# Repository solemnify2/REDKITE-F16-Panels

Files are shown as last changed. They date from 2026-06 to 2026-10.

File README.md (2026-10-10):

# REDKITE F16 PANELS

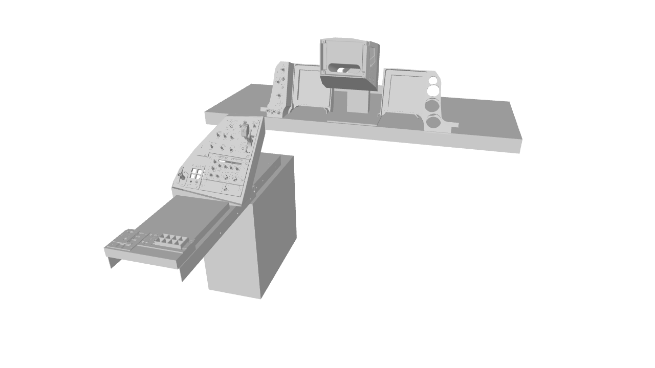
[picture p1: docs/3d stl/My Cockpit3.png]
My Cockpit


VR 전용 F-16 미니멀 데스크핏
**Falcon BMS**(BMS-BIOS)와 **DCS World**(DCS-BIOS) 자동 감지로 패널의 LED 연동

## Design Goals

VR 전용 미니멀 데스크핏을 지향합니다. VR 헤드셋을 쓰고 손을 뻗은 곳에 스위치가 있었으면 하는 생각을 1년 이상 참다가 결국 만들었습니다 ㅠㅠ 실기 1:1 스케일로 제작했습니다. 사용하지 않을 때 쉽게 치울 수 있는 이동식/수납식 구조를 대외적으로 표방(치울지는 모르겠음), 인게임 디스플레이로 충분한 계기류(DED, RWR, 엔진 게이지, HSI 등)는 제작하지 않고 스위치와 LED 위주로 구성했습니다.

## Features

- **Left Aux/MISC Panel 위주로 제작** — 사용 빈도가 높은 Gear, CMDS, TWA, Alt Gear로 구성된 Left Aux Panels과 MISC 패널 위주로 제작
- **이동식/수납식 구조** — Left/Right MFD Enclosure를 독립적으로 미니멀하게 제작하고 ICP 스탠드를 사이에 제작하여 안 쓸 때 MFD 쪽으로 내려 모니터 시야를 확보. 또한, PC 데스크톱 본체 위에 슬라이딩 마운트를 제작하여 Left Aux Console을 거치하고 안 쓸 때 테이블 밑으로 밀어 넣는 구조
- **MCP23017 I2C 확장** — I2C(MCP23017)를 이용하여 새로운 패널을 여러 개 추가 가능. MISC 패널은 MCP23017으로 제작하여 Left Aux Panels의 slave 장치로 동작
- **PWM 백라이트 디밍** — 백라이트가 콕핏 패널의 백미. MOSFET PWM으로 인게임 조명 노브에 연동되는 무단계 밝기 조절. AUX는 USB 3.0 + Step-Up, 콘솔은 별도 12V 어댑터
- **USB Suspend 감지** — PC 절전 시 LED 소등 및 MCU 저전력 모드 진입으로 숙면 지원
- **프로토콜 자동 감지** — BMS-BIOS(바이너리) / DCS-BIOS(바이너리) 자동 판별해서 패널의 LED들을 연동
- **74HC595 시프트 레지스터** — ECM 패널의 S/A/F/T 32개 LED를 3핀으로 구동. 데이지체인이라 칩을 늘려도 핀이 늘지 않음
- **로터리 엔코더** — UHF 백업 무전기의 PRESET 채널과 주파수 5자리를 엔코더 6개로 구현. 1kHz 인터럽트 폴링으로 빠른 회전에도 펄스 유실 없음
- **좌측 콘솔 확장** — 콜드앤다크 스타트에서 쓰는 ECM / ELEC / EPU / AVTR / UHF / ENGINE START / MPO / AUDIO 패널을 두 번째 Teensy로 구성
- **DCS 커버 자동화** — DCS에서 ENG CONT, EPU 스위치 조작 시 커버를 자동으로 열고 닫음 (100ms 선행/후행)

## Devices

독립된 USB 디바이스 2대로 구성됩니다. 각각 별도의 Teensy 4.1과 스케치를 사용하며, Python 브릿지는 VID/PID로 두 대를 동시에 인식해 같은 프레임을 전송합니다.

| 디바이스 | 폴더 | PID | 담당 |
|---|---|---|---|
| **Left Aux + MISC** | `F16_LEFT_AUX_MISC/` | `0x0489` | Gear, CMDS, TWA, Alt Gear, MISC, HMCS, Pedal |
| **Left Console** | `F16_LEFT_CONSOLE/` | `0x048E` | ECM, ELEC, EPU, AVTR, UHF, ENGINE START, MPO, AUDIO 1/2 |

두 스케치 모두 `JOYSTICK_SIZE 64`(Extreme, 128버튼)를 요구하므로 빌드 사이에 `usb_desc.h`를 고칠 필요가 없습니다. PID만 디바이스별로 다르며, 각 스케치가 `#error`로 검증합니다.

## Supported Panels and Input

### Left Aux + MISC (`0x0489`)

| Panel | Type | Description |
|---|---|---|
| Gear | Switch, LED | Landing Gear, Hook, Anti-skid, Landing Light, Gear Warning 등 |
| Alt Gear | Switch | ALT Gear Handle / Reset |
| MISC | Switch, LED (MCP23017) | Master ARM, Laser ARM, RF, Autopilot Pitch/Roll, ECM LED 등 |
| CMDS | Switch, Analog Ladder, LED | RWR, JMR, MWS, JETT, MODE (6-pos), PRGM (5-pos), GO/NO GO/RDY EWS 램프 |
| TWA | Analog Ladder, LED | Threat Warning Aux — Search, Act/Pwr, Low, Power |
| HMCS | Analog | Brightness, Contrast, Symbology 포텐셔미터 3개 |
| Pedal | Analog | Rudder + Left/Right Brake (auto calibration) |

### Left Console (`0x048E`)

| Panel | Type | Description |
|---|---|---|
| ECM | Switch (MCP23017), Analog Ladder, LED (74HC595) | OPR/STBY, XMIT, BIT, RESET + 8버튼 래더 + S/A/F/T 32 LED |
| ELEC | Switch, LED (MCP23017) | MAIN PWR, CAUTION RST + 경고등 8개 |
| EPU | Switch (MCP23017) | OFF / NORM / ON |
| AVTR | Switch (MCP23017) | OFF / AUTO / ON |
| UHF | Switch, **Rotary Encoder ×6**, Analog | FUNCTION(4), MODE(3), SQUELCH, T-TONE, STATUS + PRESET·주파수 5자리 엔코더 + VOL |
| ENGINE START | Switch | JFS (OFF/START1/START2), ENG CONT (PRI/SEC), MAX PWR / NORM / AB RESET, ENG DATA |
| MPO | Switch | Manual Pitch Override |
| AUDIO 1/2 | Analog, Switch (MCP23017) | 볼륨 6개 (COMM CH1/CH2, MSL, THREAT, INTERCOM, ILS) + COMM 1/2 모드 3단 로터리 2개 |

**DX 버튼 61개 / 조이스틱 축 10개**를 사용합니다. DCS에서는 ENG CONT, EPU 커버 자동화용 DX 3개(59~61)가 추가됩니다. 상세 배치는 [docs/PIN_ASSIGNMENT.md](docs/PIN_ASSIGNMENT.md) 참조.

## Hardware

### Panels

패널은 아래 콕핏 빌더 전문 업체에서 구매할 수 있습니다.

- [PC Flights](https://pcflights.com/flight-simulator-cockpit-panels/f-16c-viper-home-cockpit-panels/) — F-16C 패널 전문, 미국/해외 배송 **(본 프로젝트에서 사용한 패널)**

| MISC | Gear | CMDS |
|:----:|:----:|:----:|
| MISC (https://pcflights.com/f-16c-viper-miscellaneous-misc-panel-flight-sim-part/) | Gear (https://pcflights.com/f-16c-viper-landing-gear-panel-flight-simulator-module/) | CMDS (https://pcflights.com/f-16c-viper-cmds-control-panel-module/) |

- [HispaPanel](https://hispapanels.com/tienda/en/20-f-16-fighting-falcon) — 레이저 커팅/각인 패널 키트, 커스텀 제작 가능
- [TEK Creations](https://tekcreations.space/shop/) — LED 백라이트 패널, DCS-BIOS 레디, [Etsy](https://www.etsy.com/shop/TekCreations)에서도 구매 가능

패널은 완제품을 구매하는 대신 3D 프린터로 직접 출력할 수 있습니다. 패널뿐 아니라 구조물(HUD frame 등)도 구할 수 있습니다. 저는 [Cults3D](https://cults3d.com)에서 구했습니다. 아래 참고하세요.

- [Greenisland](https://cults3d.com/en/users/Greenisland/3d-models) — F-16 콕핏 거의 전체 파트 판매
- [Legarsdusofa](https://cults3d.com/en/design-collections/Legarsdusofa/f-16-cockpit-simulator) — F-16 콕핏 거의 전체 파트 판매
- [The_Viper_Project](https://cults3d.com/en/users/The_Viper_Project/3d-models) — 버튼 노브, 스위치 캡, Dsub 캡 등 무료 제공

### Enclosures

`docs/3d stl/` 폴더에 콕핏 패널 인클로저 및 스탠드의 3D 프린트용 STL 파일이 있습니다.
Enclosure는 강도와 가성비를 고려하여 PETG로 제작하였으며, JLC3DP에서는 PETG를 지원하지 않아 PCBWay에서 별도 주문하였습니다.
Stand는 각각 Left/Right Enclosure 뒷면에 부착하는 지지대입니다. 에폭시 접착제로 접합을 권장합니다.
Stand는 두 버전이 있으며, new 버전 사용을 권장합니다.

| Left Stand | Left Stand (new) | Right Stand | Right Stand (new) |
|:----:|:----:|:----:|:----:|
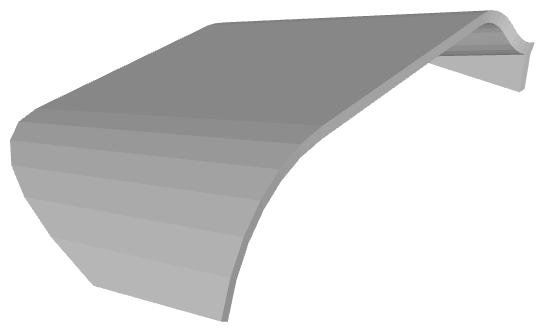
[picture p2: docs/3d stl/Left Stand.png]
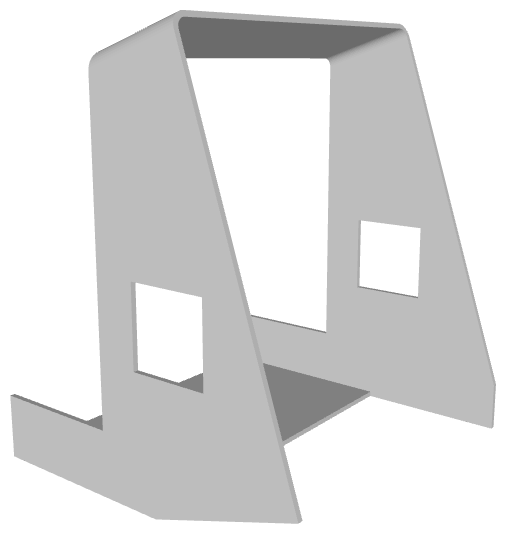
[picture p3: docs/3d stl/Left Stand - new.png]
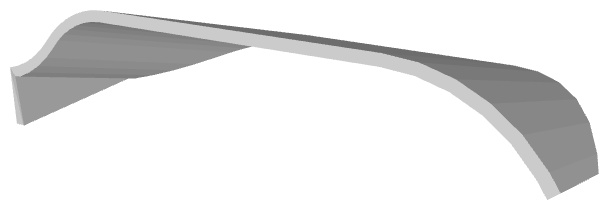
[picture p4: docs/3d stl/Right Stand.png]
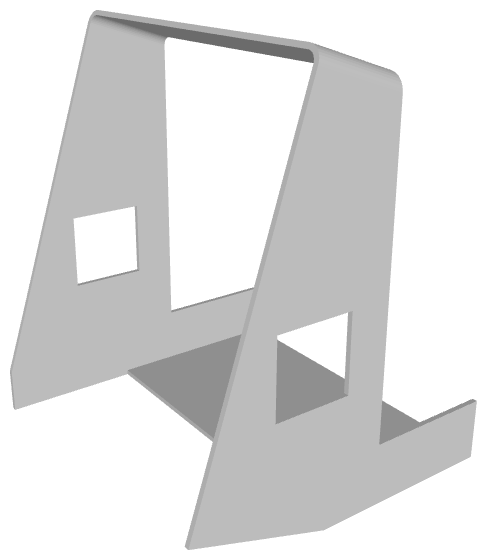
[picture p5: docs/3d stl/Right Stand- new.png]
|  |  |  |  |

| Left Enclosure | Right Enclosure (new) | Enclosure OnePiece |
|:----:|:----:|:----:|
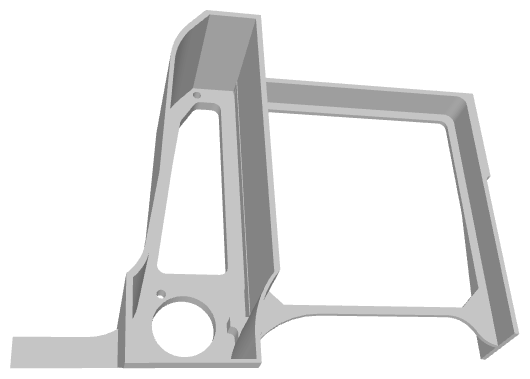
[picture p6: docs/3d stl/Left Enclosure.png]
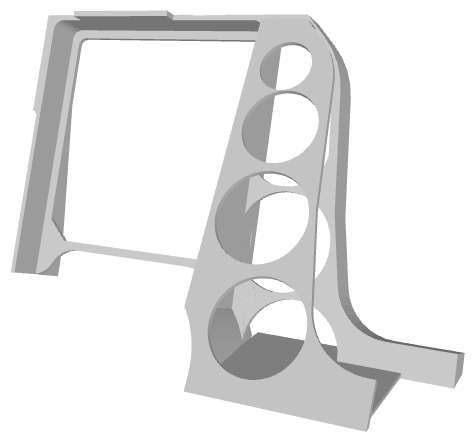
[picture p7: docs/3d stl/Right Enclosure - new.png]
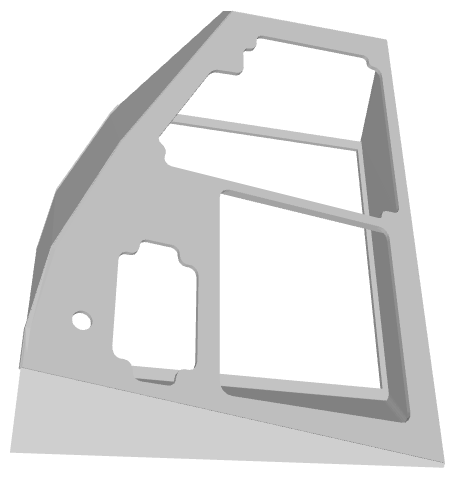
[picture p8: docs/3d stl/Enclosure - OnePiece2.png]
|  |  |  |

> **Note:** Left Enclosure, Right Enclosure의 STL 파일은 Cults3D에서 구매한 모델을 수정하여 제작한 것이므로 저작권 보호를 위해 재배포하지 않습니다. 미리보기 이미지만 참고용으로 포함되어 있습니다.

### MCU

본 프로젝트는 [Teensy 4.1](https://www.pjrc.com/store/teensy41.html)을 사용합니다. 선택 이유:

- **이미 보유하고 있었음** — 가장 큰 이유
- **USB 조이스틱 128버튼 네이티브 지원** — Arduino Mega 등은 USB HID를 지원하지 않아 시리얼 통신 방식으로 제한됨
- **600MHz ARM Cortex-M7** — DCS-BIOS 프로토콜 파싱, LED 제어 등 다중 작업에 충분한 성능
- **VIN 핀을 통한 USB 5V 직접 출력** — 백라이트용 Step-Up 컨버터 전원 공급에 활용

### Components

주요 부품 (AliExpress 주문 기준, 전체 71건):

**스위치류**

| 부품 | 수량 | 비고 |
|---|---|---|
| 토글 스위치 On-Off-On (12mm, 3P) | 20 | |
| 토글 스위치 On-On (12mm, 3P) | 20 | |
| 푸시 스위치 7mm (PBS-110) | 12 | |
| 모멘터리 푸시 스위치 6mm (3핀) | 5 | |
| 택타일 스위치 SMD (6x6x4.3mm) | 20 | |
| 리밋 스위치 (12x6mm) | 10 | |
| 로터리 스위치 SR26 1P12T | 4 | |
| 로터리 스위치 RS16 1P6T / 1P5T | 2 / 2 | |
| 포텐셔미터 10kΩ | 10 | |
| 코리 스위치 | 1 | [HispaPanel](https://hispapanels.com/tienda/en/buttons-encoders/71-korry-type-tactile-switch-momentary.html) |
| 키보드 스위치 (Brown) | 2 | |

**IC / 반도체**

| 부품 | 수량 | 비고 |
|---|---|---|
| MCP23017 I2C I/O Expander | 4 | MISC(AUX) / UHF+AUDIO1 COMM(`0x20`), ELEC+EPU(`0x21`), ECM+AVTR(`0x22`) (콘솔) |
| 74HC595 시프트 레지스터 | 4 | ECM 패널 32 LED 구동 (데이지체인) |
| IRLML6244 N-ch MOSFET | 50 | Step-Up EN 핀 / 백라이트 스위칭 |
| 로터리 엔코더 EC11 (디텐트) | 6 | UHF — PRESET은 20디텐트 권장 |

**LED**

| 부품 | 수량 | 비고 |
|---|---|---|
| 3mm LED Green (백라이트용) | 100 | 고휘도 |
| LED 키트 3mm/5mm Mixed | 300 | Red, Green, Yellow 등 |

**수동 소자**

| 부품 | 수량 | 비고 |
|---|---|---|
| 1/4W 저항 (1K, 4.7K, 10K, 100Ω, 150Ω, 220Ω) | 각 100 | 래더, 풀다운, 풀업 |
| SMD 1206 저항 (220Ω, 2.2K, 10K) | 각 100 | |
| 전해 커패시터 25V (10µF / 100µF) | 각 40 | 바이패스 |
| 세라믹 커패시터 (100nF / 1nF) | 각 100 | 바이패스 |

**커넥터 / 배선**

| 부품 | 수량 | 비고 |
|---|---|---|
| 실리콘 와이어 22AWG 5색 | 50m | |
| Dupont 커넥터 & 점퍼선 | 다수 | 쉘, 핀, F-F 점퍼 |
| Spade 압착 터미널 2.8mm | 200쌍 | 토글 스위치 연결 |
| Pin Header 1x30P | 10 | |
| 수축 튜브 | 750 | |

**모듈 / 기타**

| 부품 | 수량 | 비고 |
|---|---|---|
| Step-Up 컨버터 5V→12V (EN 핀 포함) | 2 | AUX 보드 백라이트 전원 |
| 12V DC 어댑터 (1A) | 1 | **콘솔 보드 백라이트 전용** — LED 40개 때문에 USB 예산 부족 |
| USB 2.0 패널 마운트 커넥터 | 1 | |
| RJ45 패널 마운트 커넥터 / 키스톤 잭 | 7 | 콘솔 보드 케이블 I1, C2, C3, I2, C6, 5 + AUX + MISC |
| Cat5e LAN 케이블 | 7가닥 | **콘솔 보드 신호 배선 전량** — 1, I1/C2/C3, C4/C5, I2/C6, 5 |
| [GX076-30MB](https://www.alibaba.com/product-detail/7-6-Inch-Square-LCD-Display_1601257654342.html) 7.6" Square LCD | 2 | MFD용, Alibaba |
| 자석 15x3mm | 6 | |

상세 주문 내역은 [docs/AliExpress_Orders.xlsx](docs/AliExpress_Orders.xlsx) 참조.

### 소요 비용

| 유형 | 업체 | 내용 | 제품 (USD) | 배송 (USD) |
|---|---|---|----:|----:|
| 패널 | [PC Flights](https://pcflights.com) | MISC / Gear / CMDS 패널 3종 | $133.00 | $30.50 |
| 3D 프린트 (SLA/MJF) | [JLC3DP](https://jlc3dp.com) | 스위치 캡, 노브, LED 레이어, Alt Gear 등 소형 부품 | $63.63 | $20.00 |
| 3D 프린트 (PETG) | [PCBWay](https://www.pcbway.com) | Enclosure, Stand 등 대형 구조물 | $118.75 | ~$50 |
| MCU | [PJRC](https://www.pjrc.com) | Teensy 4.1 | ~$35 | - |
| 전자부품/배선재 | [AliExpress](https://www.aliexpress.com) | MCP23017, 스위치, LED, 저항, 커넥터, 배선재 등 | ~$200 | - |
| 노동력 | - | 약 1달간의 설계, 조립, 프로그래밍 | priceless | - |
| | | **합계** | **~$550** | **~$101** |

**있으면 좋은 것:**

| 유형 | 업체 | 내용 | 제품 | 배송 |
|---|---|---|----:|----:|
| MFD 패널 | [Thrustmaster](https://www.thrustmaster.com/products/mfd-cougar-pack/) | MFD Cougar Pack (2개) | ~$98 | - |
| ICP | [Simgears](https://www.simgears.com/products/f16-icp-se-usb-controller-standalone/) | F16 ICP SE USB Controller | €259 | 별도 |
| MISC 패널 | [TEK Creations](https://www.etsy.com/listing/1829038275/) | F16 MISC Panel Gen3 (백라이트, DCS-BIOS) | A$375 | - |
| Gear 패널 | [TEK Creations](https://tekcreations.space/product/f16-falcon-landing-controller/) | F16 Landing Gear Controller | A$375 | 별도 |
| LCD | [Alibaba](https://www.alibaba.com) | GX076-30MB 7.6" Square LCD (MFD용) x2 | $116 | - |

> 결론: 시간과 노동력을 고려하면 TEK Creations 등 완제품을 사는 게 현명합니다. 직접 만드는 건 취미입니다.

상세 주문 내역: [PCFlights_Orders.xlsx](docs/PCFlights_Orders.xlsx) / [JLC3DP_Orders.xlsx](docs/JLC3DP_Orders.xlsx) / [PCBWay_Orders.xlsx](docs/PCBWay_Orders.xlsx) / [AliExpress_Orders.xlsx](docs/AliExpress_Orders.xlsx)

## Build

### Arduino IDE Setup

1. [Teensyduino](https://www.pjrc.com/teensy/td_download.html) 설치
2. Arduino IDE에서:
   - **Board**: Teensy 4.1
   - **USB Type**: Serial + Keyboard + Mouse + Joystick (복합 디바이스, Windows 자동 인식)
3. 필요 라이브러리:
   - `Wire` (built-in)
   - `Keyboard` (built-in)

### 스위치류와 Teensy 핀 연결

| 보드 | 핀 배치 문서 |
|---|---|
| Left Aux + MISC | [docs/teensy_direct_pins.txt](docs/teensy_direct_pins.txt) |
| Left Console | [docs/PIN_ASSIGNMENT.md](docs/PIN_ASSIGNMENT.md) — 핀표, MCP GPIO 맵, 엔코더, DX 버튼 맵, 패널별 배선, 전원 계통 |

### 저항 래더 (Resistor Ladder)

로터리 스위치(CMDS MODE 6-pos, CMDS PRGM 5-pos)와 TWA 패널 버튼(4개)은 각각 Teensy 아날로그 핀 1개에 저항 래더로 연결합니다. 핀 1개로 여러 버튼을 처리할 수 있어 핀 절약에 효과적입니다.

- 각 포지션마다 **1kΩ 직렬 저항**을 추가하여 고유한 ADC 값을 생성
- **4.7kΩ 풀다운 저항**으로 GND 기준 전압 분배
- ADC 값 = `1023 × 4700 / (k × 1000 + 4700)` (k = 선택된 포지션)
- 소프트웨어에서 tolerance(±25~30) 범위 내 매칭으로 인식
- 사용 핀: A10 (TWA 4버튼), A11 (CMDS MODE 6포지션), A12 (CMDS PRGM 5포지션)

Resistor Ladder 회로도

> `ALLOW_DEBUG = true`로 시리얼 모니터에서 실제 analogRead 값을 확인하고 values[] 배열을 캘리브레이션하세요.

**콘솔 보드의 ECM 래더는 방식이 다릅니다.** PCB가 이미 제작되어 저항값이 고정(10kΩ 체인 + 20kΩ 풀다운)인데, 8단이라 상위 값들의 간격이 좁습니다(FRM 253 / SPL 225 = 28카운트). tolerance 창으로 판별하면 창이 겹쳐 오인식이 나므로 **가장 가까운 값을 고르는 방식(nearest-value)** 에 8회 오버샘플링을 적용했습니다. 창이 겹칠 수 없는 구조라 동시 매칭이 원천적으로 발생하지 않고, 판정 경계(239) 기준 ±14카운트 여유에 노이즈는 ±2 수준입니다.

### MCP23017 패널 추가

Teensy의 다이렉트 핀은 모두 사용 중이므로, 추가 스위치/LED는 MCP23017 I2C 확장으로만 추가할 수 있습니다. MCP23017 하나당 16핀(GPA0–7, GPB0–7)을 제공하며, I2C 주소를 달리하여 최대 8개(0x20–0x27)까지 데이지체인 연결이 가능합니다. 랜선 8중 4핀으로 연결 가능. 기존 쉬프트레지스터 방식은 칩 별로 In/Out이 정해져 있지만 I2C는 칩의 모든 핀을 In/Out으로 설정 가능한 장점이 있음. 또한, 데이지체인 형태로 계속 slave 장치를 추가 가능하므로 teensy에 추가로 핀을 연결할 필요 없음. 향후 콜드앤다크스타트에서 사용하는 손맛을 위한 패널들 (예: ECM, Elec, Snsr, HUD 등) 대응도 마음만 먹으면 가능

```cpp
// MCP23017 패널 스위치 추가 예시 (mcpIdx: MCP 디바이스 번호, pin1: MCP 핀 번호)
{"New Switch",  PNL_MISC,  SW_ON_OFF,  0,  5,  0,  NULL},
//                                      ^   ^
//                               mcpIdx=0  GPA5
```

새 MCP 디바이스를 추가하려면 `mcpDevices[]` 배열에 I2C 주소를 등록하면 됩니다.

### I2C Star 토폴로지 & 핫플러그 보호

MCP23017 패널은 Teensy와 LAN(Cat5e RJ45) 케이블로 연결합니다. 각 패널은 독립 LAN 케이블로 Teensy에 직접 연결하는 **Star 토폴로지**를 사용합니다.

- **Star 연결**: 각 패널이 독립 케이블로 연결되므로, 한 패널의 분리/장애가 다른 패널에 영향을 주지 않음
- **핫플러그 보호**: LAN 커넥터 착탈 시 핀 접촉 순서가 불규칙하므로 보호 회로 필요
  - SDA/SCL 각 100Ω 직렬 저항 (MCP 입력단) — 돌입전류 제한
  - 4.7kΩ × 2 I2C 풀업 저항 — Teensy와 분기점 사이에 배치
  - 10µF + 100nF 바이패스 캡 — MCP23017 VDD 전압 스파이크 흡수
  - RESET 핀 → VDD(3.3V) 직결 — 플로팅 방지
- **I2C 주소**: A0~A2 핀으로 설정, 최대 8개 (0x20~0x27) ([주소 설정표](docs/mcp23017_address.md))
- **상세 사양**: [핫플러그 사양](docs/hotplug_spec.md) / [MISC 패널 사양](docs/misc_panel_spec.md)

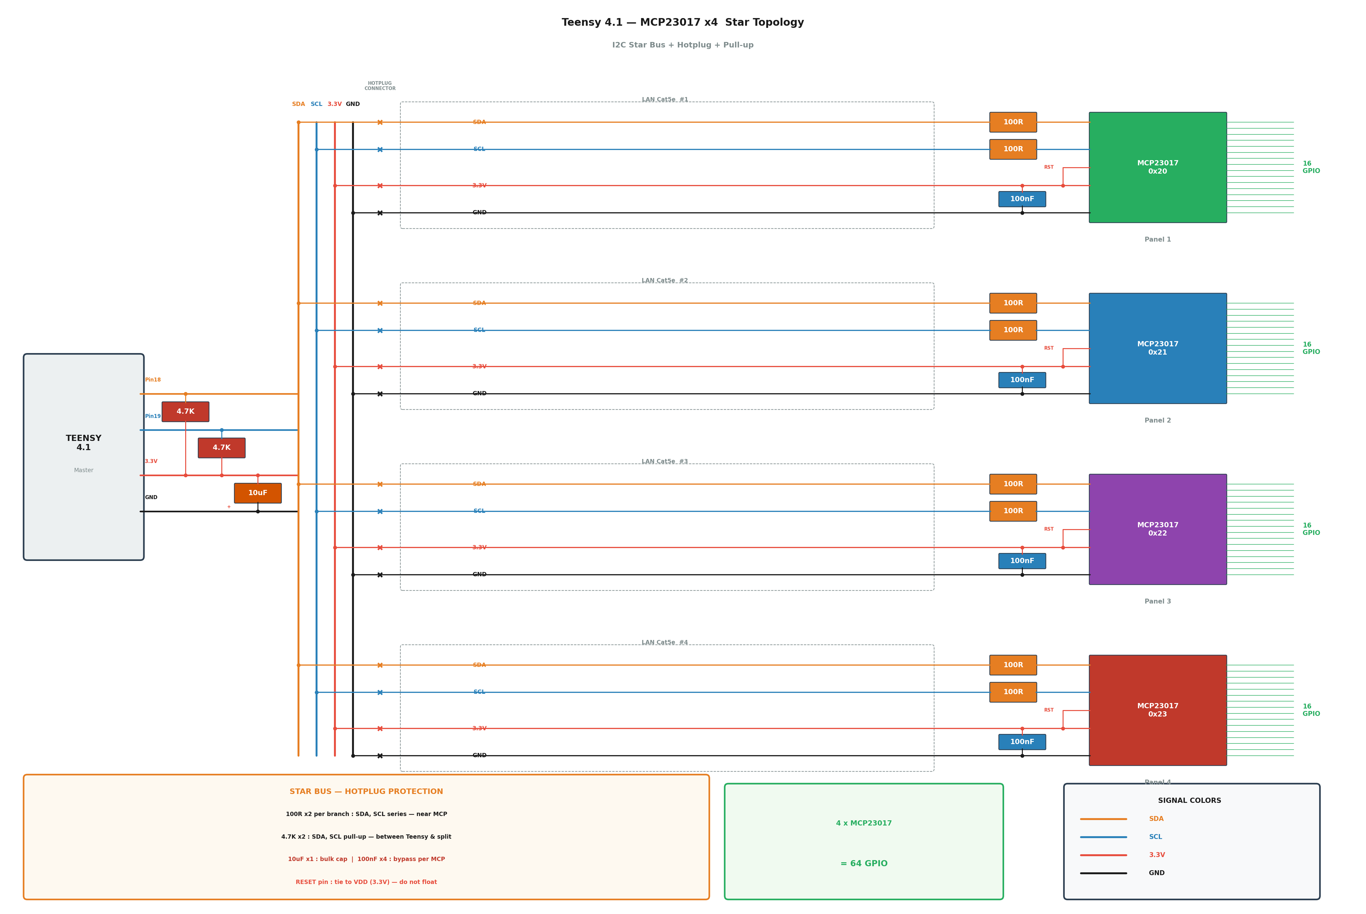
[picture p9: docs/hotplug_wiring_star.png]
I2C Star Topology


### 백라이트

백라이트는 콕핏 패널의 백미이므로 생략할 수 없습니다. **양쪽 보드 모두 MOSFET PWM 디밍**을 지원하며, 인게임 조명 노브에 연동됩니다.

- **전원**:
  - **AUX 보드**: Teensy Vin → Step-Up 컨버터 5V→12V. USB 3.0 전력 예산(900mA) 내 운용
  - **콘솔 보드**: 별도 12V DC 어댑터 (LED 40개로 USB 예산 초과). 어댑터 GND와 Teensy GND를 반드시 연결
- **PWM 디밍**: Teensy pin 13 → 1kΩ → MOSFET Gate, 10kΩ 풀다운. MOSFET Drain←LED-RTN, Source→GND. `analogWrite` 1kHz PWM으로 0~255 무단계 밝기 조절
- **인게임 연동**:
  - BMS: `instrLight` → 브릿지가 `ledBits` byte 2(bits 16~23)로 brightness 0~255 전송
  - DCS: Teensy가 직접 처리. `LIGHT_INST_PNL`(0x4484) 0~65535 → >>8 → PWM 0~255
- **오프라인 수동 제어**:
  - **AUX 보드**: DN LOCK REL을 누른 채 HMCS Symbology 포텐셔미터(A15)로 밝기 조절 (방향 반전)
  - **콘솔 보드**: UHF STATUS를 누른 채 UHF VOL 포텐셔미터(A9)로 밝기 조절
- **LED**: 3V / 20mA 녹색 고휘도 3mm LED
- **회로 구성**: LED 3개 + 220Ω 저항 1개로 구성된 직렬 스트링을 최대 15개까지 병렬로 분산 배치 (20mA × 15 = 300mA @ 12V)
- **패널 구조**: PC Flights 패널은 2중 구조. 전면은 흰색 판넬에 검정 도색 + 글자 흰색 각인, 후면은 투명 패널
- **배치 방법**: 후면 투명 패널 뒤쪽에서 LED를 쏴주면 전면 각인 글자가 빛남. 전력 제한으로 LED 45개 이내로 사용해야 하므로, 후면 패널에 밀착시키지 않고 1~2cm 간격을 두어 빛이 넓게 퍼지도록 배치
- **패널별 배치**: MISC 15개(5스트립) / Gear 18개(6스트립) / CMDS 12개(4스트립), 총 45개(15스트립)

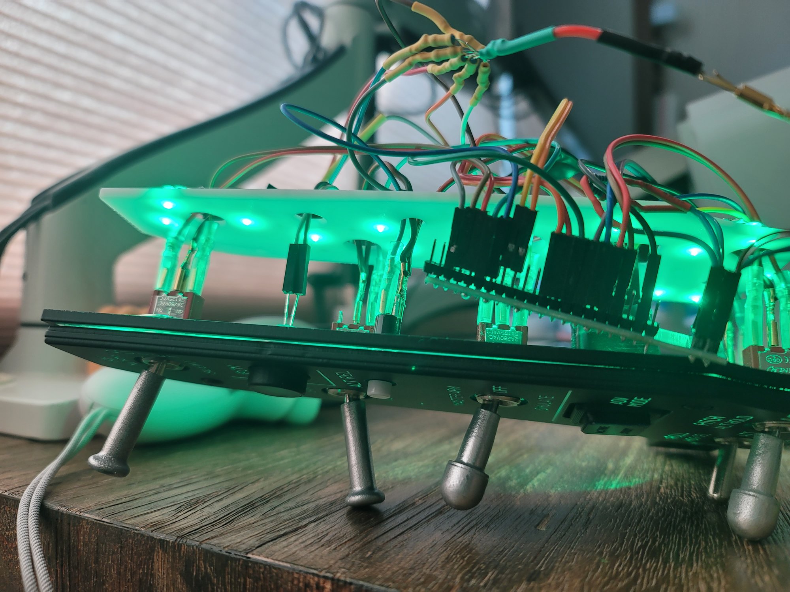
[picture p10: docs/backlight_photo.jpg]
Backlight LED 배치 — 후면 투명 패널에서 1~2cm 간격

- **전력 계산**: Teensy 4.1(~100mA) + MCP23017(~1mA) + 백라이트(300mA @ 12V) 감안하여 USB 3.0 전력 예산(900mA @ 5V) 내에서 운용

> **왜 MOSFET이 필요한가?** AUX 보드: Step-Up EN 핀은 5V 도메인이라 3.3V Teensy GPIO로 직접 제어가 안 됨. 콘솔 보드: 12V 어댑터를 직접 제어할 수단이 필요. 양쪽 모두 N-ch MOSFET(IRLML6244)을 low-side switching으로 사용하며, PWM으로 LED 밝기를 무단계 조절합니다.

> **Note:** EN 핀 특성(GND=ON, Float=OFF)은 Aliexpress에서 구매한 Step-Up 모듈 기준이며, 다른 제조사/모듈은 EN 핀 동작이 다를 수 있습니다. 사용 전 데이터시트를 반드시 확인하세요.

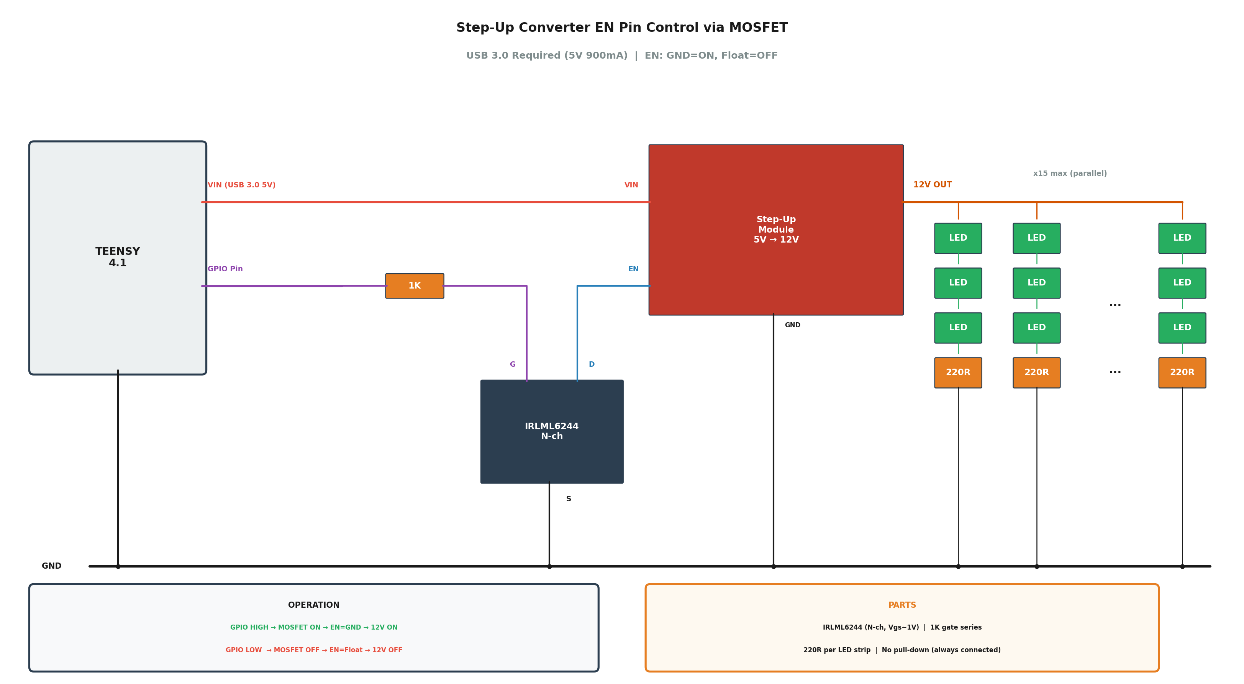
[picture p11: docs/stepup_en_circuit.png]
Step-Up EN Circuit


> COB LED 스트링도 검토했으나, 모든 패널에 두르려면 소모 전력이 높아 별도 전원 공급 없이는 운용이 어려워 포기했습니다.

## 스위치 Customization

스위치/LED 등 하드웨어 변경 시 각 `.ino`의 **HARDWARE CONFIGURATION** 섹션의 config 배열만 수정하면 됩니다. 패널을 비활성화하려면 해당 항목을 주석 처리하면 됩니다. 조이스틱 버튼 번호는 런타임에 자동 재할당됩니다.

| 배열 | 용도 | 보드 |
|---|---|---|
| `switches[]` | 디지털 스위치 (직결 / MCP) | 공통 |
| `analogBtnArrays[]` | 저항 래더 그룹 | 공통 |
| `mcpDevices[]` | MCP23017 I2C 주소 | 공통 |
| `leds[]` | LED (직결 / MCP) | 공통 |
| `pots[]` | 포텐셔미터 → 조이스틱 축 | 공통 |
| `encoders[]` | 로터리 엔코더 | 콘솔 |
| `srMap[]` | 74HC595 논리→물리 출력 리맵 | 콘솔 |

```cpp
// 스위치 추가 예시
const SwitchDef switches[] = {
  // name         panel        type         mcpIdx  pin1  pin2  stateRef
  {"My Switch",   PNL_GEAR,    SW_ON_OFF,      -1,    5,    0,  NULL},
};

// 아날로그 버튼 배열 추가 예시
const AnalogBtnArrayDef analogBtnArrays[] = {
  // groupName    panel      pin  numBtn  btnNames       values         tolerance
  {"My Buttons",  PNL_CMDS,  A11, 4,      myBtnNames,    myBtnValues,   20},
};
```

### Extreme 조이스틱 설정

Windows의 기본 Joystick은 32버튼까지만 지원하지만, Teensyduino의 Extreme Joystick 모드는 128버튼을 지원합니다. AUX 보드가 49버튼, 콘솔 보드가 56버튼을 쓰므로 **두 스케치 모두** 이 모드가 필요합니다. Teensy 빌드 전 `%LOCALAPPDATA%\Arduino15\packages\teensy\hardware\avr\<version>\cores\teensy4\usb_desc.h`에서 `JOYSTICK_SIZE`를 `64`로 변경:

```c
#define JOYSTICK_SIZE         64    //  12 = normal, 64 = extreme joystick
#define PRODUCT_ID            0x0489  // AUX 보드 / 콘솔 보드는 0x048E
```

두 보드가 `JOYSTICK_SIZE`를 공유하므로 빌드 사이에 이 값을 고칠 필요는 없고, **`PRODUCT_ID`만 디바이스에 맞게 바꿔** 빌드합니다. 값이 틀리면 각 스케치의 `#error`가 빌드를 막아줍니다.

> **축은 6개가 아니라 23개입니다.** Extreme 모드는 명명 축 6개(X / Y / Z / Xrotate / Yrotate / Zrotate)에 더해 `Joystick.slider(1..17)`을 제공합니다(`usb_joystick.h`의 `analog16(6..22)`). 콘솔 보드의 볼륨 포트 7개는 명명 축 6개 + `slider(1)`에 배정했으며, 16채널이 남아 있습니다.

조이스틱 버튼은 런타임에 순차 번호가 자동 부여되지만, 인게임 내의 키 매핑은 직접 해주셔야 합니다. 페달은 러더 + 독립 브레이크를 합성하며 자동 캘리브레이션을 지원합니다. 현재 배치는 [docs/joystick.txt](docs/joystick.txt) 참조.

### Left Console 보드 고유 사항

콘솔 보드(`F16_LEFT_CONSOLE/`)는 AUX 보드와 몇 가지가 다릅니다.

**로터리 엔코더 (UHF 6개)**
1kHz `IntervalTimer` ISR에서 쿼드러처를 디코딩하고, 메인 루프가 디텐트를 그대로 CW/CCW DX 버튼 펄스 큐로 배출합니다. 자리 순환·경계 처리(예: 100MHz 자리는 2~3뿐)는 BMS 가 자체적으로 하므로 스케치는 값을 추적하지 않습니다. 엔코더는 **MCP23017에 올릴 수 없습니다** — I2C 폴링 주기로는 펄스를 놓칩니다. 이 때문에 메인 루프도 50ms → **10ms(100Hz)** 로 올렸습니다.

**저항 래더 — 최근접값 판별**
ECM 8버튼 래더는 PCB가 이미 제작되어 값이 고정(10kΩ 체인 + 20kΩ 풀다운)인데, 상위 두 값(FRM 253 / SPL 225)의 간격이 28카운트뿐입니다. tolerance 창 방식으로는 겹쳐서 오인식이 나므로 **가장 가까운 값을 고르는 방식**으로 판별하고 8회 오버샘플링을 적용했습니다. 판정 경계가 239라 ±14카운트 여유가 확보되고, 노이즈는 ±2 수준입니다.

**74HC595 32/32 소진**
칩을 추가하면 BMS-BIOS 프레임의 `srData` 32비트를 넘으므로 `BB_FRAME_PAYLOAD`, 양쪽 `BmsBiosParser.h`, `bmsbios_bridge.py`를 모두 수정해야 합니다.

**백라이트는 별도 12V 어댑터 + PWM 디밍**
콘솔 보드는 인디케이터 LED만 40개(ECM 32 + ELEC 8)라 USB 900mA로는 백라이트까지 감당이 안 됩니다. 12V 어댑터를 따로 쓰고 Step-Up 컨버터는 생략합니다. **어댑터 GND와 Teensy GND를 단일점으로 반드시 연결**해야 MOSFET 게이트 기준이 성립합니다. 오프라인 수동 밝기 조절은 UHF STATUS + UHF VOL 포텐셔미터로 가능합니다.

배선·핀 배치 상세는 [docs/PIN_ASSIGNMENT.md](docs/PIN_ASSIGNMENT.md) 참조.

### Upload

Arduino IDE에서 해당 `.ino`를 열고 Upload합니다. `usb_desc.h`의 `PRODUCT_ID`가 보드와 일치하는지 먼저 확인하세요.

| 보드 | 파일 | PRODUCT_ID |
|---|---|---|
| Left Aux + MISC | `F16_LEFT_AUX_MISC.ino` | `0x0489` |
| Left Console | `F16_LEFT_CONSOLE.ino` | `0x048E` |

## DCS-BIOS / BMS-BIOS Protocol Support

스위치/버튼 입력은 USB Joystick으로 직접 전달되지만, LED 상태는 시뮬레이터에서 받아와야 합니다. Python 브릿지가 시뮬레이터의 내부 데이터를 읽어 시리얼로 Teensy에 전송하고, Teensy는 수신된 프로토콜(BMS-BIOS / DCS-BIOS)을 자동 감지하여 LED를 제어합니다. 시뮬레이터 전환 시 타임아웃(AUX 6초 / 콘솔 3초) 후 자동 재감지. 오프라인(시뮬레이터 미연결) 시 AUX 보드는 Landing Gear 스위치 상태에 따라 Gear LED 3개를 시뮬레이션하고(2초 딜레이), 기어 상태 변경 시 Gear Warn LED를 5초간 점등합니다. 콘솔 보드는 오프라인에서 모든 LED를 소등합니다.

### Falcon BMS (BMS-BIOS)

- 바이너리 프로토콜, `0xAA 0xBB` sync 2바이트로 자동 감지
- Python 브릿지(`tools/bmsbios_bridge.py`)가 BMS 공유 메모리에서 LED 상태를 읽어 Teensy로 전송
- BMS 실행 전에 bridge를 먼저 실행해도 안전 (공유 메모리 생성하지 않음)
- 브릿지는 VID/PID로 **두 디바이스를 동시에 인식**해 각각에 맞는 프레임을 보냅니다
- 프레임: `sync(2) + ledBits(4) + srData(4) + uhfFreq(4) + uhfPreset(1) + XOR(1)` = 16바이트. AUX는 `ledBits`만, 콘솔은 `ledBits` + `srData`(ECM 32 LED) + `uhfFreq`/`uhfPreset`(UHF 7-seg)를 사용하며, **ledBits byte 2(bits 16~23)가 백라이트 brightness**로 양쪽 공통입니다
- 사용법:
  ```
  pip install pyserial
  python tools/bmsbios_bridge.py                          # 두 디바이스 자동 감지
  python tools/bmsbios_bridge.py COM4:AUX COM5:CONSOLE    # 수동 지정
  python tools/bmsbios_bridge.py --debug                  # LightBits 실시간 출력
  ```

> **참고 — Why not F4ToSerial?** 이전 버전에서는 [F4ToSerial](https://github.com/Music-Junky/F4ToSerial)을 사용했으나, F4TS는 Teensy의 다이렉트 핀만 지정 가능하고 MCP23017 등 I2C 확장 핀을 지원하지 않는 문제가 있어 BMS-BIOS로 대체했습니다. 부수적으로 JSON 파싱 오버헤드 제거, ArduinoJson 의존성 제거 등 소소한 이점도 기대할 수 있습니다 (체감 차이는 미지수). DCS-BIOS/BMS-BIOS 프로토콜을 직접 구현했으므로 향후 DCS나 BMS 업데이트로 주소/오프셋이 변경되면 직접 수정이 필요하지만, 소스가 명확하고(`docs/protocol_reference.txt` 참조) 수정 범위도 작아 큰 부담은 아닙니다. 게다가 [Claude Code](https://claude.com/claude-code)도 있으니 든든합니다.

### DCS World (DCS-BIOS)

- 바이너리 프로토콜, `0x55` sync 4바이트로 자동 감지
- DCS-BIOS 설치 및 UDP 브릿지(`tools/dcsbios_bridge.py`) 필요
- 사용법:
  ```
  pip install pyserial
  python ../tools/dcsbios_bridge.py             # COM port auto-detect
  ```

## Project Structure

```
REDKITE-F16-Panels/
├── F16_LEFT_AUX_MISC/             # Teensy 4.1 (PID 0x0489)
│   │                              #   Gear, CMDS, TWA, Alt Gear, MISC, HMCS, Pedal
│   ├── F16_LEFT_AUX_MISC.ino
│   ├── BiosHandler/               # DcsBiosParser.h / BmsBiosParser.h
│   ├── CLAUDE.md
│   └── name.c
├── F16_LEFT_CONSOLE/              # Teensy 4.1 (PID 0x048E)
│   │                              #   ECM, ELEC, EPU, AVTR, UHF,
│   │                              #   ENGINE START, MPO, AUDIO 1/2
│   ├── F16_LEFT_CONSOLE.ino
│   ├── BiosHandler/
│   ├── Display/                   # Max7219Display.h (UHF 7-seg)
│   ├── CLAUDE.md
│   └── name.c
├── tools/                         # Python 브릿지 (BMS/DCS → Teensy)
│   ├── bmsbios_bridge.py          #   VID/PID로 두 디바이스 동시 인식
│   ├── dcsbios_bridge.py
│   ├── reset_joystick_name.bat
│   └── backup_to_synology.ps1
├── docs/                          # 배선도, 사양서, 프로토콜 참조
│   ├── PIN_ASSIGNMENT.md          #   콘솔 보드 핀·배선 상세 (표)
│   ├── LEFT_CONSOLE_PIN_TREE2.md  #   콘솔 보드 연결 트리 (케이블·패널 단위)
│   ├── LEFT_AUX_MISC_LAN_WIRING.md #  AUX↔MISC LAN 배선도
│   ├── backlight_spec.md / hotplug_spec.md / stepup_en_control.md
│   └── 3d stl/                    #   3D 프린트용 STL 파일
├── CLAUDE.md                      # Claude Code 가이드
└── README.md
```

## License

This project is licensed under the [MIT License](LICENSE).

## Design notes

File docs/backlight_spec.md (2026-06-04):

# Backlight System Specification

## Power Budget
- USB 3.0: 900mA @ 5V
- Teensy 4.1 consumption: ~100mA @ 5V
- MCP23017: ~1mA (negligible)
- LED backlight budget: ~800mA @ 5V
- MT3608 step-up: 5V → 12V (85% efficiency)
- Max 12V output: 283mA → **18 strips (54 LEDs) safe limit**

## LED Strip
- Green 3V 20mA high-brightness LED
- 3-series per strip + 220Ω resistor
- Strip current: (12V - 9V) / 220Ω = **13.6mA** (68% of 20mA rating)
- Strip count is freely adjustable (parallel connection, no circuit change needed)

| Resistor | Current | Brightness |
|---|---|---|
| 150Ω | 20.0mA | 100% (max, shorter life) |
| **220Ω** | **13.6mA** | **68% (recommended)** |
| 330Ω | 9.1mA | 45% |
| 470Ω | 6.4mA | 32% |
| 1kΩ | 3.0mA | 15% |

## Current Configuration
- Main panel: 10 strips (30 LEDs) = 136mA @12V
- MISC panel: 3 strips (9 LEDs) = 41mA @12V
- Total: 13 strips, 39 LEDs, 177mA @12V, ~538mA @5V

## MT3608 Step-Up Converter
- Input: 5V (Teensy VIN)
- Output: 12V
- Switching frequency: 1.2MHz
- Place 2~3cm away from Teensy MCU and I2C lines (EMI)
- Do not route I2C lines parallel to/over inductor
- Input/output caps included on module

---

## Circuit Options (4 variants)

### Option A: PWM Dimming (MOSFET ×2)
**File:** `backlight_circuit.png` / `draw_circuit.py`

- MOSFET: IRLML6344 (SOT-23, N-ch, Vgs(th) ~1V) × 2
- 1 per panel, low-side switching
- Gate: 1kΩ series resistor
- Pull-down: 10kΩ Gate→GND (hotplug protection)
- PWM dimming: Teensy Pin 0 → `analogWrite(0, 0~255)`
- MISC panel 3.3V: AMS1117-3.3 (12V → 3.3V) + 10µF × 2

| Pin | Signal | Pair |
|-----|---|---|
| 1 | SDA | Pair 1 (Orange) |
| 2 | GND | Pair 1 |
| 3 | SCL | Pair 2 (Green) |
| 6 | GND | Pair 2 |
| 4 | 12V | Pair 3 (Blue) |
| 5 | 12V | Pair 3 |
| 7 | PWM | Pair 4 (Brown) |
| 8 | GND | Pair 4 |

**Pros:** 0~100% 무단계 디밍, PWM+GND 꼬임쌍으로 간섭 없음
**Cons:** 부품 가장 많음 (AMS1117 + caps + MOSFET ×2 + 저항 ×4)

### Option B: Always ON (No MOSFET)
**File:** `backlight_circuit_no_pwm.png` / `draw_circuit_no_pwm.py`

- MOSFET 없음, LED cathode → GND 직결
- 밝기는 저항값으로만 결정 (고정)
- MISC panel 3.3V: AMS1117-3.3 (12V → 3.3V) + 10µF × 2

| Pin | Signal | Pair |
|-----|---|---|
| 1 | SDA | Pair 1 (Orange) |
| 2 | GND | Pair 1 |
| 3 | SCL | Pair 2 (Green) |
| 6 | GND | Pair 2 |
| 4 | 12V | Pair 3 (Blue) |
| 5 | 12V | Pair 3 |
| 7 | GND | Pair 4 (Brown) |
| 8 | GND | Pair 4 |

**Pros:** 단순, MOSFET/게이트 저항 6개 절감
**Cons:** 디밍 불가

### Option C: MCP23017 Only (No Backlight)
**File:** `backlight_circuit_mcp_only.png` / `draw_circuit_mcp_only.py`

- 백라이트 없음, MT3608 불필요, AMS1117 불필요
- Teensy 3.3V (250mA max) → LAN → MCP23017 직접 구동
- 100nF 바이패스 캡만 필요

| Pin | Signal | Pair |
|-----|---|---|
| 1 | SDA | Pair 1 (Orange) |
| 2 | GND | Pair 1 |
| 3 | SCL | Pair 2 (Green) |
| 6 | GND | Pair 2 |
| 4 | 3.3V | Pair 3 (Blue) |
| 5 | 3.3V | Pair 3 |
| 7 | GND | Pair 4 (Brown) |
| 8 | GND | Pair 4 |

**Pros:** 최소 부품, 최소 전력
**Cons:** 백라이트 없음

### Option D: 12V Backlight + 3.3V Direct (No AMS1117)
**File:** `backlight_circuit_12v_3v3.png` / `draw_circuit_12v_3v3.py`

- MT3608 12V → 양쪽 패널 백라이트 (always on)
- Teensy 3.3V → LAN → MCP23017 직접 구동 (AMS1117 불필요)
- MOSFET 없음 (PWM 신호선 자리에 3.3V 배정)

| Pin | Signal | Pair |
|-----|---|---|
| 1 | SDA | Pair 1 (Orange) |
| 2 | GND | Pair 1 |
| 3 | SCL | Pair 2 (Green) |
| 6 | GND | Pair 2 |
| 4 | 12V | Pair 3 (Blue) |
| 5 | 12V | Pair 3 |
| 7 | 3.3V | Pair 4 (Brown) |
| 8 | GND | Pair 4 |

**Pros:** AMS1117 + 전해캡 2개 절감, 백라이트 있음
**Cons:** PWM 디밍 불가 (LAN 핀 부족), 3.3V+GND 꼬임쌍 (전용 GND 있음)

---

## Option Comparison

| | A: PWM | B: Always ON | C: MCP Only | D: 12V+3.3V |
|---|---|---|---|---|
| Backlight | O (dimmable) | O (fixed) | X | O (fixed) |
| MT3608 | O | O | X | O |
| AMS1117 | O | O | X | **X** |
| MOSFET | 2 | 0 | 0 | 0 |
| PWM dimming | O | X | - | X |
| Parts count | Most | Medium | Least | Medium-Low |
| 5V draw | ~538mA | ~538mA | ~100mA | ~538mA |

## MISC Panel Components by Option

### Option A (PWM)
| Part | Value | Purpose |
|---|---|---|
| MCP23017 | 0x20 | I2C GPIO expander |
| AMS1117-3.3 | SOT-223 | 12V → 3.3V LDO |
| Electrolytic cap | 10µF ×2 (25V) | AMS1117 in/out |
| Resistor | 100Ω ×2 | I2C hotplug protection |
| Resistor | 220Ω ×3 | LED current limiting |
| MOSFET | IRLML6344 | Backlight switching |
| Resistor | 1kΩ | MOSFET gate series |
| Resistor | 10kΩ | MOSFET gate pull-down |

### Option D (12V+3.3V, recommended)
| Part | Value | Purpose |
|---|---|---|
| MCP23017 | 0x20 | I2C GPIO expander |
| Ceramic cap | 100nF | MCP23017 bypass |
| Resistor | 100Ω ×2 | I2C hotplug protection |
| Resistor | 220Ω ×3 | LED current limiting |

## Main Panel Components (backlight options)
| Part | Value | Purpose |
|---|---|---|
| MT3608 module | 5V→12V | Step-up converter |
| Resistor | 220Ω ×10 | LED current limiting |
| MOSFET (Option A only) | IRLML6344 | PWM switching |
| Resistor (Option A only) | 1kΩ | Gate series |
| Resistor (Option A only) | 10kΩ | Gate pull-down |

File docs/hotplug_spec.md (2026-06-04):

# LAN Hotplug & PWM Specification

## Overview
Teensy 4.1 ↔ MISC Panel (MCP23017) 간 LAN (Cat5e RJ45) 연결 시 핫플러그 보호 및 PWM 디밍 설계.
3.3V와 12V는 완전 분리 (3.3V = MCP 전용, 12V = 백라이트 전용).

## Hardware

### I2C Protection
| Part | Value | Location | Purpose |
|---|---|---|---|
| Resistor | 100Ω | SDA 직렬 (MISC 입력단) | 돌입전류 제한, 래치업 방지 |
| Resistor | 100Ω | SCL 직렬 (MISC 입력단) | 돌입전류 제한, 래치업 방지 |

- LAN 연결 시 핀 접촉 순서가 불규칙 → 100Ω이 과도 전류 제한
- I2C 100~400kHz 통신에 영향 거의 없음

### Power Protection (MCP23017 VDD)
| Part | Value | Location | Purpose |
|---|---|---|---|
| Electrolytic cap | 10µF (10V+) | MCP23017 VDD-GND | 핫플러그 전압 스파이크 흡수 |
| Ceramic cap | 100nF | MCP23017 VDD-GND (핀 근접) | 고주파 노이즈 필터 |

#### Connection
```
3.3V ──┬──┬── MCP23017 VDD
       │  │
     10µF 100nF
       │  │
GND  ──┴──┴── MCP23017 GND
```
- 두 캡 모두 3.3V-GND 사이 병렬
- 100nF을 MCP23017 핀에 더 가까이 배치
- 10µF 전해캡은 극성 주의 (+를 3.3V 쪽)

### Capacitor Sizing
| 용량 | 판단 |
|---|---|
| 10µF | 충분 (MCP23017 ~1mA) |
| 47µF | AMS1117 사용 시 12V PWM 리플 흡수용 (현재 불필요) |
| 100µF | 과잉 — 충전 돌입전류 증가, 이점 없음 |

현재 3.3V/12V 완전 분리 → 12V PWM 리플이 MCP에 영향 없음 → **10µF이면 충분**

## Software

### MCP23017 재초기화
```cpp
// 주기적으로 MCP23017 연결 확인 (예: 500ms 간격)
Wire.beginTransmission(0x20);
if (Wire.endTransmission() == 0) {
    // MCP23017 detected → reinitialize
    mcp.begin();
}
```
- LAN 분리 후 재연결 시 MCP23017 레지스터가 리셋됨
- I2C 응답 확인 후 재초기화 필요

## Not Required
| Part | Reason |
|---|---|
| TVS diode (P6KE15A) | 3.3V/12V USB 전원 수준, 과전압 파괴 위험 없음 |
| Ferrite bead | 저전류(~1mA), 노이즈 문제 없음 |
| 100µF+ 대용량 캡 | 과잉, 돌입전류만 증가 |
| Gate pull-down 10kΩ | MOSFET 없는 경우 불필요 (Option D) |

---

## PWM Dimming

### Overview
- Teensy Pin 0 → `analogWrite(0, 0~255)` → MOSFET Gate → LED 밝기 조절
- MOSFET: IRLML6344 (SOT-23, N-ch, Vgs(th) ~1V, logic-level)
- Low-side switching: LED cathode(−) → MOSFET Drain, MOSFET Source → GND

### Teensy 4.1 PWM
- Pin 0: PWM 출력 가능 (FlexPWM)
- 기본 주파수: ~4.482kHz
- 해상도: 8-bit (0~255)
- `analogWrite(0, 0)` = OFF, `analogWrite(0, 255)` = 최대 밝기

### MOSFET Circuit (per panel)
```
Teensy Pin0 ──→ 1kΩ ──→ Gate (G)
                         │
                        10kΩ (pull-down)
                         │
                        GND

12V → 220Ω → LED×3 → Drain (D)
                      Source (S) → GND
```

| Part | Value | Purpose |
|---|---|---|
| MOSFET | IRLML6344 (SOT-23) | N-ch logic-level, Vgs(th) ~1V |
| Resistor | 1kΩ | Gate 직렬 — 스위칭 링잉 방지 |
| Resistor | 10kΩ | Gate pull-down — 핫플러그 시 LED 오동작 방지 |

### Gate Pull-down 10kΩ 역할
- LAN 미연결 또는 핫플러그 순간 Gate가 플로팅 → MOSFET 의도치 않게 ON
- 10kΩ이 Gate를 GND로 끌어내려 OFF 상태 유지
- **핫플러그 보호의 일부** — PWM 사용 시 필수

### PWM via LAN Cable
- PWM 신호를 LAN Pair 4 (Brown)로 MISC 패널에 전송 가능
- PWM+GND 꼬임쌍 → I2C/12V와 간섭 없음 (Cat5e 크로스토크 억제)
- PWM ~4.5kHz, I2C 100~400kHz — 주파수 대역 다름, 간섭 미미
- MOSFET 게이트 구동 전류 거의 0 → 방사 노이즈 최소

### PWM 사용 시 LAN Pin Assignment
| Pin | Signal | Pair | Note |
|-----|---|---|---|
| 1 | SDA | Pair 1 (Orange) | 100Ω 직렬 보호 |
| 2 | GND | Pair 1 | SDA 리턴 |
| 3 | SCL | Pair 2 (Green) | 100Ω 직렬 보호 |
| 6 | GND | Pair 2 | SCL 리턴 |
| 4 | 12V | Pair 3 (Blue) | 백라이트 전용 |
| 5 | 12V | Pair 3 | 백라이트 전용 |
| 7 | PWM | Pair 4 (Brown) | MOSFET Gate 구동 |
| 8 | GND | Pair 4 | PWM 리턴 |

- PWM 사용 시 3.3V를 LAN으로 보낼 수 없음 (핀 부족)
- → MISC 3.3V는 AMS1117 (12V→3.3V)로 생성 필요

### PWM 미사용 시 LAN Pin Assignment
| Pin | Signal | Pair | Note |
|-----|---|---|---|
| 1 | SDA | Pair 1 (Orange) | 100Ω 직렬 보호 |
| 2 | GND | Pair 1 | SDA 리턴 |
| 3 | SCL | Pair 2 (Green) | 100Ω 직렬 보호 |
| 6 | GND | Pair 2 | SCL 리턴 |
| 4 | 12V | Pair 3 (Blue) | 백라이트 전용 |
| 5 | 12V | Pair 3 | 백라이트 전용 |
| 7 | 3.3V | Pair 4 (Brown) | MCP23017 전용 |
| 8 | GND | Pair 4 | 3.3V 리턴 |

- AMS1117 불필요 — Teensy 3.3V 직접 전송
- MOSFET / 1kΩ / 10kΩ 불필요

### MCP23017은 PWM 불가
- MCP23017 GPIO는 디지털 ON/OFF만 가능
- I2C 통신 속도 한계로 소프트웨어 PWM도 불가 (~1kHz 미만)
- PWM 디밍은 반드시 Teensy 하드웨어 PWM 핀 사용

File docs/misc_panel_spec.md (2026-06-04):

# MISC Panel Specification (F-16C Block 50)

## Overview
우측 콘솔 3개 패널 (HUD Remote, SNSR PWR, LIGHTING)을 Teensy 4.0 Slave로 구동.
메인 패널 Teensy 4.1 (Master)과 LAN (Cat5e) I2C로 연결.

## Panel Summary

| Panel | Switches | Digital Pins | Analog Pins |
|---|---|---|---|
| HUD Remote | 8 × 3-pos toggle | 16 | 0 |
| SNSR PWR | 4 toggle | 4 | 0 |
| LIGHTING | 5 knobs (pot) | 0 | 5 |
| **Total** | | **20** | **5** |

## HUD Remote Control Panel
8 × 3-position toggle switches (각 2핀, 총 16 디지털 입력)

| # | Switch | Positions |
|---|---|---|
| 1 | SCALES | VV/VAH / VAH / OFF |
| 2 | FP MARKER | ATT/FPM / FPM / OFF |
| 3 | DED DATA | DED / PFLD / OFF |
| 4 | DEPRESS RET | STBY / PRI / OFF |
| 5 | SPEED | CAS / TAS / GND SPD |
| 6 | ALT | RADAR / BARO / AUTO |
| 7 | BRT | DAY / AUTO BRT / NIGHT |
| 8 | TEST | STEP / ON / OFF |

## SNSR PWR Panel
4 toggle switches (4 디지털 입력)

## LIGHTING Panel
5 potentiometers (5 아날로그 입력)

## Controller: Teensy 4.0

| Resource | Available | Used | Remaining |
|---|---|---|---|
| Digital GPIO | 24+ | 20 | 4+ |
| Analog (ADC) | 14 | 5 | 9 |

- I2C Slave (address TBD, e.g. 0x10)
- Teensy 4.1 (Master)과 LAN Cat5e로 연결
- 3.3V 전원: Teensy 4.1에서 LAN Pair 4로 직접 공급

## LAN Connection (from Main Panel)

| Pin | Signal | Pair |
|-----|---|---|
| 1 | SDA | Pair 1 (Orange) |
| 2 | GND | Pair 1 |
| 3 | SCL | Pair 2 (Green) |
| 6 | GND | Pair 2 |
| 4 | 12V | Pair 3 (Blue) |
| 5 | 12V | Pair 3 |
| 7 | 3.3V | Pair 4 (Brown) |
| 8 | GND | Pair 4 |

- 12V: 백라이트 LED 전용
- 3.3V: Teensy 4.0 전원 (Teensy 4.1에서 직접 공급, AMS1117 불필요)
- I2C: 100Ω × 2 직렬 보호 (hotplug)

## Hotplug Protection
- 100Ω × 2 (SDA, SCL 직렬)
- 10µF + 100nF (3.3V VDD bypass, 병렬)
- See `hotplug_spec.md` for details

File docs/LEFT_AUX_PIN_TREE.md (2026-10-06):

# F16 LEFT AUX + MISC — 핀 연결 트리

`F16_LEFT_AUX_MISC/` 스케치의 물리 배선도입니다.
핀 번호·버튼 번호는 `.ino`의 config 배열에서 그대로 가져온 값입니다.

- **Board**: Teensy 4.1 (헤더 핀 0–41)
- **USB**: PID `0x0487`, `JOYSTICK_SIZE 64` (128버튼) — 콘솔 장치(`0x048E`)와 헤더 공유
- **I2C**: `Wire` — SDA = pin 18, SCL = pin 19 @ 100kHz, MCP23017 1장 (`0x20`, MISC 패널)
- **DX 버튼 49, 축 6**, 메인 루프 20Hz

케이블 이름(C1~C6, M1, I1)은 이 문서에서 부여한 명명입니다.
관련 문서: [misc_panel_spec.md](misc_panel_spec.md) · [backlight_spec.md](backlight_spec.md) ·
[hotplug_spec.md](hotplug_spec.md) · [stepup_en_control.md](stepup_en_control.md)

---

## 케이블 구성

```
  F-16 LEFT AUX + MISC — cable tree     solid box = Teensy/panel,  dashed box = MCP module
  (블록 배치는 연결 관계 기준입니다 — 실제 콘솔 패널 배치가 아닙니다)

        ┌───────────────────────────────────────────────────────────────┐
        │ Teensy 4.1    LEFT AUX + MISC    PID 0x0487                   │
        └───┬─────────────────────────────────────────────────────────┬─┘
            │ I1 (I2C, LAN)                                           │ C1~C7
        ┌╌╌╌┬╌╌╌╌╌╌╌╌╌╌╌┐           ┌───────────────────────┐         │
        ┆ MCP#0  0x20   ├─ M1(x14) ─┤ MISC                  │         │
        └╌╌╌╌╌╌╌╌╌╌╌╌╌╌╌┘           │ SW x11  LED x3        │         │
                                    └───────────────────────┘         │
                                    ┌───────────────────────┐         │
                                    │ GEAR                  ├─C1(x17)─┤
                                    │ SW x13  LED x4        │         │
                                    └───────────────────────┘         │
                                    ┌───────────────────────┐         │
                                    │ CMDS                  ├─C2(x10)─┤
                                    │ SW x8  LADDER x2      │         │
                                    │ LED x6 (GO/NOGO/RDY)  ├─C7(x6)──┤
                                    └───────────────────────┘         │
                                    ┌───────────────────────┐         │
                                    │ TWA                   ├─C3(x5)──┤
                                    │ LADDER x1  LED x4     │         │
                                    └───────────────────────┘         │
                                    ┌───────────────────────┐         │
                                    │ ALT GEAR   SW x2      ├─C4(x2)──┤
                                    └───────────────────────┘         │
                                    ┌───────────────────────┐         │
                                    │ HMCS       POT x3     ├─C5(x3)──┤
                                    └───────────────────────┘         │
                                    ┌───────────────────────┐         │
                                    │ PEDALS     POT x2     ├─C6(x2)──┘
                                    └───────────────────────┘

  I2C             I1 Teensy(18/19) > 0x20 — 스타 토폴로지, LAN (hotplug_spec.md 준용)
  Teensy direct   C1 GEAR   C2 CMDS   C3 TWA   C4 ALT GEAR   C5 HMCS   C6 PEDALS
                  C7 CMDS 램프 — 헤더가 아니라 하단 SD 패드(42~47)에서 SD 확장 케이블로 인출
  MCP > panel     M1 0x20 > MISC (모듈-패널 하니스)
  12V             backlight: pin 0 PWM > MOSFET > 스텝업 5V→12V (backlight_spec.md, not drawn)

  xN = 신호선 수 (3.3V/GND 제외)   SW = switch GPIO 수   LADDER = resistor ladder   POT = potentiometer
```

| 케이블 | 구간 | 내용 | 신호 수 |
|---|---|---|---|
| **I1** | Teensy → MCP `0x20` | I2C (SDA 18, SCL 19) | 2 (LAN, +3.3V/GND) |
| **M1** | MCP `0x20` → MISC 패널 | 스위치 GPIO 11 + LED 3 | 14 |
| **C1** | Teensy → GEAR 패널 | 스위치 GPIO 13 + LED 4 (Nose/Left/Right/Warn) | 17 |
| **C2** | Teensy → CMDS 패널 | 스위치 8 + 래더 2 (MODE, PRGM) | 10 |
| **C3** | Teensy → TWA 패널 | 래더 1 + LED 4 | 5 |
| **C4** | Teensy → ALT GEAR | Handle, Reset | 2 |
| **C5** | Teensy → HMCS | 포트 3 (Brightness / Contrast / Symbology) | 3 |
| **C6** | Teensy → 페달 | 포트 2 (Left / Right) | 2 |
| **C7** | Teensy 하단 SD 패드 → CMDS 램프 | LED 6 (GO 1 / NO GO 2 / RDY 3) | 6 (+GND, LAN 7심) |
| 12V | 스텝업 → 백라이트 | 게이트는 핀 0 PWM | 2 |

콘솔 장치와 달리 MCP가 1장뿐이라 **I2C는 체인이 아닌 스타(단일 링크)**입니다.
MCP 단선 시 **GEAR WARN LED가 점등**되어 패널에서 바로 알 수 있고 (콘솔에는 없는 표시등),
500ms 간격으로 재접속을 시도합니다.

---

## Teensy 4.1 물리 핀 배열

핀 순서는 PJRC 핀아웃 카드([`teensy/card11a_rev4_web.pdf`](teensy/card11a_rev4_web.pdf)) 기준.
**양쪽 열 모두 24포지션**, 오른쪽 열의 핀 13과 41 사이에 GND가 하나 들어갑니다.

```
  CABLE   SIGNAL                PIN      PIN   SIGNAL                CABLE
                                  ┌──── USB ────┐
  ---   GND                  ─────┤ ○         ○ ├─────  Vin                  ---
  C4    ALTGEAR RST           0 ──┤ ○         ○ ├──     GND                  ---
  C1    DN LOCK REL           1 ──┤ ○         ○ ├──     3V3                  ---
  C1    HORN SILENCER         2 ──┤ ○         ○ ├── 23  CMDS FL       (A9)  C2
  C1    LANDING LIGHT 1       3 ──┤ ○         ○ ├── 22  CMDS CH       (A8)  C2
  C1    LANDING LIGHT 2       4 ──┤ ○         ○ ├── 21  CMDS O2       (A7)  C2
  C1    STORE CAT             5 ──┤ ○         ○ ├── 20  CMDS O1       (A6)  C2
  C1    ANTI SKID 1           6 ──┤ ○         ○ ├── 19  I2C SCL       (A5)  I1
  C1    ANTI SKID 2           7 ──┤ ○         ○ ├── 18  I2C SDA       (A4)  I1
  C1    BRAKES CHANNEL        8 ──┤ ○         ○ ├── 17  CMDS RWR      (A3)  C2
  C1    GND JETT ENABLE       9 ──┤ ○         ○ ├── 16  CMDS JMR      (A2)  C2
  C1    EMER JETTISON        10 ──┤ ○         ○ ├── 15  CMDS MWS      (A1)  C2
  C1    HOOK                 11 ──┤ ○         ○ ├── 14  CMDS JETT     (A0)  C2
  C1    GEAR WARN LED        12 ──┤ ○         ○ ├── 13  BACKLIGHT [!]LED    12V
  ---   3.3V                 ─────┤ ○         ○ ├─────  GND                  ---
  C3    TWA LADDER    (A10)  24 ──┤ ○         ○ ├── 41  PEDAL RIGHT  (A17)  C6
  C2    CMDS MODE LDR (A11)  25 ──┤ ○         ○ ├── 40  PEDAL LEFT   (A16)  C6
  C2    CMDS PRGM LDR (A12)  26 ──┤ ○         ○ ├── 39  HMCS SYMBOL  (A15)  C5
  C5    HMCS BRIGHT   (A13)  27 ──┤ ○         ○ ├── 38  HMCS CONTRAST(A14)  C5
  C1    LANDING GEAR UP      28 ──┤ ○         ○ ├── 37  TWA ACT LED         C3
  C1    LANDING GEAR DN      29 ──┤ ○         ○ ├── 36  TWA SEARCH LED      C3
  C1    NOSE GEAR LED        30 ──┤ ○         ○ ├── 35  TWA LOW LED         C3
  C1    LEFT GEAR LED        31 ──┤ ○         ○ ├── 34  TWA POWER LED       C3
  C1    RIGHT GEAR LED       32 ──┤ ○         ○ ├── 33  ALTGEAR HANDLE      C4
                                  └─────────────┘

  [!] pin 13 is shared with the Teensy on-board LED. Used as an OUTPUT here,
      so the on-board LED simply mirrors the backlight state (same as LEFT_CONSOLE).

  pin 27 conflict resolved: Gear Warn LED moved to pin 12.
      pin 27 (A13) is now HMCS Brightness only.
```

### 하단 SD 패드 — CMDS 램프 (C7)

헤더 42핀이 모두 차 있어 **CMDS 램프 6개는 하단 microSD 패드에서 뽑습니다.**
SD 확장 케이블을 끼우면 납땜 없이 6신호 + 3.3V + GND 가 한 번에 나옵니다
(LEFT_CONSOLE 의 UHF 디스플레이와 같은 방식). SD 카드는 쓰지 않으므로 충돌이 없습니다.

| microSD 핀 | 신호 | Teensy 핀 | 용도 |
|---|---|---|---|
| 1 | DAT2 | **47** | CMDS RDY 3 |
| 2 | CD/DAT3 (CS2) | **44** | CMDS NO GO 2 |
| 3 | CMD (MOSI2) | **43** | CMDS NO GO 1 |
| 4 | VDD | 3.3V | (미사용 — LED 는 핀에서 직접 구동) |
| 5 | CLK (SCK2) | **45** | CMDS RDY 1 |
| 6 | VSS | GND | LED 공통 캐소드 |
| 7 | DAT0 (MISO2) | **42** | CMDS GO |
| 8 | DAT1 | **46** | CMDS RDY 2 |

> 확장 케이블 제품마다 패드 번호 표기가 다를 수 있으니, 연결 후 `ALLOW_DEBUG`
> 또는 LED 를 하나씩 켜 보며 매핑을 확인하세요. 순서가 다르면 `leds[]` 의 핀 번호만 바꾸면 됩니다.

---

## MCP23017 모듈 물리 핀 배열

### MCP #0  `0x20` — MISC 패널 실장

```
   LONG EDGE HEADER : single row, 20 pins
   -----------------------------------------
    1  PA7  ECM LED
    2  PA6  -- spare --
    3  PA5  RF pos2
    4  PA4  RF pos1
    5  PA3  LASER ARM
    6  PA2  ALT REL
    7  PA1  MASTER ARM pos2
    8  PA0  MASTER ARM pos1
    9  GND  GND
   10  VCC  3.3V
   11  PB0  ADV STANDBY LED
   12  PB1  ADV ACTIVE LED
   13  PB2  ADV MODE
   14  PB3  ROLL AP pos1
   15  PB4  ROLL AP pos2
   16  PB5  PITCH AP pos1
   17  PB6  PITCH AP pos2
   18  PB7  -- spare --
   19  GND  GND
   20  VCC  3.3V

   ADDRESS JUMPER (3 rows x 2 cols)      [ VCC | GND ]
        A0  ------------------------> GND
        A1  ------------------------> GND
        A2  ------------------------> GND
```

> **주소 점퍼 = 공장 출하 그대로** (A0/A1/A2 전부 GND) → `0x20`.
> 여유 GPIO 는 **PA6, PB7** 두 개입니다.
> 스위치는 전부 입력(내부 풀업), LED 3개(PA7, PB0, PB1)는 출력입니다.

---

## CMDS 램프 (GO / NO GO / RDY)

LED **6개를 Teensy 핀에 1:1 직결**합니다. 드라이버 IC 가 없습니다.
BMS 신호는 3개뿐이라, 브릿지가 NO GO 비트를 LED 2개에, RDY 비트를 LED 3개에 **같은 값으로** 내려보냅니다.
그래서 그룹은 항상 함께 켜지면서도, 펌웨어 쪽에서는 LED 하나하나가 독립 제어 가능한 상태로 남습니다.

| 램프 | LED | Teensy 핀 | `leds[]` 인덱스 | BMS `lightBits2` (offset 124) |
|---|---|---|---|---|
| GO | 1 | 42 | 11 | `Go` `0x40` |
| NO GO | 2 | 43, 44 | 12, 13 | `NoGo` `0x80` |
| RDY | 3 | 45, 46, 47 | 14, 15, 16 | `Rdy` `0x200` |

### 결선

```
   Teensy 42 ──[ R ]──►├── GO
   Teensy 43 ──[ R ]──►├── NO GO 1
   Teensy 44 ──[ R ]──►├── NO GO 2        LED 는 핀이 소스(HIGH = 점등),
   Teensy 45 ──[ R ]──►├── RDY 1          캐소드는 전부 GND 공통
   Teensy 46 ──[ R ]──►├── RDY 2
   Teensy 47 ──[ R ]──►├── RDY 3
                        │
   SD GND ──────────────┴───────── GND
```

LED 마다 **개별 직렬저항**을 답니다. 3.3V 구동이므로

  R = (3.3V − Vf) / I ≈ (3.3 − 2.0) / 8mA ≈ 160Ω → **180Ω** (적색 기준)

밝으면 330~470Ω 으로 올리면 됩니다. 핀당 8mA, 6개 합쳐 약 48mA 로
Teensy 4.1 GPIO 한계(핀당 연속 10mA 권장) 안에 들어옵니다.

> **LED 색 주의** — Vf 가 3.0V 를 넘는 고휘도 녹색·청색은 3.3V 로 제대로 켜지지 않습니다.
> 기존 GEAR·TWA LED 와 같은 종류(3.3V 직결로 동작하는 것)를 쓰세요.
> 굳이 고Vf LED 를 써야 하면 5V + ULN2003A 싱크 드라이버 경로가 필요합니다.

### 케이블

신호 6 + GND = **7심**이라 LAN 케이블 한 가닥에 들어갑니다.

> DCS-BIOS 는 아직 이 램프를 구동하지 않습니다 (BMS 전용). DCS 주소 맵을 확인한 뒤 `DcsBiosParser.h` 에 추가하면 됩니다.

---

## DX 버튼 맵 (49 / 128)

버튼 번호는 `switches[]` → `analogBtnArrays[]` 순서로 런타임에 자동 배정됩니다.

| 버튼 | 패널 | 신호 |
|---|---|---|
| 1–2 | MISC | RF |
| 3 | MISC | Laser ARM |
| 4 | MISC | ALT REL |
| 5–6 | MISC | Master ARM |
| 7 | MISC | ADV MODE |
| 8–9 | MISC | Roll AP |
| 10–11 | MISC | Pitch AP |
| 12 | GEAR | EMER Jettison |
| 13 | GEAR | Store CAT |
| 14 | GEAR | Horn Silencer |
| 15–16 | GEAR | Landing Light |
| 17 | GEAR | Hook |
| 18–19 | GEAR | Landing Gear UP / DN |
| 20 | GEAR | DN LOCK REL (콤보 모디파이어 겸용) |
| 21 | GEAR | GND JETT ENABLE |
| 22–23 | GEAR | ANTI SKID |
| 24 | GEAR | BRAKES Channel |
| 25–31 | CMDS | RWR, JMR, MWS, O1, O2, CH, FL |
| 32 | CMDS | JETT |
| 33 | ALT GEAR | Handle |
| 34 | ALT GEAR | Reset |
| 35–38 | TWA | 래더 — ACT/PWR, SEARCH, ALT, SYS PWR |
| 39–44 | CMDS | MODE 래더 — 1~6 |
| 45–49 | CMDS | PRGM 래더 — BIT, 1~4 |

---

## 조이스틱 축 (6 / 23)

| 축 | 신호 | 핀 |
|---|---|---|
| X | HMCS Brightness | 27 (A13) |
| Y | HMCS Contrast | 38 (A14) |
| Z | HMCS Symbology | 39 (A15) |
| Xrotate | Left Brake | 40 (A16) |
| Yrotate | Right Brake | 41 (A17) |
| Zrotate | Rudder | 좌우 페달 조합으로 계산 |

페달은 브레이크/러더 겸용 — Landing Light UP 또는 양 페달 동시 압력으로 브레이크 모드 전환.
캘리브레이션 리셋: 양 페달 최대 + EMER Jettison 2초.

---

## 리소스 사용

| 항목 | 값 |
|---|---|
| **Teensy 헤더 핀** | **42 / 42** (여유 없음) |
| **하단 SD 패드** | **6 / 6** (42~47 = CMDS 램프) |
| ├ 아날로그 입력 | 8 / 18 (래더 3 + HMCS 3 + 페달 2) — A0~A9 는 CMDS 스위치·I2C 가 디지털로 점유 |
| └ 여유 핀 | 없음 |
| **MCP23017 GPIO** | 14 / 16 (여유 PA6, PB7) |
| LED | 17 (GEAR 4 + TWA 4 + MISC 3 + CMDS 6) |
| **DX 버튼** | **49 / 128** |
| 조이스틱 축 | 6 / 23 |
| I2C | `Wire`(18/19) 100kHz, `0x20` 1장 |
| 메인 루프 | 20Hz (50ms) |

---

## 시공 체크리스트

| # | 항목 |
|---|---|
| 1 | ~~핀 27 충돌~~ **해결됨** — Gear Warn LED 를 핀 12 로 이설. 핀 27(A13)은 HMCS Brightness 전용 |
| 2 | ~~핀 13 확인~~ **해결됨** — 백라이트 출력으로 변경. 온보드 LED가 백라이트 상태를 표시 (LEFT_CONSOLE과 동일). ALT GEAR Reset은 핀 0으로 이설 |
| 3 | **래더 캘리브레이션** — TWA·CMDS MODE·PRGM 은 백라이트 ON/OFF 두 세트(`values[]` / `valuesBlOn[]`)를 각각 보정. `ALLOW_DEBUG = true` 로 실측 |
| 4 | **I2C 핫플러그 보호** — SDA/SCL 직렬 100Ω, 보드 3.3V에 10µF + 100nF ([hotplug_spec.md](hotplug_spec.md)). 단선 시 GEAR WARN 점등, 500ms 재접속 |
| 5 | **MCP 주소 점퍼** — 출하 상태 그대로 (`0x20`) |
| 6 | **백라이트** — 핀 0 PWM → MOSFET → 5V→12V 스텝업 ([backlight_spec.md](backlight_spec.md), [stepup_en_control.md](stepup_en_control.md)). 오프라인 수동 제어: DN LOCK REL 누른 채 Landing Light 조작 |
| 7 | **스위치 배선** — 전부 액티브 로우 + 내부 풀업 (공통 단자 GND) |
| 8 | **CMDS 램프** — 하단 SD 확장 케이블 → LED 6개 직결(각 180Ω, 캐소드 GND 공통). 확장 케이블 핀 매핑을 실측 확인하고, Vf 3.0V 이상 LED 는 쓰지 말 것 |

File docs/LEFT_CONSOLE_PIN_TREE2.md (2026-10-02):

# F16 LEFT CONSOLE — 핀 연결 트리

`F16_LEFT_CONSOLE/` 스케치의 물리 배선도입니다.
핀 번호·버튼 번호는 `.ino`의 config 배열에서 그대로 가져온 값입니다.

USB: PID `0x048E`, `JOYSTICK_SIZE 64`.

| 보드 | 구성 | 핀 | DX 버튼 | 축 |
|---|---|---|---|---|
| Teensy 4.1 | 전 패널 + UHF 엔코더 6 + POT 10 + SW 6 | 40 / 42 | 58 | 10 |

표 형식 상세 배치는 [PIN_ASSIGNMENT.md](PIN_ASSIGNMENT.md) 참조.

---

## 케이블 구성

```
  F-16 LEFT CONSOLE — cable tree     solid box = Teensy/panel,  dashed box = MCP module
  (블록 배치는 연결 관계 기준입니다 — 실제 콘솔 패널 배치가 아닙니다)

        ┌───────────────────────────────────────────────────────────────┐
        │ Teensy    STAGE_T40: 4.0  /  STAGE_T41: 4.1                   │
        └───┬─────────────────────────────────────────────────────────┬─┘
            │ I1 (I2C x8)                                             │ C1~C6
            │                       ┌───────────────────────┐         │
            │                       │ ENGINE START + MPO    ├─C1(x9)──┤
            │                       │ JFS x2  ENG CONT  MPO │         │
            │                       │ AB RST ENGDATA MAXPWR │         │
            │                       │ RUN LED               │         │
            │                       └───────────────────────┘         │
            │                                                         │
        ┌╌╌╌┬╌╌╌╌╌╌╌╌╌╌╌┐           ┌───────────────────────┐         │
        ┆ MCP#0  0x20   ├─ C7(x8) ──┤ UHF                   ├─C13(x3)─┤
        ┆               ├─────┐     │ POT x1 (VOL)  ENC x6  ├─C2(x8)──┤
        └╌╌╌┬╌╌╌╌╌╌╌╌╌╌╌┘     │ C8  │ SW x10                ├─C3(x8)──┤
            │ I2(x8)          │(x9) │ 7SEG x8 (MAX7219)     ├─C14(x5)─┤
            │                 │     └───────────────────────┘         │
            │                 │     ┌───────────────────────┐         │
            │                 ├─────┤ AUDIO 1       POT x6  ├─C4(x8)──┤
            │                 │     │ COMM MODE rotary x2   │         │
            │                 │     └───────────────────────┘         │
            │                 │     ┌───────────────────────┐         │
            │                 └─────┤ AUDIO 2  POT x3 SW x2 ├─C5(x5)──┤
            │                       └───────────────────────┘         │
        ┌╌╌╌┬╌╌╌╌╌╌╌╌╌╌╌┐           ┌───────────────────────┐         │
        ┆ MCP#1  0x21   ├─ C9(x13) ─┤ ELEC   SW x3  LED x8  │         │
        ┆               ├─C10(x7)┐  └───────────────────────┘         │
        └╌╌╌┬╌╌╌╌╌╌╌╌╌╌╌┘        │  ┌───────────────────────┐         │
            │ I3(x8)             └──┤ EPU    SW x2  LED x3  │         │
            │                       └───────────────────────┘         │
        ┌╌╌╌┬╌╌╌╌╌╌╌╌╌╌╌┐           ┌───────────────────────┐         │
        ┆ MCP#2  0x22   ├─ C11(x7) ─┤ ECM   SW x6  LED x32  ├─C6(x8)──┘
        ┆               ├─C12(x3)┐  │ LADDER x8             │
        └╌╌╌╌╌╌╌╌╌╌╌╌╌╌╌┘        │  └───────────────────────┘
                                 │  ┌───────────────────────┐
                                 └──┤ AVTR   SW x2          │
                                    └───────────────────────┘

  I2C chain       I1 Teensy>0x20   I2 0x20>0x21   I3 0x21>0x22   (single bus, daisy-chain)

  Teensy direct   C1 ENGINE+MPO    C2 UHF VOL + ENC x3    C3 UHF ENC x3 (T41 only)
                  C4 AUDIO 1 (x6)  C5 AUDIO 2 (x3)        C6 74HC595 3wire + ECM ladder
                  C13 UHF T-TONE + SQUELCH + STATUS
  MCP > panel     C7 0x20>UHF      C8 AUDIO1·2>0x20  C9 0x21>ELEC  C10 0x21>EPU
                  C11 0x22>ECM     C12 0x22>AVTR
  12V             backlight harness, daisy-chained across all panels (not drawn)

  SW=switch  ENC=rotary encoder  POT=potentiometer  LADDER=resistor ladder
```

| 케이블 | 구간 | 내용 | 선 수 |
|---|---|---|---|
| **I1** | Teensy → MCP `0x20` | I2C 체인 시작 | 8선 (LAN) |
| **I2** | MCP `0x20` → MCP `0x21` | I2C 체인 | 8선 (LAN) |
| **I3** | MCP `0x21` → MCP `0x22` | I2C 체인 | 8선 (LAN) |
| **C1** | Teensy → ENGINE START | JFS ×2, ENG CONT, MPO, RUN LED, AB RST, ENG DATA, MAX PWR | 9선 |
| **C2** | Teensy → UHF 패널 | **POT 1개** (VOL) + 엔코더 3 (10MHz, 1MHz, 0.1MHz) | 8선 (LAN) |
| **C3** | Teensy → UHF 패널 | 엔코더 3 (PRESET, 100MHz, 0.025MHz) | 8선 (LAN) |
| **C4** | Teensy → AUDIO 1 | **POT 6개** (COMM CH1, COMM CH2, SECURE, MSL, TF, THREAT) | 8선 (LAN) |
| **C5** | Teensy → AUDIO 2 | **POT 3개** (INTERCOM, TACAN, ILS) | 5선 |
| **C6** | Teensy → ECM 패널 | 74HC595 3선 + ECM 저항 래더 1선 (핀 35~38) | 8선 (LAN) |
| **C7** | MCP `0x20` → UHF 패널 | FUNCTION 4, MODE 3 (=7, PB1~7) + GND | 8선 | 없음 |
| **C8** | AUDIO 1·2 → MCP `0x20` | COMM 1/2 모드 로터리 (PA2~7) + HOT MIC·CIPHER (PA0/PA1) | 9선 | 없음 |
| **C14** | Teensy(SD/SPI2) → UHF 디스플레이 | MAX7219 보드 J1 — +5V, GND, DIN(43), CLK(45), CS(44) | 5선 |
| **C13** | Teensy → UHF 패널 | **UHF T-TONE, SQUELCH, STATUS** (핀 34/33/41) ⚠ 신설 | 4선 |
| **C9** | MCP `0x21` → ELEC 패널 | 스위치 3 (PB0~2) + LED 8 (PA0~7) | 13선 | 없음 |
| **C10** | MCP `0x21` → EPU 패널 | 스위치 2 (PB6~7) + LED 3 (PB3~5) | 7선 | 없음 |
| **C11** | MCP `0x22` → ECM 패널 | ECM 스위치 6 → PB2~PB7 | 7선 | 없음 |
| **C12** | MCP `0x22` → AVTR 패널 | AVTR 스위치 2 → PA6/PA7 | 3선 | 없음 |
| 12V | 어댑터 → 백라이트 | 전 패널 데이지체인 | 2선 | 없음 |

선 수에는 3.3V / GND 가 포함되어 있습니다.

### 토폴로지

| 구분 | 케이블 | 성격 |
|---|---|---|
| Teensy 직결 | `C1`~`C6` | MCP 를 거칠 수 없는 신호 (맨 아래 **「MCP 를 거칠 수 없는 신호」** 참조). 패널마다 독립 배선 |
| I2C 체인 | `I1`→`I2`→`I3` | MCP 3장을 한 줄로 연결 |
| MCP ↔ 패널 | `C7`~`C12` | MCP 모듈에서 바로 옆 패널로 가는 짧은 하니스 (저속 신호뿐이라 리본·낱선 무방) |

LAN 이 필요한 것은 I2C(`I1`~`I3`)와 아날로그·고속선(`C2` `C3` `C6`)뿐입니다.

> **MCP 를 한 기판(확장보드)에 모으지 않습니다.** 실제 콘솔 배치상 `0x22`(ECM·AVTR)과
> `0x21`(ELEC·EPU)이 콘솔의 반대편 끝에 있어, 한 기판에 모으면 어느 한쪽
> 팬아웃이 길어집니다. 그래서 담당 패널 옆에 각각 두고 I2C 로 체인합니다.
> 덕분에 **`C6` 가 통과 배선이 아니라 ECM 직결**이 됩니다 (배선 요령은 **「케이블 C6」** 절).

---

### I2C 체인

Teensy 의 SDA·SCL 한 쌍에서 출발해 MCP 3장을 **한 줄로 꿰는 단일 버스**입니다.
브레이크아웃 모듈의 **2열 7핀 헤더**(한 열로 받고 다른 열로 넘김)가 이 용도입니다.

```
  Teensy ──I1---> MCP#0 0x20 ──I2---> MCP#1 0x21 ──I3---> MCP#2 0x22
  SDA/SCL        next to UHF       next to ELEC       next to ECM
                 C7 > UHF          C9  > ELEC        C11 > ECM
                 C8 < AUDIO 1      C10 > EPU         C12 > AVTR
```

> **버스는 하나입니다.** 풀업도 버스 전체에 대해 한 번만 계산합니다
> (모듈 온보드 4.7kΩ ×3 병렬 ≈ **1.57kΩ**).

> **체인의 대가** — 한 링크가 끊기면 그 **하류 전체**가 버스에서 사라집니다.
> `I1` 이 빠지면 MCP 3장 모두, `I2` 가 빠지면 `0x21`·`0x22` 두 장이 죽습니다.
> 스케치는 **매 루프 I2C 응답을 검사**해(`mcpReadPorts()`) 실패한 칩을 분리 처리하고
> 500ms 마다 재접속을 시도합니다. 이때 그 칩의 스위치는 **전부 릴리즈 상태**로 읽히고
> (`mcpPortCache = 0xFFFF`), `0x21` 의 LED 11개는 꺼진 채 남습니다.
>
> ⚠ **패널에 보이는 경고는 없습니다.** LEFT_AUX 와 달리 콘솔에는 단선 표시등이 없어
> 시리얼 로그(`[MCP@0x2X] ... NOT DETECTED`)로만 알 수 있습니다. 재접속 시 `OLAT` 이
> 0으로 초기화되므로 다음 BMS 프레임(하트비트 약 1초)까지 LED 가 꺼져 있습니다.
> 커넥터 체결을 시공 시 확인하십시오.

> **얻는 것** — 분기 스터브가 없어 반사가 사라지고 총 배선 길이도 짧아집니다.
> Star 구성(3m ×2 = 6m) → 체인(2m + 2m + 0.3m ≈ 4.3m) 으로 줄어
> 버스 용량 약 350pF → **약 265pF**, 라이즈타임 465ns → **약 352ns**.
> 그래도 400kHz 규격(300ns)은 못 맞추므로 `MCP_I2C_CLOCK` 은 **100kHz 유지**입니다.

신호별 Teensy 핀 번호는 아래 **물리 핀 배열**,
MCP 쪽 배치는 그 다음 **MCP23017 모듈 물리 핀 배열**,
DX 버튼 번호는 [PIN_ASSIGNMENT.md](PIN_ASSIGNMENT.md) 를 보십시오.

---

## Teensy 4.1 — 물리 핀 배열

핀 순서는 PJRC 핀아웃 카드([`teensy/card11a_rev4_web.pdf`](teensy/card11a_rev4_web.pdf))
에서 좌표를 추출해 검증했습니다. **양쪽 열 모두 24포지션**이며,
왼쪽 열의 **핀 13과 41 사이에 GND가 하나** 들어갑니다.

> ⚠ **이 그림은 바닥면(납땜면)에서 본 배치입니다** — 기판을 뒤집어 놓고 배선할 때
> 보이는 그대로라 좌우가 PJRC 핀아웃 카드(부품면 기준)와 **반대**입니다.
> 부품면에서 확인할 때는 좌우를 뒤집어 읽으십시오.

```
  ▼ BOTTOM VIEW (기판을 뒤집어 본 모습)

  CABLE   SIGNAL                PIN      PIN   SIGNAL                CABLE
                                  ┌──── USB ────┐
  ---   Vin                  ─────┤ ○         ○ ├─────  GND                  ---
  ---   GND                     ──┤ ○         ○ ├──  0  ENC PRESET  A      C3
  ---   3V3                     ──┤ ○         ○ ├──  1  ENC PRESET  B      C3
  C2    UHF VOL       (A9)   23 ──┤ ○         ○ ├──  2  ENC 100M    A      C3
  C4    AUDIO1 COMM1  (A8)   22 ──┤ ○         ○ ├──  3  ENC 100M    B      C3
  C4    AUDIO1 COMM2  (A7)   21 ──┤ ○         ○ ├──  4  ENC 10M     A      C2
  C4    AUDIO1 SECURE (A6)   20 ──┤ ○         ○ ├──  5  ENC 10M     B      C2
  C4    AUDIO1 MSL    (A5)   19 ──┤ ○         ○ ├──  6  ENC 1M      A      C2
  C4    AUDIO1 TF     (A4)   18 ──┤ ○         ○ ├──  7  ENC 1M      B      C2
  C4    AUDIO1 THREAT (A3)   17 ──┤ ○         ○ ├──  8  ENC 0.1M    A      C2
  C5    AUDIO2 INTCOM (A2)   16 ──┤ ○         ○ ├──  9  ENC 0.1M    B      C2
  C5    AUDIO2 TACAN  (A1)   15 ──┤ ○         ○ ├── 10  ENC 0.025M  A      C3
  C5    AUDIO2 ILS    (A0)   14 ──┤ ○         ○ ├── 11  ENC 0.025M  B      C3
  12V   BACKLIGHT [!]LED     13 ──┤ ○         ○ ├── 12  -- spare --        ---
  ---   GND                  ─────┤ ○         ○ ├─────  3.3V                 ---
  C13   UHF STATUS   (A17)  41 ──┤ ○         ○ ├── 24  I2C SCL2    (A10)  I1
  C1    MPO           (A16)  40 ──┤ ○         ○ ├── 25  I2C SDA2    (A11)  I1
  ---   -- spare --  (A15)  39 ──┤ ○         ○ ├── 26  JFS RUN LED (A12)  C1
  C6    ECM LADDER    (A14)  38 ──┤ ○         ○ ├── 27  JFS pin1    (A13)  C1
  C6    74HC595 ST_CP        37 ──┤ ○         ○ ├── 28  JFS pin2           C1
  C6    74HC595 SH_CP        36 ──┤ ○         ○ ├── 29  ENG CONT           C1
  C6    74HC595 DS           35 ──┤ ○         ○ ├── 30  AB RESET           C1
  C13   UHF T-TONE           34 ──┤ ○         ○ ├── 31  ENG DATA           C1
  C13   UHF SQUELCH          33 ──┤ ○         ○ ├── 32  MAX POWER          C1
                                  └─────────────┘

  [!] pin 13 is shared with the Teensy on-board LED. Used as an OUTPUT here,
      so the on-board LED simply mirrors the backlight state (same as T40).
```

**엔코더 쌍은 모두 같은 엣지에 있습니다.** Teensy 4.1 의 두 엣지는 `0–12`+`24–32` 와
`13–23`+`33–41` 입니다 (위 바닥면 그림에서는 각각 **오른쪽 열**, **왼쪽 열**).
엔코더 6개가 `0–11` 을 **패널 손잡이 순서**(PRESET → 100M → 10M → 1M → 0.1M → 0.025M)
대로 채웁니다. 케이블 기준으로는 **C2 가 `4–9` 연속**, **C3 는 `0–3` + `10–11`** 로 나뉩니다.
엔코더 케이블에서 반대 엣지로 넘어가는 것은 **VOL(`23`) 한 선뿐**입니다.

**`C1` 만 두 엣지로 나뉩니다.** ENGINE 스위치 7개는 `26–32`, **MPO 만 `40`** 입니다.
`24/25` 가 I2C 라 `26–32` 7핀이 그 엣지 하단 블록의 전부여서 8번째 신호를 넣을 자리가
없기 때문입니다. 한 엣지로 몰고 싶으면 MPO 를 여유 핀 `12` 로 옮기면 됩니다
(엔코더 블록 옆이라 `26–32` 와는 떨어집니다).

**여유 핀** — 12, 39(A15) = 2개.

### 하단 SD 카드 인터페이스 — UHF 디스플레이 (C14)

UHF 7세그 디스플레이(MAX7219)는 **엣지 핀을 쓰지 않습니다.** Teensy 4.1 뒷면
SD 카드 소켓의 **SPI2** 를 **SD 확장 케이블**로 빼내 연결하므로 위 배치는 그대로입니다.

| Teensy | SPI2 | 디스플레이 J1 |
|---|---|---|
| 43 | MOSI2 | J1.3 DIN |
| 45 | SCK2 | J1.4 CLK |
| 44 | CS2 | J1.5 CS (소프트웨어 토글) |
| VIN | – | J1.1 +5V |
| GND | – | J1.2 GND |

MISO2(42)는 MAX7219 가 단방향이라 쓰지 않습니다. 8MHz 하드웨어 SPI 로 구동하며,
스케치에서 `HAS_UHF_DISPLAY` 로 켜고 끕니다.

> ⚠ **SD 카드와 공존 불가** — 같은 핀을 공유하므로 이 보드에서는 microSD 를 쓸 수 없습니다.
> ⚠ **밝기** — `DISP_DEFAULT_INTENSITY = 0x08`. MAX7219 는 VIN(5V)에서 급전되어
> 3.3V 레귤레이터와는 무관하지만, 0x0F 로 올리면 USB 예산에 최대 약 208mA 가 더해집니다.

---

## 공통 — MCP23017 모듈 물리 핀 배열

### MCP #0  `0x20` — UHF + AUDIO 1 COMM  (UHF 패널 실장)

```
   LONG EDGE HEADER : single row, 20 pins    CABLE
   -----------------------------------------------
    1  VCC  3.3V                 ---
    2  GND  GND                  C7 C8
    3  PB0  -- spare --           ---
    4  PB1  UHF MODE MNL         C7
    5  PB2  UHF MODE PRESET      C7
    6  PB3  UHF MODE GRD         C7
    7  PB4  UHF FUNCTION OFF     C7
    8  PB5  UHF FUNCTION MAIN    C7
    9  PB6  UHF FUNCTION BOTH    C7
   10  PB7  UHF FUNCTION ADF     C7
   11  VCC  3.3V                 ---
   12  GND  GND                  C7 C8
   13  PA0  AUDIO2 HOT MIC       C8
   14  PA1  AUDIO2 CIPHER        C8
   15  PA2  AUDIO1 COMM1 GD XMT  C8
   16  PA3  AUDIO1 COMM1 SQL     C8
   17  PA4  AUDIO1 COMM1 OFF     C8
   18  PA5  AUDIO1 COMM2 GD XMT  C8
   19  PA6  AUDIO1 COMM2 SQL     C8
   20  PA7  AUDIO1 COMM2 OFF     C8

   ADDRESS JUMPER (3 rows x 2 cols)      [ VCC | GND ]
        A0  ------------------------> GND
        A1  ------------------------> GND
        A2  ------------------------> GND
```

> **주소 점퍼 = 공장 출하 그대로** (A0/A1/A2 전부 GND) → `0x20`.
> **19/20 사용 — PB0 여유 1핀.** STATUS 가 Teensy pin 41 직결(`C13`)로 이설되어 PB0 이 빈 상태입니다.
> `PA0`~`PA7` 은 **AUDIO 패널** 신호입니다 — `PA0/PA1` 은 AUDIO 2 의 HOT MIC·CIPHER,
> `PA2`~`PA7` 은 AUDIO 1 의 COMM 1/2 모드 로터리. 모두 **케이블 C8**(패널 간 점퍼)로 들어옵니다.
> UHF(C7)가 헤더 앞쪽 `PB` 블록에 모여 있어, 모듈이 실장된 UHF 패널 쪽 배선이 짧습니다.
> **T-TONE·SQUELCH·STATUS 는 Teensy 직결**(`C13`)이라 이 모듈을 거치지 않습니다.
> GND 는 두 핀 다 같은 네트이므로, **C7 은 PB 블록 위쪽의 2번**, **C8 은 12번**에
> 물리면 배선이 가장 짧습니다.
> ⚠ **로터리 배선 순서 절대 준수** — FUNCTION `PB4→5→6→7`(OFF→MAIN→BOTH→ADF),
> MODE `PB1→2→3`(MNL→PRESET→GRD).
> COMM1 `PA4→3→2`(OFF→SQL→GD), COMM2 `PA7→6→5`(OFF→SQL→GD) — 개별 `SW_ON_OFF` 로 DX 역순 처리.

### MCP #1  `0x21` — ELEC + EPU  (ELEC 패널 실장)

```
   LONG EDGE HEADER : single row, 20 pins    CABLE
   -----------------------------------------------
    1  VCC  3.3V                 ---
    2  GND  GND                  C9 C10
    3  PB0  ELEC MAIN            C9
    4  PB1  ELEC BATT            C9
    5  PB2  ELEC CAUTION RST     C9
    6  PB3  LED EPU HYDRAZN      C10
    7  PB4  LED EPU AIR          C10
    8  PB5  LED EPU RUN          C10
    9  PB6  EPU OFF              C10
   10  PB7  EPU ON               C10
   11  VCC  3.3V                 ---
   12  GND  GND                  C9 C10
   13  PA0  LED FLCS PMG         C9
   14  PA1  LED MAIN GEN         C9
   15  PA2  LED STBY GEN         C9
   16  PA3  LED EPU GEN          C9
   17  PA4  LED EPU PMG          C9
   18  PA5  LED BATT TO FLCS     C9
   19  PA6  LED FLCS RLY         C9
   20  PA7  LED BATT FAIL        C9

   ADDRESS JUMPER (3 rows x 2 cols)      [ VCC | GND ]
        A0  ------------------------> VCC  <<< MOVE HERE
        A1  ------------------------> GND
        A2  ------------------------> GND
```

> **주소 점퍼: A0 만 VCC 쪽으로 옮기십시오** (A1/A2 는 GND 유지) → `0x21`.
> **20/20 전부 사용 — 여유 없음.** LED 11개가 붙는 칩이라 전류가 가장 큽니다.
> PA0~PA7 ELEC LED 8개가 한 포트에 모여 있어 `OLATA` **1회 쓰기로 8개 동시 갱신**됩니다
> (PB3~PB5 EPU LED 3개 때문에 `OLATB` 가 한 번 더 — 칩당 최대 2회).
> ⚠ **LED 개당 10mA 이하로 잡으십시오.** LED 캐소드 공통을 GND 로 두는 **소싱** 구성이라
> 한계는 `VSS` 150mA 가 아니라 **`VDD` 유입 125mA**(절대최대)입니다. 11 × 12mA = 132mA 는
> 이미 초과이고, 11 × 10 = 110mA 라야 여유가 생깁니다. 더 밝게 쓰려면 애노드를 3.3V 로
> 올려 **싱킹**(`VSS` 150mA 기준)으로 바꾸고 `writeElecLed()` 극성을 반전해야 합니다.
> LED 캐소드 공통은 **19번 핀 GND**(PB7 바로 옆)를 쓰면 배선이 짧습니다.

### MCP #2  `0x22` — ECM + AVTR  (ECM 패널 실장)

```
   LONG EDGE HEADER : single row, 20 pins    CABLE
   -----------------------------------------------
    1  PA7  AVTR ON              C12
    2  PA6  AVTR AUTO            C12
    3  PA5  -- spare --          ---
    4  PA4  -- spare --          ---
    5  PA3  -- spare --          ---
    6  PA2  -- spare --          ---
    7  PA1  -- spare --          ---
    8  PA0  -- spare --          ---
    9  GND  GND                  C12
   10  VCC  3.3V                 ---
   11  PB0  -- spare --          ---
   12  PB1  -- spare --          ---
   13  PB2  ECM OFF              C11
   14  PB3  ECM OPR              C11
   15  PB4  ECM XMIT 3           C11
   16  PB5  ECM XMIT 1           C11
   17  PB6  ECM BIT              C11
   18  PB7  ECM RESET            C11
   19  GND  GND                  C11
   20  VCC  3.3V                 ---

   ADDRESS JUMPER (3 rows x 2 cols)      [ VCC | GND ]
        A0  ------------------------> GND
        A1  ------------------------> VCC  <<< MOVE HERE
        A2  ------------------------> GND
```

> **주소 점퍼: A1 만 VCC 쪽으로 옮기십시오** (A0/A2 는 GND 유지) → `0x22`.
> **PA0~PA5 6핀 + PB0~PB1 2핀 여유** — 프로젝트 전체에서 남은 MCP 확장 여지입니다.
> ECM 스위치는 **PB2~PB7**(19번 핀 GND 바로 옆), AVTR 는 **PA6~PA7**(9번 핀 GND 바로 옆)에
> 배치되어 각각 가까운 GND 핀을 공통 연결하면 됩니다.

### 주소 점퍼 설정

3행 × 2열 솔더 점퍼입니다. 각 행(`A0` `A1` `A2`)을 `VCC` 열 또는 `GND` 열에 연결합니다.
**공장 출하 상태는 3행 모두 `GND` = `0x20`** 입니다.

| 칩 | 주소 | A2 | A1 | A0 | 출하 상태에서 할 일 |
|---|---|---|---|---|---|
| #0 | `0x20` | GND | GND | GND | **그대로 사용** |
| #1 | `0x21` | GND | GND | **VCC** | `A0` 만 VCC 쪽으로 이설 |
| #2 | `0x22` | GND | **VCC** | GND | `A1` 만 VCC 쪽으로 이설 |

> 0Ω 저항을 떼서 옮기거나, 떼어낸 뒤 **납으로 브리지**해도 됩니다.
> **양쪽 동시 연결은 절대 금지** — VCC와 GND가 단락됩니다.
> 이설 후 `i2cdetect` 상당 스캔(스케치 시리얼 로그)으로 `0x20 0x21 0x22` 세 개가
> 모두 보이는지 확인하십시오.

---

## 12V 백라이트 하니스 (별도 어댑터)

신호 케이블과 **물리적으로 분리**해서 포설합니다.

```
  12V ADAPTER (1A)
      │
      ├─ 12V+ ──┬─ ECM ─ ELEC ─ EPU ─ AVTR ─ UHF ─ AUDIO ─ ENGINE ──┐
      │         │       (each strip: LED x3 series + 220Ω = 13.6mA)  │
      │         │                                                      │
      │         │   LED-RTN (cathode common) <─────────────────────────┘
      │         │       │
      │         │     Drain
      │         │       │
      │         │    MOSFET (IRLML6344, N-ch)
      │         │       │
      │         │    Source
      │         │       │
      │         │      GND ─── 12V adapter GND
      │         │
      │         │              Gate
      │         │               ├────┤1kΩ├──── Teensy pin 13
      │         │               │
      │         │              10kΩ
      │         │               │
      │         │              GND
      │
      └─ GND ═══ ! single-point (star) tie to Teensy GND — REQUIRED
```

**어댑터 GND와 Teensy GND를 연결하지 않으면 MOSFET 게이트 기준이 없어 백라이트 제어가
아예 동작하지 않습니다.** 그라운드 루프를 피하려면 한 지점에서만 접속합니다.

### 밝기 제어

| 상태 | 제어 방식 |
|---|---|
| **BMS online** | bridge가 `instrLight` → PWM 변환 (adaptive: BRT 미수신 시 DIM=255, 수신 후 DIM=50/BRT=255) |
| **DCS online** | Teensy가 `LIGHT_INST_PNL` (0~65535) → PWM 0~255 직접 변환 |
| **Offline 수동** | UHF STATUS 버튼을 누른 채 AUDIO1 TF pot → PWM 0~255 |
| **Idle 30분** | 자동 꺼짐. 입력 시 복귀 |

---

## 케이블 배선 상세

### 케이블 I1 · I2 · I3 — I2C 체인 (RJ45 T568B)

세 링크 모두 배선이 동일합니다.

| 핀 | 신호 | 페어 | 색상 |
|---|---|---|---|
| 1 | SDA | P2 | 흰/주황 |
| 2 | GND | P2 | 주황 |
| 3 | SCL | P3 | 흰/녹색 |
| 6 | GND | P3 | 녹색 |
| 4 | 3.3V | P1 | 파랑 |
| 5 | GND | P1 | 흰/파랑 |
| 7 | 3.3V (병렬) | P4 | 흰/갈색 |
| 8 | GND | P4 | 갈색 |

신호가 SDA·SCL 2개뿐이라 페어가 둘 남습니다. 남는 2페어를 **전원 병렬**에 써서
급전 임피던스를 낮췄습니다.

> ⚠ **체인이라 전원도 직렬로 흐릅니다.** MCP `0x21` 의 LED 11개(ELEC 8 + EPU 3)
> 전류가 `I1` → `I2` 를 통과합니다 (`I3` 는 `0x22` 의 수 mA 뿐). 개당 12mA 기준 약 132mA 이고,
> Cat5e 24AWG 2가닥 병렬(약 0.042Ω/m)로 4m 이면 강하가 **약 25mV** 라 문제없습니다.
> 다만 LED 전류를 올리거나 체인을 늘리면 이 값이 함께 커집니다.

### 케이블 C2 / C3 — UHF VOL + 엔코더 (RJ45 T568B)

**케이블 C2 — VOL + 엔코더 10M·1M·0.1M**

| 핀 | 신호 | Teensy 핀 | 페어 | 색상 |
|---|---|---|---|---|
| 1 | ENC 10MHz **A** | 4 | P2 | 흰/주황 |
| 2 | ENC 10MHz **B** | 5 | P2 | 주황 |
| 3 | ENC 1MHz **A** | 6 | P3 | 흰/녹색 |
| 6 | ENC 1MHz **B** | 7 | P3 | 녹색 |
| 4 | ENC 0.1MHz **A** | 8 | P1 | 파랑 |
| 5 | ENC 0.1MHz **B** | 9 | P1 | 흰/파랑 |
| 7 | **UHF VOL** | **23 (A9)** | P4 | 흰/갈색 |
| 8 | **GND** | — | P4 | 갈색 |

**케이블 C3 — 엔코더 PRESET·100M·0.025M**

| 핀 | 신호 | Teensy 핀 | 페어 | 색상 |
|---|---|---|---|---|
| 1 | ENC PRESET **A** | 0 | P2 | 흰/주황 |
| 2 | ENC PRESET **B** | 1 | P2 | 주황 |
| 3 | ENC 100MHz **A** | 2 | P3 | 흰/녹색 |
| 6 | ENC 100MHz **B** | 3 | P3 | 녹색 |
| 4 | ENC 0.025MHz **A** | 10 | P1 | 파랑 |
| 5 | ENC 0.025MHz **B** | 11 | P1 | 흰/파랑 |
| 7 | GND | — | P4 | 흰/갈색 |
| 8 | GND | — | P4 | 갈색 |

**UHF 로만 Teensy 케이블이 세 가닥(`I1` `C2` `C3`) 가는 이유** — 100kHz I2C 를 나머지와
격리하기 위해서입니다. 스위치 10개는 패널 옆 MCP `0x20` 가 받으므로 `I1` 은 SDA/SCL
2선으로 끝나고, 아날로그인 VOL 만 `C2` 로 빼냅니다.

**VOL 을 I2C 케이블에서 뺀 이유** — VOL 은 아날로그인데 `I1` 의 SDA/SCL 은 100kHz 로
스위칭합니다. 같은 케이블에 두면 인접 페어 크로스토크를 그대로 받습니다.
반면 엔코더는 **사람이 손으로 돌리는 기계식 접점**이라 빠른 엣지가 없어, VOL 과 한
케이블에 있어도 서로 간섭하지 않습니다. `C2` 의 P4 에서 **VOL/GND 트위스트 페어**를
이루므로 아날로그 리턴 경로도 전용으로 확보됩니다.

**엔코더는 A/B 를 같은 페어에 묶습니다.** 신호마다 전용 GND 리턴을 주려면 페어가 8개
필요해 LAN 3가닥이 되는데, 위와 같은 이유로 그럴 필요가 없습니다.
엔코더 공통 단자는 GND 로, **전원은 필요 없습니다** (내부 풀업 `INPUT_PULLUP` 사용).

---

### 케이블 C6 — ECM 직결 (RJ45 T568B)

| 핀 | 신호 | 페어 | 색상 |
|---|---|---|---|
| 1 | DS | P2 | 흰/주황 |
| 2 | GND | P2 | 주황 |
| 3 | **ECM 래더** | P3 | 흰/녹색 |
| 6 | GND | P3 | 녹색 |
| 4 | **SH_CP** | P1 | 파랑 |
| 5 | GND | P1 | 흰/파랑 |
| 7 | ST_CP | P4 | 흰/갈색 |
| 8 | **3.3V** | P4 | 갈색 |

**래더(P3)와 SH_CP(P1)를 서로 다른 페어에 배치**하는 것이 핵심입니다. 각자 전용 GND
리턴을 가지므로 고주파 리턴 전류가 상대 페어의 접지 기준을 통과하지 않습니다.

> RJ45 핀 3과 6은 같은 페어(녹색)입니다. 번호 순서대로 묶으면 트위스트 페어가 깨집니다.

---

## 리소스 사용

| 항목 | 값 |
|---|---|
| **Teensy 헤더 핀** | **40 / 42** (여유 2) |
| ├ 아날로그 입력 | 11 / 18 (여유 ADC: A15 = 1개) |
| └ 여유 핀 | 12, 39 |
| **MCP23017 GPIO** | 39 / 48 |
| 74HC595 출력 | 32 / 32 ⚠ |
| **DX 버튼** | **58 / 128** |
| 조이스틱 축 | 10 / 23 |
| I2C 주소 | `0x20` `0x21` `0x22` |

---

## 시공 체크리스트

| # | 항목 |
|---|---|
| 1 | **UHF 로터리 연속 배선** — MCP#0 에서 FUNCTION = PB4→5→6→7 (OFF→ADF), MODE = PB1→2→3 (MNL→GRD). STATUS 는 Teensy pin 41 직결 |
| 2 | **AUDIO COMM 로터리 배선** — MCP#0 에서 COMM1 = PA4→3→2 (OFF→SQL→GD), COMM2 = PA7→6→5 (OFF→SQL→GD) (케이블 C8) |
| 3 | **C6 페어 배치** — LAN 에서 **래더/GND 와 SH_CP/GND 를 서로 다른 페어**에 (→ 「케이블 C6」 절) |
| 4 | **래더 필터 캡** — 1~10nF 세라믹을 Teensy A14(핀 38) 바로 옆에 |
| 5 | **아날로그선 트위스트** — ECM 래더, UHF VOL, AUDIO 와이퍼 6개를 각각 GND와 페어링 |
| 6 | **12V 어댑터 공통 GND** — Teensy GND와 단일점 연결 (누락 시 백라이트 제어 불가) |
| 7 | **I2C 풀업 추가 금지** — 모듈 온보드 **4.7kΩ ×3 병렬 ≈ 1.57kΩ**. 체인 전체가 한 버스라 풀업은 한 번만 셉니다. 전원 off 상태에서 `SDA↔VCC` 저항을 재서 확인 |
| 8 | **MCP `RST` 핀** — 이 모듈은 온보드 풀업이 있어 **미결선 가능**. 실측(`RST↔VCC` ≈ 4.7kΩ)으로 확인하고, 없으면 VCC 직결 |
| 9 | **MCP 모듈 위치** — `0x20` UHF 패널 옆 · `0x21` ELEC 패널 옆 · `0x22` ECM 패널 옆 |
| 10 | **MCP 주소 점퍼** — 출하 상태(전부 GND) = `0x20`. `0x21` 은 **A0만**, `0x22` 는 **A1만** VCC 쪽으로 이설. 양쪽 동시 연결 금지 |
| 11 | **I2C 핫플러그 보호** — SDA/SCL 직렬 100Ω, 각 보드 3.3V에 10µF + 100nF. 체인 **총 길이 5m 이내**(`I1`+`I2`+`I3` 합산이 라이즈타임을 결정) |
| 12 | **MCP#1 LED 전류** — LED **11개**(PA0~7 8개 + PB3~5 3개). 소싱 구성이라 `VDD` 유입 **125mA** 가 한계 → **개당 10mA 이하** (11 × 10 = 110mA) |
| 13 | **핀 13** — 백라이트 **출력**. 온보드 LED 공유는 출력이라 무해하고 LED가 상태 표시등이 됨. **입력으로는 쓰지 말 것** (LED 경로 때문에 상시 눌림 위험) |
| 14 | **엔코더 방향** — CW/CCW가 반대면 `encoders[]` 의 `pinA`/`pinB` 교체 |
| 15 | **⚠ Teensy 3.3V 레일** — ECM 32 LED(74HC595)와 MCP LED 11개가 **전부 Teensy 3.3V 레귤레이터**에서 나옵니다. 전점등 시 약 430mA 로 PJRC 권장 **250mA** 를 넘습니다. 세리머니 순차 점등은 필수이고, 상시 여유가 필요하면 **74HCT595 를 5V(Vin) 급전**으로 바꾸십시오 (HCT 는 VIH 2.0V 라 3.3V 로직으로 구동 가능, 직렬저항 재계산 필요) |
| 16 | **74HC595 패키지 전류** — VCC/GND 절대최대 약 **70mA/칩**. 정상 운용은 칩당 2점등(약 20mA)이라 무관하지만 **세리머니·`ALL_LIT` 상태에서 8점등**이면 초과합니다 |
| 17 | **USB 포트** — `welcomeCeremony()` 피크가 약 548mA. USB 2.0(500mA)에서는 순차 점등으로 변경 |

---

## MCP 를 거칠 수 없는 신호

| 신호 | 이유 |
|---|---|
| 74HC595 제어 3선 | 32비트 시프트 = MCP 경유 시 약 38ms (루프 예산 초과) |
| ECM 저항 래더 | MCP23017에 ADC 없음 |
| 로터리 엔코더 12선 | 인터럽트 필요 — I2C 폴링으로 펄스 유실 |
| POT 10개 | MCP23017에 ADC 없음 |

이 신호들만 Teensy 직결입니다. 나머지 **스위치 28 GPIO 와 LED 11개는 전부 I2C 2선**에
실립니다 (`0x20` 15 + `0x21` 16 + `0x22` 8 = 39 GPIO).

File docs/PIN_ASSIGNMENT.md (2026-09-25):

# REDKITE F16 LEFT CONSOLE — Teensy 4.1 Pin Assignment

패널: ECM / ELEC / EPU / AVTR / UHF / ENGINE START / MPO / AUDIO 1-2

- **Board**: Teensy 4.1 (헤더 핀 0–41, 아날로그 A0–A17)
- **USB**: PID `0x048E`, `JOYSTICK_SIZE 64` (128버튼)
- **I2C**: `Wire2` — SCL2 = pin 24, SDA2 = pin 25 @ 100kHz
- **사용 34 / 42핀, 여유 8핀** (12, 31–37)

> **이 문서는 STAGE_T41(Teensy 4.1 전체 구성) 기준입니다.**
> Teensy 4.0 임시 구성(엔코더를 제외한 전 패널, 22핀, DX 44, 축 7)은
> [LEFT_CONSOLE_PIN_TREE2.md](LEFT_CONSOLE_PIN_TREE2.md#stage_t40--teensy-40) 참조.
> 두 단계에서 **버튼 번호와 축 7개가 완전히 동일**합니다 — T40 도 엔코더 자리(42~53)를
> 비워 두고 예약하므로 확장 시 엔코더 외에는 재바인딩이 필요 없습니다.

> UHF 스위치 10개와 AUDIO 1 COMM 1/2 모드 로터리 2개는 패널 위 **MCP23017 `0x20`** 가 받습니다.
> 덕분에 Teensy 직결 핀 16개가 절약되고, UHF 케이블도 17선으로 줄어듭니다.

> 배선 트리(케이블·패널 단위 연결도)는 [LEFT_CONSOLE_PIN_TREE.md](LEFT_CONSOLE_PIN_TREE.md) 참조.

> 이전 Teensy 4.0 배치는 `F16_LEFT_CONSOLE/backup/` 참조.

---

## Teensy 4.1 핀 전체

| 핀 | ADC | 패널 | 신호 |
|-----|-----|---|---|
| 0 / 1 | | UHF | 엔코더 10MHz (A / B) |
| 2 / 3 | | UHF | 엔코더 1MHz (A / B) |
| 4 / 5 | | UHF | 엔코더 0.1MHz (A / B) |
| 6 / 7 | | UHF | 엔코더 PRESET (A / B) |
| 8 / 9 | | UHF | 엔코더 100MHz (A / B) |
| 10 / 11 | | UHF | 엔코더 0.025MHz (A / B) |
| 12 | | – | **여유** |
| 13 | | – | 백라이트 MOSFET 게이트 (ON/OFF, 디밍 없음) — 온보드 LED 공유, 출력이라 무해 |
| 14 | A0 | ECM | 74HC595 ST_CP (LATCH) |
| 15 | A1 | ECM | 74HC595 SH_CP (CLOCK) |
| 16 | A2 | ECM | 74HC595 DS (DATA) |
| 17 | A3 | ECM | 8버튼 저항 래더 |
| 18 | A4 | ENGINE | ENG CONT (PRI / SEC) |
| 19 | A5 | ENGINE | **JFS RUN LED** (출력) |
| 20 | A6 | ENGINE | JFS pin2 (START 2) |
| 21 | A7 | ENGINE | JFS pin1 (START 1) |
| 22 | A8 | MPO | MANUAL PITCH OVERRIDE |
| 23 | A9 | UHF | VOL 포트 |
| 24 | A10 | – | I2C SCL2 |
| 25 | A11 | – | I2C SDA2 |
| 26 | A12 | AUDIO 2 | ILS VOL |
| 27 | A13 | AUDIO 2 | INTERCOM |
| 28 | | ENGINE | MAX POWER |
| 29 | | ENGINE | AB RESET |
| 30 | | ENGINE | ENG DATA |
| **31–37** | | – | **여유 7** (비ADC) |
| 38 | A14 | AUDIO 1 | THREAT VOL |
| 39 | A15 | AUDIO 1 | MSL VOL |
| 40 | A16 | AUDIO 1 | COMM CH2 |
| 41 | A17 | AUDIO 1 | COMM CH1 |

### 확장기를 통과할 수 없는 신호

| 신호 | 이유 |
|---|---|
| 74HC595 3선 (14, 15, 16) | 32비트 시프트 = MCP 경유 시 약 38ms 소요 (루프 예산 초과) |
| ECM 저항 래더 (17) | MCP23017에 ADC 없음 |
| 엔코더 12선 | 인터럽트 필요 — I2C 폴링으로 펄스 유실 |
| 포트 7개 | MCP23017에 ADC 없음 |

---

## MCP23017 — 3칩, 40 / 48 GPIO

MCP 핀 번호: **GPA0–7 = 0–7, GPB0–7 = 8–15**

### `0x20` — UHF + AUDIO 1 COMM (UHF 패널 실장)

| GPIO | 신호 | 타입 |
|---|---|---|
| GPA0–GPA3 | UHF FUNCTION (OFF / MAIN / BOTH / ADF) | 4단 로터리 |
| GPA4–GPA6 | UHF MODE (MNL / PRESET / GRD) | 3단 로터리 |
| GPA7 | UHF SQUELCH | ON/OFF |
| GPB0 | UHF T-TONE | 모멘터리 |
| GPB1 | UHF STATUS | 모멘터리 |
| GPB2–GPB4 | AUDIO1 COMM 1 MODE (OFF / SQL / GD XMT) | 3단 로터리 |
| GPB5–GPB7 | AUDIO1 COMM 2 MODE (OFF / SQL / GD XMT) | 3단 로터리 |

> `SW_ROTARY` 는 `pin1` 부터 연속 GPIO 를 읽습니다 — 패널 배선 순서 필수.

### `0x21` — ELEC + EPU (ELEC 패널 실장)

| GPIO | 신호 | 타입 |
|---|---|---|
| GPA0 / GPA1 | ELEC MAIN PWR (BATT / OFF / MAIN) | ON/OFF/ON |
| GPA2 | ELEC CAUTION RST | 모멘터리 |
| GPA3 / GPA4 | EPU (OFF / NORM / ON) | ON/OFF/ON |
| GPA5 | **EPU HYDRAZN LED** | 출력 |
| GPA6 | **EPU AIR LED** | 출력 |
| GPA7 | **EPU RUN LED** | 출력 |
| GPB0 | LED FLCS PMG | 출력 |
| GPB1 | LED MAIN GEN | 출력 |
| GPB2 | LED STBY GEN | 출력 |
| GPB3 | LED EPU GEN | 출력 |
| GPB4 | LED EPU PMG | 출력 |
| GPB5 | LED FLCS RLY | 출력 |
| GPB6 | LED BATT FAIL | 출력 |
| GPB7 | LED BATT TO FLCS | 출력 |

> LED 8개를 GPB 포트에 몰아둔 덕에 `OLATB` **1회 쓰기로 8개 동시 갱신**됩니다.
> **개당 10mA 이하**로 유지하세요 — 이 칩에 LED 가 11개(GPB 8 + GPA5~7 3) 붙고,
> 캐소드 공통 GND = 소싱 구성이라 한계가 `VDD` 유입 **125mA** 입니다 (11 × 10 = 110mA).

### `0x22` — ECM + AVTR (ECM 패널 실장)

| GPIO | 신호 | 타입 |
|---|---|---|
| GPA0 / GPA1 | ECM OPR/STBY (OPR / OFF / STBY) | ON/OFF/ON |
| GPA2 / GPA3 | ECM XMIT (1 / 2 / 3) | ON/OFF/ON |
| GPA4 | ECM BIT | 모멘터리 |
| GPA5 | ECM RESET | 모멘터리 |
| GPA6 / GPA7 | AVTR (OFF / AUTO / ON) | ON/OFF/ON |
| GPB0–GPB7 | 여유 8 | |

---

## 조이스틱 축 (10 / 23)

Extreme 조이스틱(`JOYSTICK_SIZE 64`)은 명명 축 6개 + `slider(1..17)` = **23채널**입니다.
단, DirectInput은 최대 8축(6 named + `rglSlider[2]`)만 인식합니다.

| # | 축 | 신호 | 핀 | DirectInput | BMS 바인딩 |
|---|-----|---|-----|---|---|
| 1 | X | AUDIO COMM CH1 | 22 (A8) | lX | ✓ |
| 2 | Y | AUDIO COMM CH2 | 21 (A7) | lY | ✓ |
| 3 | Z | AUDIO MSL VOL | 19 (A5) | lZ | ✓ |
| 4 | Xrotate | AUDIO THREAT VOL | 17 (A3) | lRx | ✓ |
| 5 | Yrotate | AUDIO INTERCOM | 16 (A2) | lRy | ✓ |
| 6 | Zrotate | UHF VOL | 23 (A9) | lRz | ✓ |
| 7 | `slider(1)` | AUDIO ILS VOL | 14 (A0) | rglSlider[0] | ✓ |
| 8 | `slider(2)` | AUDIO SECURE VOL | 20 (A6) | rglSlider[1] | ✓ |
| 9 | `slider(3)` | AUDIO TF VOL | 18 (A4) | (미인식) | ✗ |
| 10 | `slider(4)` | AUDIO TACAN VOL | 15 (A1) | (미인식) | ✗ |

### usb_desc.c 수정 사항 (시스템 파일, git 미추적)

파일 위치: `%LOCALAPPDATA%/Arduino15/packages/teensy/hardware/avr/<version>/cores/teensy4/usb_desc.c`

Teensyduino 원본은 `JOYSTICK_SIZE 64` 에서 17개 슬라이더를 전부 동일한 Usage ID
`0x36`(Slider)으로 선언합니다. 이 중복으로 인해 **Windows DirectInput이 슬라이더를
전혀 인식하지 못합니다** (`rglSlider[0]`, `[1]` 모두 미동작).

**수정**: Report Count 를 23 → 8 로 줄이고, 나머지 15개는 constant padding 처리.

```c
// 변경 전 (Teensyduino 원본)
0x95, 23,          // Report Count (23)
0x09, 0x30~0x36,   // X,Y,Z,Rx,Ry,Rz + Slider ×17
0x81, 0x02,        // Input (variable, absolute)

// 변경 후
0x95, 8,           // Report Count (8)
0x09, 0x30~0x36,   // X,Y,Z,Rx,Ry,Rz + Slider ×2
0x81, 0x02,        // Input (variable, absolute)
0x95, 15,          // Report Count (15)
0x81, 0x01,        // Input (constant) — padding
```

USB report 크기(64바이트)는 변하지 않으며, `Joystick.slider(1..17)` API도 그대로
동작합니다. DirectInput이 읽는 8개 축만 정상 매핑되고, 나머지는 무시됩니다.

> ⚠ Arduino IDE / Teensyduino **업데이트 시 이 파일이 덮어씌워집니다**.
> 업데이트 전에 백업하거나, 업데이트 후 다시 수정해야 합니다.

---

## DX 버튼 맵 (56 / 128)

| 버튼 | 패널 | 신호 |
|---|---|---|
| 1–2 | ECM | OPR / STBY |
| 3–4 | ECM | XMIT 1 / XMIT 3 |
| 5 | ECM | BIT |
| 6 | ECM | RESET |
| 7–8 | ELEC | BATT / MAIN |
| 9 | ELEC | CAUTION RST |
| 10–11 | AVTR | AUTO / ON |
| 12–13 | ENGINE | JFS START 1 / START 2 |
| 14 | ENGINE | ENG CONT |
| 15 | MPO | MANUAL PITCH OVERRIDE |
| 16–17 | EPU | NORM / ON |
| 18–21 | UHF | FUNCTION OFF / MAIN / BOTH / ADF |
| 22–24 | UHF | MODE MNL / PRESET / GRD |
| 25 | UHF | SQUELCH |
| 26 | UHF | T-TONE |
| 27 | UHF | STATUS |
| 28–30 | AUDIO 1 | COMM 1 MODE — OFF / SQL / GD XMT |
| 31–33 | AUDIO 1 | COMM 2 MODE — OFF / SQL / GD XMT |
| 34–41 | ECM | 저항 래더 — ECM 1~6, FRM, SPL |
| 42–53 | UHF | 엔코더 6개 × (CW / CCW) — **T40 에서는 미사용(예약)** |
| 54–55 | ENGINE | MAX POWER / AB RESET |
| 56 | ENGINE | ENG DATA |

> 54번부터는 `switches[]` 배열 맨 뒤(`SWITCH_LATE_START` 이후)에 있는 항목입니다.
> 래더·엔코더 **뒤에** 배정해서, 스위치를 새로 추가해도 기존 버튼 1~53 의
> 바인딩이 그대로 유지되도록 한 구조입니다.

---

## ECM 저항 래더 (PCB 고정)

10kΩ 직렬 체인 + 20kΩ 풀다운. `ADC_k = 1023 × 20000 / (k × 10000 + 20000)`

| 버튼 | 기대값 | 인접 경계 | 노이즈 여유 |
|---|---|---|---|
| ECM 1 | 1024 | 852 | ±172 |
| ECM 2 | 680 | 594 | ±86 |
| ECM 3 | 509 | 457 | ±52 |
| ECM 4 | 406 | 372 | ±34 |
| ECM 5 | 338 | 314 | ±24 |
| ECM 6 | 290 | 271 | ±18 |
| ECM FRM | 253 | 239 | **±14** |
| ECM SPL | 225 | 239 | **±14** |

**판별은 최근접값(nearest-value) 방식**입니다. 창 겹침으로 인한 동시 매칭·오인식이 구조적으로 발생하지 않습니다. 8회 오버샘플링으로 ADC 노이즈가 약 ±2카운트라 최악 조합(FRM/SPL)에서도 7배 마진을 확보합니다.

`maxDist = 60` 을 넘으면 무입력으로 처리합니다 (대기 시 ADC ≈ 0).

> 12비트(`analogReadResolution(12)`)로 올리려면 `ecmBtnValues[]`와 `maxDist`를 모두 **×4** 해야 합니다. 현재는 기존 캘리브레이션을 보존하기 위해 10비트를 유지합니다.

---

## 74HC595 — ECM LED 32개 (변경 없음)

ECM 1~6 / FRM / SPL × (S, A, F, T). `srMap[]`이 논리 인덱스를 물리 출력으로 리맵합니다.

**32 / 32 전부 사용 중.** 칩을 추가하면 BMS-BIOS 프레임의 `srData` 32비트를 초과하므로 `BB_FRAME_PAYLOAD`, 양쪽 `BmsBiosParser.h`, `bmsbios_bridge.py`를 모두 수정해야 합니다.

---

## 배선 — 패널별

### 간선 (Teensy에서 나가는 케이블 8가닥)

| 케이블 | 대상 | 신호 | 내역 | 합계 |
|---|---|---|---|---|
| **C1** | ENGINE + MPO | 8 | JFS ×2, ENG CONT, MPO, MAX PWR, AB RESET, ENG DATA, **RUN LED** | **9선** (+GND) |
| **I1** | UHF 패널 · I2C | 2 | SDA, SCL | **8선** (LAN, +3.3V ×2, GND ×4) |
| **C2** | UHF 패널 · VOL + 엔코더 | 7 | **POT 1개**(VOL) + 10MHz, 1MHz, 0.1MHz × A/B | **8선** (LAN, +GND) |
| **C3** | UHF 패널 · 엔코더 | 6 | PRESET, 100MHz, 0.025MHz × A/B | **8선** (LAN, +GND ×2) |
| **C4** | AUDIO 1 | 4 | **POT 4개** — COMM CH1, COMM CH2, MSL VOL, THREAT VOL (38–41, 오른쪽 연속) | **6선** (+3.3V, GND) |
| **C5** | AUDIO 2 | 2 | **POT 2개** — INTERCOM, ILS VOL (26–27, 왼쪽 연속) | **4선** (+3.3V, GND) |
| **C6** | ECM 패널 | 4 | DS, SH_CP, ST_CP, ECM래더 | **8선** (LAN, +3.3V, GND ×3) |

> `C3` 는 **STAGE_T41 전용**입니다. `C2` 는 T40 에서도 VOL 때문에 필요하지만
> 엔코더 6선은 미결선으로 둡니다.

### 패널 간 점퍼 (Teensy 미경유)

| 구간 | 신호 | 내역 | 합계 |
|---|---|---|---|
| AUDIO 1 → UHF 패널 (케이블 C8) | 6 | COMM 1 MODE ×3, COMM 2 MODE ×3 → MCP `0x20` GPB2~7 | **7선** (+GND) |

> AUDIO 1 의 COMM 모드 로터리는 Teensy 로 가지 않고 **옆 UHF 패널의 MCP** 로 직접 들어갑니다.
> 두 패널이 좌측 콘솔에서 인접하고, STAGE_T40 의 Teensy 여유 핀이 5개뿐이라 직결이 불가능하기 때문입니다.

### MCP 모듈 → 담당 패널 하니스 (`C7`~`C12`)

모듈을 담당 패널 옆에 각각 실장하는 **배치 근거와 케이블별 선수**는
[LEFT_CONSOLE_PIN_TREE.md](LEFT_CONSOLE_PIN_TREE.md) 의 「케이블 구성」·「토폴로지」 절이 정본입니다.

`C6`(ECM 래더 1선 + SR 3선)만은 MCP 를 거치지 않는 **Teensy 직결**이며, LAN 페어 배치에서
**래더/GND 와 SH_CP/GND 를 서로 다른 페어**에 두어 리턴 경로를 분리해야 합니다
(판별 여유 ±14카운트). 상세는 같은 문서의 「케이블 C6」 절.

### 케이블 권장

| 구간 | 구성 |
|---|---|
| → ECM 패널 | LAN ×2 — **I3**(체인): SDA/GND, SCL/GND, 3.3V/GND ×2 · **C6**: DS/GND, **래더/GND**, SH_CP/GND, ST_CP/3.3V |
| → ELEC 패널 | LAN ×1 — **I2**(체인): SDA/GND, SCL/GND, 3.3V/GND ×2 |
| → UHF | LAN ×3 — **I1**: SDA/GND, SCL/GND, 3.3V/GND ×2 · **C2**: 엔코더 A/B 3쌍 + **VOL/GND** · **C3**: 엔코더 A/B 3쌍 + GND 페어 |
| → ENGINE+MPO | **C1** — 9선 일반 (RUN LED 포함) |
| → AUDIO | **C4** 6선 / **C5** 4선. 와이퍼는 각각 GND와 트위스트 페어 |

아날로그선(ECM 래더, UHF VOL, AUDIO 와이퍼 6)은 **전부 GND와 트위스트 페어**로 처리합니다.

I2C 핫플러그 보호: SDA/SCL 직렬 100Ω, 각 보드 3.3V에 10µF + 100nF (`hotplug_spec.md` 준용).

---

## 전원

```
USB 5V (900mA)
    └─ Teensy 4.1 ─┬─ 3.3V ─┬─ MCP23017 x3 (0x20 / 0x21 / 0x22)
                   │        ├─ 74HC595 x4
                   │        └─ indicator LEDs x43 (ECM 32 + ELEC/EPU 11)
                   GND ─────────────┐
                                    │  ! common ground required (single point)
12V adapter ─┬─ 12V+ ─> backlight strips (all panels, daisy-chain)
            └─ GND ──┴─ LED-RTN ─> MOSFET(IRLML6344) ─> GND
                                      Gate <- 1kΩ <- pin 13
                                             10kΩ pull-down -> GND
```

| 항목 | 값 |
|---|-----|
| 백라이트 전원 | **별도 12V 어댑터 (1A 권장)** — MT3608 스텝업 불필요 |
| USB 예산 | 900mA − Teensy 100 − 로직 10 − LED 최대 440 ≈ **여유 350mA** |
| 12V 하니스 | `12V+` / `LED-RTN` 2선, 신호 케이블과 물리적 분리 |

**⚠️ 어댑터 GND와 Teensy GND를 반드시 연결하세요.** MOSFET 게이트가 Teensy GND 기준으로 동작하므로, 접지가 분리되면 백라이트 제어가 성립하지 않습니다. 그라운드 루프를 피하려면 **단일점(star) 접지**로 한 곳에서만 연결합니다.

**⚠️ USB 2.0 포트(500mA)에서는 `welcomeCeremony()` 피크(약 548mA)가 초과할 수 있습니다.** USB 3.0 포트를 쓰거나 세리머니의 전체 동시 점등을 순차 점등으로 바꾸세요.

**⚠️ USB 예산보다 Teensy 3.3V 레귤레이터가 먼저 걸립니다.** 위 계통도대로 74HC595 4장과 MCP23017 3장, 그리고 표시등 43개가 **전부 3.3V 레일 하나**에서 나옵니다. 전점등 시 약 430mA 로 PJRC 권장 **250mA** 를 넘으므로, USB 3.0 을 써도 해결되지 않습니다. 세리머니 순차 점등이 필수이고, 상시 여유가 필요하면 **74HCT595 를 5V(Vin) 급전**으로 바꾸십시오 (HCT 는 VIH 2.0V 라 3.3V 로직으로 구동 가능, LED 직렬저항 재계산 필요).

MCP23017 의 LED 는 캐소드 공통 GND = **소싱** 구성이라 한계가 `VDD` 유입 **125mA** 입니다. `0x21` 한 장에 11개가 붙으므로 **개당 10mA 이하**로 잡으십시오 (11 × 10 = 110mA).

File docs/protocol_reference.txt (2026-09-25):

Protocol Reference — DCS-BIOS & BMS-BIOS LED Mapping
=====================================================

1. DCS-BIOS (DCS World F-16C_50)
=================================

Source: DCS-BIOS F-16C_50.json
  Path: %USERPROFILE%\Saved Games\DCS\Scripts\DCS-BIOS\doc\json\F-16C_50.json
  Web:  http://localhost:5010/reference/  (DCS 실행 중)

Protocol:
  - Binary, sync 0x55 x4
  - Repeating chunks: ADDR_LO ADDR_HI COUNT_LO COUNT_HI DATA[count]
  - Frame end: addr=0x5555, count=0x5555
  - Baud: 1,000,000

LED Address Map (used in DcsBiosParser.h):

  Identifier           Address(dec)  Address(hex)  Mask(hex)  Bit  Description
  -------------------  -----------   -----------   ---------  ---  -----------
  LIGHT_GEAR_N         17530         0x447A        0x4000     14   Nose Gear (green)
  LIGHT_GEAR_L         17530         0x447A        0x8000     15   Left Gear (green)
  LIGHT_GEAR_R         17532         0x447C        0x0001      0   Right Gear (green)
  LIGHT_GEAR_WARN      17532         0x447C        0x0002      1   Gear Warning (red)
  LIGHT_RWR_SEARCH     17534         0x447E        0x0400     10   TWA Search
  LIGHT_RWR_ACTIVITY   17534         0x447E        0x0800     11   TWA Activity
  LIGHT_RWR_ACT_POWER  17534         0x447E        0x1000     12   TWA Act/Power
  LIGHT_RWR_ALT_LOW    17534         0x447E        0x2000     13   TWA Alt Low
  LIGHT_ECM            17732         0x4544        0x4000     14   ECM Indicator

Backlight Control:

  LIGHT_INST_PNL           17540         0x4484        0xFFFF     -    Instrument Panel Lighting (0–65535)

Not currently used but available:

  LIGHT_RWR_POWER      17534         0x447E        0x8000     15   RWR Power
  LIGHT_RWR_ALT        17534         0x447E        0x4000     14   RWR Alt
  LIGHT_HOOK           17526         0x4476        0x8000     15   Hook (yellow)
  LIGHT_RWR_HANDOFF_UP 17536         0x4480        0x0001      0   RWR Handoff Up
  LIGHT_RWR_HANDOFF_H  17536         0x4480        0x0002      1   RWR Handoff H
  LIGHT_RWR_MSL_LAUNCH 17536         0x4480        0x0004      2   RWR Missile Launch
  LIGHT_RWR_MODE_PRI   17536         0x4480        0x0008      3   RWR Mode Pri
  LIGHT_RWR_MODE_OPEN  17536         0x4480        0x0010      4   RWR Mode Open
  LIGHT_RWR_SHIP_UNK   17536         0x4480        0x0020      5   RWR Ship Unknown
  LIGHT_RWR_SYSTEST    17536         0x4480        0x0040      6   RWR Sys Test
  LIGHT_RWR_TGTSEP_UP  17536         0x4480        0x0080      7   RWR TgtSep Up
  LIGHT_RWR_TGTSEP_DN  17536         0x4480        0x0100      8   RWR TgtSep Down
  LIGHT_ECM_1_A        17536         0x4480        0x4000     14   ECM 1 A

2. BMS-BIOS (Falcon BMS 4.38)
===============================

Source: Falcon BMS 4.38 FlightData.h
  Path: C:\Falcon BMS 4.38\Tools\SharedMem\FlightData.h

Protocol:
  - Binary, sync 0xAA 0xBB
  - Payload: ledBits (uint32 LE, 4 bytes)
    - Bits 0–10: LED states (see LED Index Mapping)
    - Bits 16~23: Backlight PWM brightness (from instrLight)
  - Checksum: XOR of 4 payload bytes (1 byte)
  - Total: 7 bytes per frame
  - Baud: 1,000,000

Shared Memory:
  - Name: "FalconSharedMemoryArea"
    FlightData struct offsets:
      lightBits  = 108  (unsigned int)
      lightBits2 = 124  (unsigned int)
      lightBits3 = 128  (unsigned int)
  - Name: "FalconSharedMemoryArea2"
    FlightData2 struct offsets:
      instrLight = 1104  (unsigned char, 0=OFF, 1=DIM, 2=BRT)

LightBits Mask Map (used in bmsbios_bridge.py):

  LightBits (offset 108):
    Name            Mask(hex)     Bit  Description
    -------------   ----------    ---  -----------
    AdvStandby      0x80000000     31  ADV Standby indicator

  LightBits2 (offset 124):
    Name            Mask(hex)     Bit  Description
    -------------   ----------    ---  -----------
    AuxSrch         0x00001000     12  TWA Search
    AuxAct          0x00002000     13  TWA Activity
    AuxLow          0x00004000     14  TWA Alt Low
    AuxPwr          0x00008000     15  TWA Power
    EcmPwr          0x00010000     16  ECM power indicator
    AdvActive       0x20000000     29  ADV Active indicator
    GEARHANDLE      0x40000000     30  Gear handle lamp (gear in motion)

  LightBits3 (offset 128):
    Name            Mask(hex)     Bit  Description
    -------------   ----------    ---  -----------
    NoseGearDown    0x00010000     16  Nose gear down and locked
    LeftGearDown    0x00020000     17  Left gear down and locked
    RightGearDown   0x00040000     18  Right gear down and locked

3. LED Index Mapping (LedIdx enum in .ino)
==========================================

  Index  Name          Pin   Location       DCS-BIOS              BMS LightBit
  -----  -----------   ---   ----------     -------------------   ----------------
  0      Nose Gear     30    direct         0x447A bit14          LB3 NoseGearDown
  1      Left Gear     31    direct         0x447A bit15          LB3 LeftGearDown
  2      Right Gear    32    direct         0x447C bit0           LB3 RightGearDown
  3      Gear Warn     27    direct         0x447C bit1           LB2 GEARHANDLE
  4      TWA Power     34    direct         0x447E bit12          LB2 AuxPwr
  5      TWA Low       35    direct         0x447E bit13          LB2 AuxLow
  6      TWA Search    36    direct         0x447E bit10          LB2 AuxSrch
  7      TWA Act       37    direct         0x447E bit11          LB2 AuxAct
  8      ECM           MCP0:7   MCP 0x20    0x4544 bit14          LB2 EcmPwr
  9      ADV Active    MCP0:8   MCP 0x20    0x447E bit2           LB2 AdvActive
  10     ADV Standby   MCP0:9   MCP 0x20    0x447E bit3           LB AdvStandby

3-2. LED Index Mapping — F16_LEFT_CONSOLE (0x048E)
==================================================

  Source: Falcon BMS 4.38  Tools/SharedMem/FlightData.h  (enum LightBits2 / LightBits3)

  ledBits  Name           Location          BMS LightBit              DCS-BIOS
  -------  -------------  ----------------  ------------------------  --------------
  0        FLCS PMG       MCP 0x21 GPB0     LB3 FlcsPmg    0x00000001  0x447C bit9
  1        MAIN GEN       MCP 0x21 GPB1     LB3 MainGen    0x00000002  0x447C bit10
  2        STBY GEN       MCP 0x21 GPB2     LB3 StbyGen    0x00000004  0x447C bit11
  3        EPU GEN        MCP 0x21 GPB3     LB3 EpuGen     0x00000008  0x447C bit13
  4        EPU PMG        MCP 0x21 GPB4     LB3 EpuPmg     0x00000010  0x447C bit14
  5        FLCS RLY       MCP 0x21 GPB5     LB3 FlcsRly    0x00000040  0x447E bit0
  6        BATT FAIL      MCP 0x21 GPB6     LB3 BatFail    0x00000080  0x447E bit1
  7        BATT TO FLCS   MCP 0x21 GPB7     LB3 ToFlcs     0x00000020  0x447C bit15
  8        EPU HYDRAZN    MCP 0x21 GPA5     LB3 Hydrazine  0x00000100  (미매핑)
  9        EPU AIR        MCP 0x21 GPA6     LB3 Air        0x00000200  (미매핑)
  10       EPU RUN        MCP 0x21 GPA7     LB2 EPUOn      0x00100000  (미매핑)
  11       JFS RUN        Teensy 직결       LB2 JFSOn      0x00200000  (미매핑)

  Backlight: ledBits byte 2 (bits 16~23) = PWM brightness
             Bridge: instrLight 0=OFF→0, 1=DIM→255(기본)/50(BRT감지후), 2=BRT→255
             BRT(instrLight=2) 미수신 시 DIM=255(풀), 수신 후 DIM=50으로 자동 전환
             Offline 수동 조절: UHF STATUS + TF pot → PWM 0~255 (bridge offline일 때만)
  srData   : uint32, ECM 32 LED (74HC595). FlightData2 ecmBits[5] 에서 생성.

  FlightData.h 발췌 (검증된 값):
    LightBits2:  EPUOn      = 0x00100000   bit 20   "EPU panel; run light"
                 JFSOn      = 0x00200000   bit 21   "Eng Jet Start panel; run light"
    LightBits3:  Hydrazine  = 0x00000100   bit 8
                 Air        = 0x00000200   bit 9

  ※ DCS-BIOS 미매핑 4개(bit 8~11): F-16C_50.json 에서 EPU / JFS RUN 식별자를 찾아
    DcsBiosParser.h 의 watch 목록과 dcsBiosOnUpdate() 에 추가하면 됩니다.
    그전까지 DCS 연결 시 해당 LED 는 꺼진 상태로 유지됩니다.

4. Protocol Auto-Detection
===========================

  Teensy receives serial data and auto-detects protocol:
    - 0x55 x4 consecutive  →  DCS-BIOS
    - 0xAA then 0xBB       →  BMS-BIOS
  Timeout (6 sec no data)  →  reset to UNKNOWN, re-detect

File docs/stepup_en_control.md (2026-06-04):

# Step-Up Converter EN Pin Control via MOSFET

## Overview
USB 5V → Step-Up 컨버터 → 12V 백라이트 ON/OFF 제어.
Teensy GPIO 핀 하나로 MOSFET을 통해 EN 핀을 제어한다.

## EN Pin 특성
- **GND 연결 → 컨버터 ON** (12V 출력)
- **Float(미연결) → 컨버터 OFF** (출력 없음)

## GPIO 직결이 안 되는 이유 → MOSFET 필수

Step-Up 매뉴얼에 따르면:
- **EN = LOW (GND) → 컨버터 ON**
- **EN = HIGH → 컨버터 OFF**

GPIO 직결 시 두 가지 문제가 발생한다:

### 1. 3.3V HIGH로는 꺼지지 않는다
Teensy GPIO HIGH = 3.3V인데, Step-Up EN 핀은 5V VIN 기준으로 동작한다.
3.3V는 5V 도메인에서 확실한 HIGH로 인식되지 않아 **컨버터가 꺼지지 않는다.**
(GPIO LOW → EN LOW → ON은 정상 동작하지만, OFF가 안 됨)

### 2. Teensy GPIO는 5V tolerant 하지 않다
Step-Up EN 핀 내부에 5V 풀업 저항이 있을 수 있다.
GPIO를 직결하면 EN 핀을 통해 **5V가 Teensy GPIO에 역류**하여
3.3V 전용인 Teensy 4.1 GPIO가 **손상될 위험**이 있다.

### 해결: N-ch MOSFET
MOSFET을 EN과 GND 사이에 넣으면:
- GPIO는 Gate만 구동 (전류 거의 0, 3.3V로 충분)
- Drain-Source가 EN-GND 스위치 역할 → 확실한 GND 연결
- GPIO와 5V EN 핀이 전기적으로 격리 → Teensy 보호

## 회로

```
Teensy GPIO ──→ 1kΩ ──→ Gate (G)
                              │
                         IRLML6244
                          N-ch MOSFET
                              │
                    Drain (D)     Source (S)
                      │              │
                    EN pin          GND
```

## 동작

| GPIO | MOSFET | EN Pin | Step-Up | 12V |
|---|---|---|---|-----|
| HIGH | ON | GND | ON | 출력 |
| LOW | OFF | Float | OFF | 없음 |

## 부품

| Part | Value | Purpose |
|---|---|---|
| MOSFET | IRLML6244 (N-ch, SOT-23) | EN-GND 스위치, Vgs(th) ~1V → 3.3V GPIO 직접 구동 |
| Resistor | 1kΩ | Gate 직렬 — 스위칭 링잉 방지 |
| Resistor | 220Ω × N | LED 전류 제한 (스트립당 1개) |

- 10K pull-down 불필요: MOSFET은 Step-Up과 상시 연결 (핫플러그 없음)

## LED 백라이트

- 12V → LED × 3 → 220Ω → GND (1개 스트립)
- 최대 15개 스트립 병렬 연결 가능

## USB 3.0 필수

- USB 3.0: 5V / 900mA
- USB 2.0: 5V / 500mA → 스트립 다수 사용 시 전류 부족
- Step-Up 효율 ~85% 고려 시 USB 3.0이 안정적

## 회로도
`stepup_en_circuit.png` 참조 (draw_stepup_en.py로 생성)

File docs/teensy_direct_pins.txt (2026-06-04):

===============================================================
  REDKITE_F16_PANELS - Teensy 4.1 Direct Pin List
===============================================================

--- Digital Output - Backlight ---

Pin   Name                    Note
----  ----------------------  --------------------
  0   Backlight Control       LOW=on, HIGH=off (USB suspend)

--- Digital Input (INPUT_PULLUP) - Switches ---

Pin   Name                    Panel       Type
----  ----------------------  ----------  ----------
  1   DN LOCK REL             Gear        ON/OFF
  2   Horn Silencer           Gear        ON/OFF
  3   Landing Light (pin1)    Gear        ON/OFF/ON
  4   Landing Light (pin2)    Gear        ON/OFF/ON
  5   Store CAT               Gear        ON/OFF
  6   ANTI SKID (pin1)        Gear        ON/OFF/ON
  7   ANTI SKID (pin2)        Gear        ON/OFF/ON
  8   BRAKES Channel          Gear        ON/OFF
  9   GND JETT ENABLE         Gear        ON/OFF
 10   EMER Jettison           Gear        ON/OFF
 11   Hook                    Gear        ON/OFF
 13   ALT GEAR Reset          AltGear     ON/OFF
 14   CMDS JETT               CMDS        ON/OFF
 15   CMDS MWS                CMDS        ON/OFF
 16   CMDS JMR                CMDS        ON/OFF
 17   CMDS RWR                CMDS        ON/OFF
 20   CMDS O1                 CMDS        ON/OFF
 21   CMDS O2                 CMDS        ON/OFF
 22   CMDS CH                 CMDS        ON/OFF
 23   CMDS FL                 CMDS        ON/OFF
 28   Landing Gear (pin1)     Gear        ON/OFF/ON
 29   Landing Gear (pin2)     Gear        ON/OFF/ON
 33   ALT GEAR Handle         AltGear     ON/OFF

--- Digital Output - LEDs ---

Pin   Name                    Panel
----  ----------------------  ----------
 27   Gear Warn               Gear
 30   Nose Gear               Gear
 31   Left Gear               Gear
 32   Right Gear              Gear
 34   TWA Power               TWA
 35   TWA Low                 TWA
 36   TWA Search              TWA
 37   TWA Act                 TWA

--- I2C (MCP23017) ---

Pin   Function
----  ----------------------
 18   SDA (I2C Data)
 19   SCL (I2C Clock)

--- Analog Input - Potentiometer ---

Pin   Name                    Panel       Axis
----  ----------------------  ----------  ----------
A13   HMCS Brightness         HMCS        X
A14   HMCS Contrast           HMCS        Y
A15   HMCS Symbology          HMCS        Z

--- Analog Input - Resistor Ladder Button Arrays ---

Pin   Name                    Panel       Buttons
----  ----------------------  ----------  -------
A10   TWA Buttons             TWA         4
A11   CMDS MODE               CMDS        6
A12   CMDS PRGM               CMDS        5

--- Analog Input - Pedals ---

Pin   Name
----  ----------------------
A16   Pedal Left
A17   Pedal Right

===============================================================
  Pin Usage Summary
===============================================================

Backlight Output:   0                   (1 pin)
Used Digital Pins:  1-11, 13-17, 20-23, 27-37  (31 pins)
Used Analog Pins:   A10-A15, A16-A17           (8 pins)
I2C Pins:           18 (SDA), 19 (SCL)

Note: A10=pin24, A11=pin25, A12=pin26, A13=pin27,
      A14=pin38, A15=pin39, A16=pin40, A17=pin41

Unused Pins:        12

MCP23017 (I2C 0x20) - MISC Panel:
  GPA0-1  Master ARM (ON/OFF/ON)
  GPA2    ALT REL
  GPA3    Laser ARM
  GPA4-5  RF (ON/OFF/ON)
  GPA6    (unused)
  GPA7    ECM LED (output)
  GPB0    ADV Active LED (output)
  GPB1    ADV Standby LED (output)
  GPB2    ADV MODE
  GPB3-4  Roll AP (ON/OFF/ON)
  GPB5-6  Pitch AP (ON/OFF/ON)
  GPB7    (unused)

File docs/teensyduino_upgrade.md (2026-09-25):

# Teensyduino / Arduino IDE 업그레이드 가이드

Arduino IDE 또는 Teensyduino 업데이트 시 코어 파일이 덮어씌워집니다.
업데이트 후 아래 두 파일을 반드시 다시 수정해야 합니다.

코어 파일 경로:
```
%LOCALAPPDATA%\Arduino15\packages\teensy\hardware\avr\<version>\cores\teensy4\
```

---

## 1. usb_desc.h

`#elif defined(USB_SERIAL_HID)` 섹션을 찾아 아래 항목을 수정합니다.

### JOYSTICK_SIZE (두 곳)

`USB_SERIAL` 섹션과 `USB_SERIAL_HID` 섹션에 각각 하나씩 있습니다.

```c
// USB_SERIAL 섹션 (~line 272)
#define JOYSTICK_SIZE         64    //  12 = normal, 64 = extreme joystick

// USB_SERIAL_HID 섹션 (~line 321-322)
//  #define JOYSTICK_SIZE         12    //  12 = normal, 64 = extreme joystick
  #define JOYSTICK_SIZE         64    //  12 = normal, 64 = extreme joystick
```

### PRODUCT_ID

`USB_SERIAL_HID` 섹션에서 변경:

```c
  // #define PRODUCT_ID        0x0487    // Original USB_SERIAL_HID
  // #define PRODUCT_ID        0x048D    // LEFT AUX MISC
  #define PRODUCT_ID           0x048e    // LEFT CONSOLE
  #define BCD_DEVICE 0x0212     // added by kimhy
```

> LEFT_AUX_MISC 빌드 시에는 `0x048D` 를 활성화하고 `0x048e` 를 주석 처리합니다.
> 현재 양쪽 스케치 모두 `JOYSTICK_SIZE 64` 를 사용하므로 전환 시 PID만 바꾸면 됩니다.

---

## 2. usb_desc.c

`#elif JOYSTICK_SIZE == 64` 블록 (extreme joystick) 안의 HID descriptor 를 수정합니다.

### 변경 내용: 슬라이더 Report Count 23 → 8 + padding 15

Teensyduino 원본은 슬라이더 17개를 전부 `Usage 0x36`(Slider)으로 선언합니다.
이 중복으로 인해 Windows DirectInput이 슬라이더를 전혀 인식하지 못합니다.
Report Count 를 8로 줄이고 나머지를 constant padding으로 처리하면 해결됩니다.

**원본 (변경 전):**
```c
        0x75, 0x10,                     // Report Size (16)
        0x95, 23,                       // Report Count (23)
        0x09, 0x30,                     // Usage (X)
        0x09, 0x31,                     // Usage (Y)
        0x09, 0x32,                     // Usage (Z)
        0x09, 0x33,                     // Usage (Rx)
        0x09, 0x34,                     // Usage (Ry)
        0x09, 0x35,                     // Usage (Rz)
        0x09, 0x36,                     // Usage (Slider)
        0x09, 0x36,                     // Usage (Slider)
        0x09, 0x36,                     // Usage (Slider)
        0x09, 0x36,                     // Usage (Slider)
        0x09, 0x36,                     // Usage (Slider)
        0x09, 0x36,                     // Usage (Slider)
        0x09, 0x36,                     // Usage (Slider)
        0x09, 0x36,                     // Usage (Slider)
        0x09, 0x36,                     // Usage (Slider)
        0x09, 0x36,                     // Usage (Slider)
        0x09, 0x36,                     // Usage (Slider)
        0x09, 0x36,                     // Usage (Slider)
        0x09, 0x36,                     // Usage (Slider)
        0x09, 0x36,                     // Usage (Slider)
        0x09, 0x36,                     // Usage (Slider)
        0x09, 0x36,                     // Usage (Slider)
        0x09, 0x36,                     // Usage (Slider)
        0x81, 0x02,                     // Input (variable,absolute)
```

**수정 후:**
```c
        0x75, 0x10,                     // Report Size (16)
        0x95, 8,                        // Report Count (8)
        0x09, 0x30,                     // Usage (X)
        0x09, 0x31,                     // Usage (Y)
        0x09, 0x32,                     // Usage (Z)
        0x09, 0x33,                     // Usage (Rx)
        0x09, 0x34,                     // Usage (Ry)
        0x09, 0x35,                     // Usage (Rz)
        0x09, 0x36,                     // Usage (Slider)
        0x09, 0x36,                     // Usage (Slider)
        0x81, 0x02,                     // Input (variable,absolute)
        0x95, 15,                       // Report Count (15)
        0x81, 0x01,                     // Input (constant) — padding
```

USB report 크기(64바이트)는 변하지 않습니다.

---

## 검증 체크리스트

1. `usb_desc.h` — `JOYSTICK_SIZE 64` 두 곳 확인
2. `usb_desc.h` — `PRODUCT_ID 0x048E` (LEFT CONSOLE) 확인
3. `usb_desc.c` — Report Count `8` + padding `15` 확인
4. Arduino IDE에서 빌드 → 업로드
5. joy.cpl에서 X/Y/Z/Rx/Ry/Rz + Slider 0/1 = 8축 동작 확인

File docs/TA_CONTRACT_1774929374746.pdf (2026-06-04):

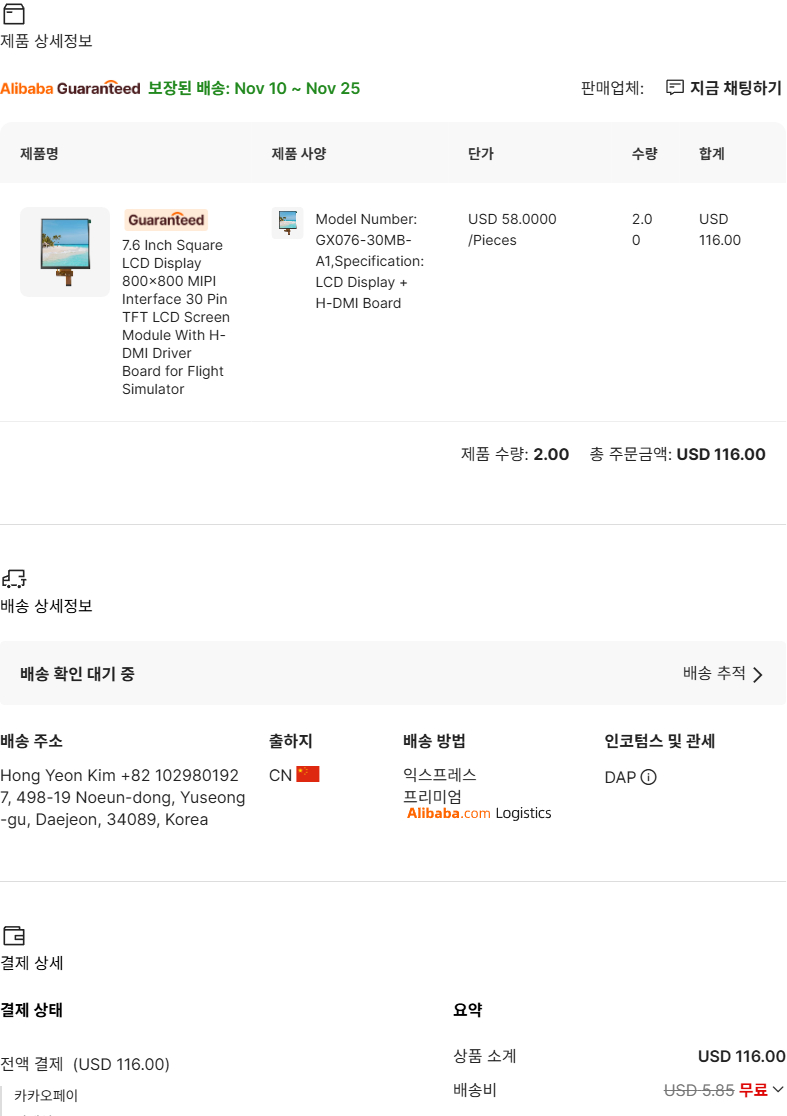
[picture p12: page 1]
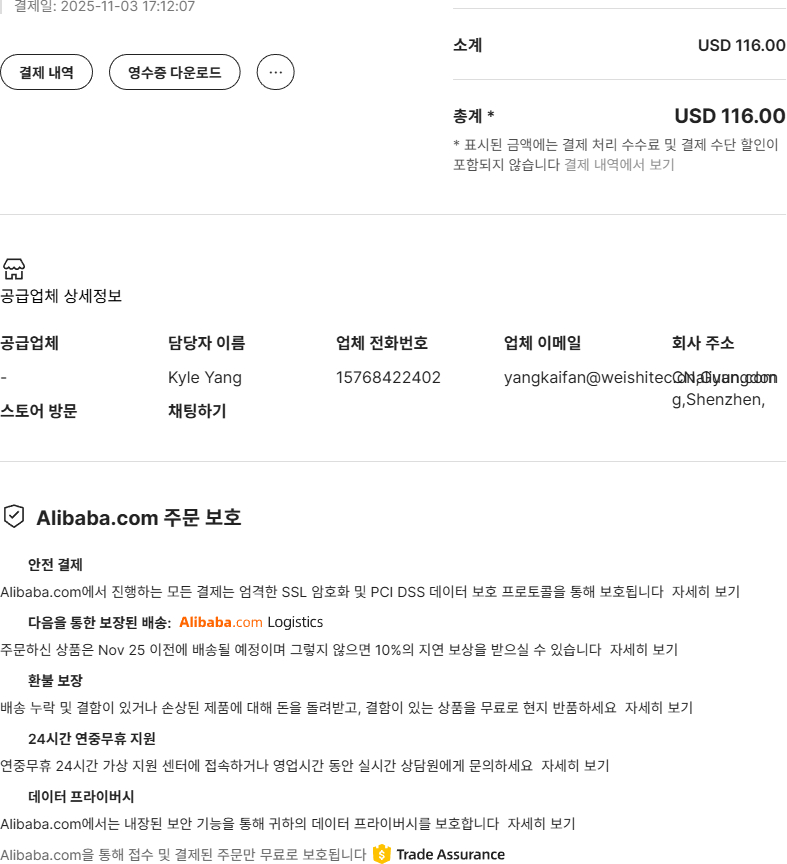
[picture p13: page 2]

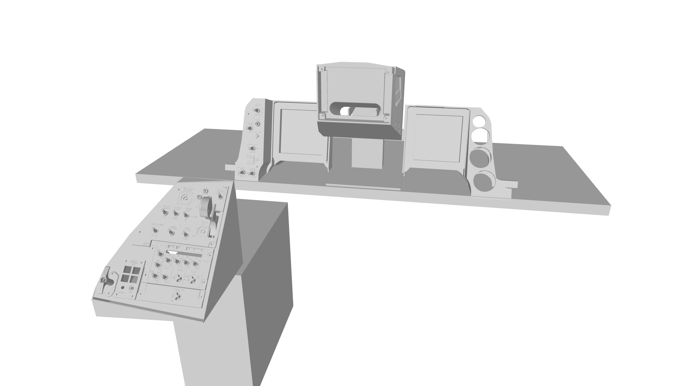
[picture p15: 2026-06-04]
docs/3d stl/My Cockpit.png

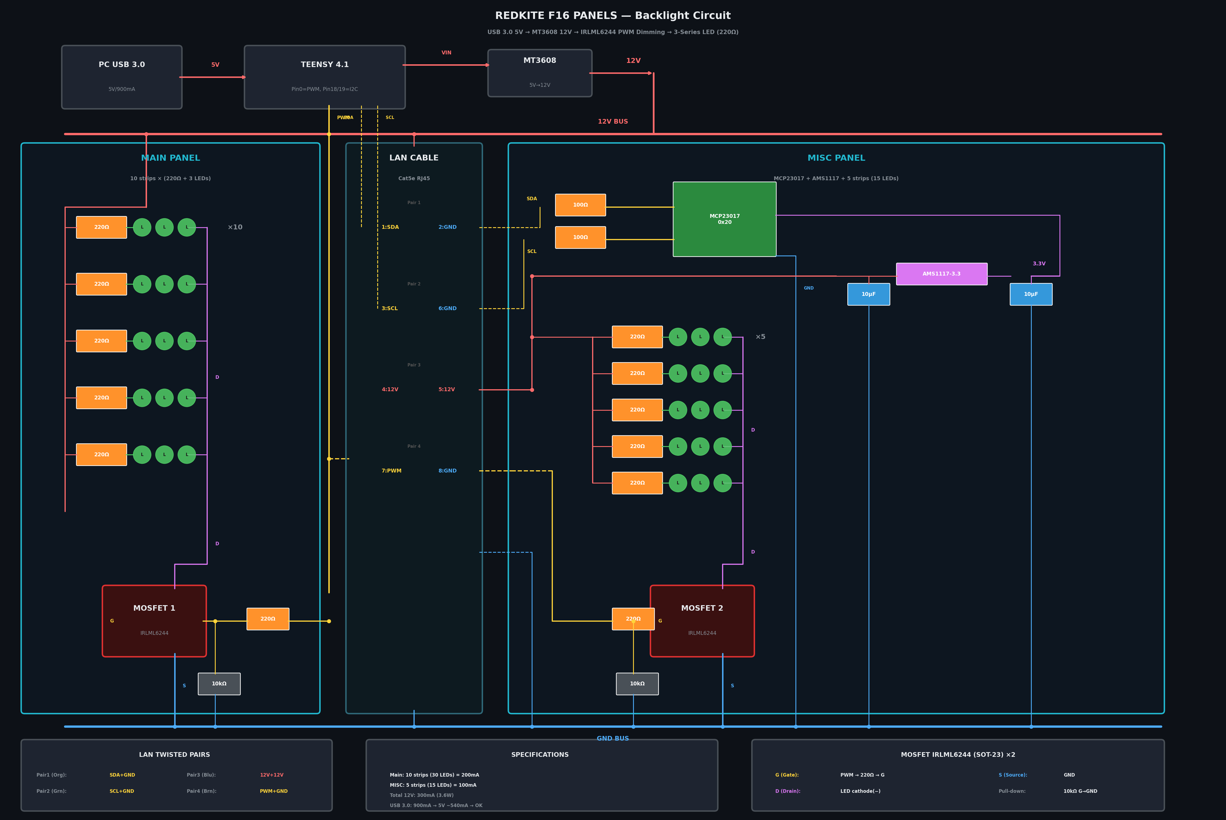
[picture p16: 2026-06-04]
docs/backlight_circuit.png

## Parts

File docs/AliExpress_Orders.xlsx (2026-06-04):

# | 이미지 | 주문일 | 스토어 | 품목명 | 옵션/SKU | 수량 | 단가 | 금액 | 비고
전체 71건 (주문 57건)
1 |  | 2026년 3월 25일 | LXQY Store Store | 10V 16V 25V 35V 50V 400V 450V DIP Aluminum Electrolytic Capacitor 100UF 220UF 330UF 470UF 680UF 1000UF 10UF 22UF 47UF 0.47UF | 25V 10UF 40PCS, China Mainland | 1 | $1.74 | $1.74
2 |  | 2026년 3월 25일 | LXQY Store Store | 100pcs/200pcs 50V monolithic ceramic capacitor 10PF 22PF 100P 47NF 220NF 1NF 4.7UF 1UF 100NF 330NF 0.1UF 102 104 105 P=5.08mm | 100NF, China Mainland, 100PCS | 1 | $2.18 | $2.18
3 |  | 2026년 3월 21일 | MOGAI Chip Store | (50pcs)New IRLML2502 IRLML2402 IRLML2803 IRLML0030 IRLML5203 IRLML6244 IRLML6344 IRLML6401 IRLML6402 IRLML0040 TRPBF | IRLML6244 | 1 | $1.76 | $1.76
4 |  | 2026년 3월 21일 | Electrical Kingdom | 1Pcs Metal Round Socket Module D Type RJ45 Straight Through Network USB2.0 USB3.0 Connector Panel Mounting HDMI CAT6 | USB2.0 Black | 1 | $1.02 | $1.02
5 |  | 2026년 3월 21일 | LXQY Store Store | 10V 16V 25V 35V 50V 400V 450V DIP Aluminum Electrolytic Capacitor 100UF 220UF 330UF 470UF 680UF 1000UF 10UF 22UF 47UF 0.47UF | 25V 100UF 40PCS, China Mainland | 1 | $1.86 | $1.86
6 |  | 2026년 3월 14일 | R(消费电子) 케이블 공장 스토어 | 1pc D Type Wall Panel Mount RJ45 Cat5/5e/6 Connector 8p8c Shielded Network Female Socket Industrial RJ45 Male Ethernet Plug | 1xA1008 | 1 | $1.81 | $1.81
7 |  | 2026년 3월 14일 | Shop1104633786 Store | 2.54mm Dupont Connector 1 2*2/3/4/5/6/7/8/9/10/20P Single Double Row Connector Shell Plug Jumper Wire Cable Pin Header Terminals | 100PCS TJC8-TA | 1 | $1.75 | $1.75
8 |  | 2026년 3월 14일 | Shop1104633786 Store | 2.54mm Dupont Connector 1 2*2/3/4/5/6/7/8/9/10/20P Single Double Row Connector Shell Plug Jumper Wire Cable Pin Header Terminals | 100PCS TJC8-T-D | 1 | $1.53 | $1.53
9 |  | 2026년 3월 14일 | Shop1104633786 Store | 2.54mm Dupont Connector 1 2*2/3/4/5/6/7/8/9/10/20P Single Double Row Connector Shell Plug Jumper Wire Cable Pin Header Terminals | 100PCS 1PIN | 1 | $1.66 | $1.66
10 |  | 2026년 3월 13일 | QJSET 공식 스토어 | 100pcs 1/4W Metal Film Resistor Element 1% 0.25W 1K 1.5K 2.2K 4.7K 10K 22K 47K 100K 470k 100 220 4K7 Ohm 5 Color Ring Resistors | 10k ohm | 1 | $1.16 | $1.16
11 |  | 2026년 3월 13일 | QJSET 공식 스토어 | 100pcs 1/4W Metal Film Resistor Element 1% 0.25W 1K 1.5K 2.2K 4.7K 10K 22K 47K 100K 470k 100 220 4K7 Ohm 5 Color Ring Resistors | 4.7k ohm | 1 | $1.16 | $1.16
12 |  | 2026년 3월 13일 | QJSET 공식 스토어 | 100pcs 1/4W Metal Film Resistor Element 1% 0.25W 1K 1.5K 2.2K 4.7K 10K 22K 47K 100K 470k 100 220 4K7 Ohm 5 Color Ring Resistors | 1k ohm | 1 | $1.17 | $1.17
13 |  | 2026년 3월 13일 | QJSET 공식 스토어 | 100pcs 1/4W Metal Film Resistor Element 1% 0.25W 1K 1.5K 2.2K 4.7K 10K 22K 47K 100K 470k 100 220 4K7 Ohm 5 Color Ring Resistors | 220 ohm | 1 | $1.17 | $1.17
14 |  | 2026년 3월 11일 | Advanced Tech | MCP23017 Serial Interface Module IIC I2C SPI MCP23S17 Bidirectional 16-Bit I/O Expander Pins 10Mhz Serial Interface Module | Blue | 4 | $1.42 | $5.68
15 |  | 2026년 3월 8일 | Jaytom Online Store | 2pcs High-quality SR26 Band Rotary Channel Selector Switch 1/2/3/4 Pole 12/6/4/3 Position Soldering Pins Handle Length 38MM | 1 Pole 12 Position | 2 | $4.32 | $8.64
16 |  | 2026년 3월 8일 | TMYSY Store | 5ml 10ml 20ml 30ml 100ml 120ml PE Plastic Squeezable Tip Applicator Bottle Refillable Dropper with Needle Tip Caps Oil Bottles | 10ml | 1 | $0.73 | $0.73
17 |  | 2026년 3월 8일 | NINDEJIN NINDEJIN Official Store | Black Hexagon Hex Nuts M2 M2.5 M3 M4 M5 M6 M8 M10 M12 M14 M16 M18 M20 M22 M24 M27 carbon steel metric hex nuts | M3 55pcs | 1 | $1.24 | $1.24
18 |  | 2026년 2월 28일 | Shop1104038616 Store | Under Desk Keyboard Tray Slide Rail Drawer with Height Adjustable Table Accessories Retractable Mouse Stand for PC Workstation | Black 24x55cm | 1 | $10.28 | $10.28
19 |  | 2026년 2월 27일 | eletechsup Outlet Store | with Enable ON/OFF DC-DC 3V 3.3V 3.7V 4.2V 5V to 5V 6V 9V 12V Step-up Boost Converter Voltage Regulate Power Supply Module Board | 12V(with Pin) | 2 | $1.98 | $3.96
20 |  | 2026년 2월 20일 | EDGAR GARY Store | M2 M2.5 M3 M4 M5 M6 Brass Insert Nut Hot Melt Heat Knurled Embed Injection Copper Insertnut 3D Print Plastic Board Nuts Inserts | 30PCS, M3xL6xOD4 | 1 | $2.57 | $2.57
21 |  | 2026년 2월 20일 | EDGAR GARY Store | M2 M2.5 M3 M4 M5 M6 Brass Insert Nut Hot Melt Heat Knurled Embed Injection Copper Insertnut 3D Print Plastic Board Nuts Inserts | 30PCS, M3xL5xOD4 | 1 | $2.68 | $2.68
22 |  | 2026년 2월 20일 | House Improvement Store | 5Pcs 900M-T Soldering Iron Tips IS/I/B/K/SK/2.4D/3.2D/1C/2C/3C/4C Lead-Free Welding Tips Head | 900M-T-K, China Mainland | 1 | $2.32 | $2.32
23 |  | 2026년 2월 20일 | House Improvement Store | 5Pcs 900M-T Soldering Iron Tips IS/I/B/K/SK/2.4D/3.2D/1C/2C/3C/4C Lead-Free Welding Tips Head | 900M-T-B, China Mainland | 1 | $2.06 | $2.06
24 |  | 2026년 2월 20일 | YMAX Official Store | Heat Insertion for 3D Printer Plastic Tool Brass Threaded Insert Nut Manual ABS Press DIY Simple Machine Soldering Iron Hot Melt | M2-M8 Insert | 1 | $2.24 | $2.24
25 |  | 2026년 2월 15일 | SKT Hardware Electricians DIY Store | 22AWG Electric Wire Flexible Silicone Wires 22 Gauge Stranded Tinned Copper Wire 5 Colors 16.4ft/5m Each or 32.8ft/10m Each | 22 AWG, 50m (10m Each) | 1 | $4.66 | $4.66
26 |  | 2026년 2월 15일 | YEFYM Quality Store | 5-in-1 Multifunctional Automatic Wire Stripping Pliers(0.25-10mm2) YES-1R Crimping, Cutting, Splitting, And Merging Wires Tools | YES-1R | 1 | $6.93 | $6.93
27 |  | 2026년 2월 15일 | ENLINCA Official Store | 127-750pcs Heat-shrink Tubing Thermoresistant Tube Heat Shrink Wrapping Kit Electrical Connection Wire Cable Insulation Sleeving | 750Pcs in Box | 1 | $1.99 | $1.99
28 |  | 2026년 2월 12일 | NINDEJIN NINDEJIN Official Store | Black Hexagon Hex Nuts M2 M2.5 M3 M4 M5 M6 M8 M10 M12 M14 M16 M18 M20 M22 M24 M27 carbon steel metric hex nuts | M4 55pcs | 1 | $1.41 | $1.41
29 |  | 2026년 2월 12일 | NINDEJIN NINDEJIN Official Store | NINDEJIN Hexagon Hex Socket Cap Head Screw Bolts M1.6 M2 M2.5 M3 M4 M5 M6 M8 M10 12.9 Grade Carbon Steel Allen Screw DIN912 | M4 20pcs, 20mm | 2 | $1.52 | $3.04
30 |  | 2026년 2월 10일 | Two Magnet Store | 15x3mm circular strong magnet suitable for photo walls bathroom accessories homes, cabinet doors, Christmas DIY, graffiti crafts | 15x3mm-6pcs | 1 | $1.80 | $1.80
31 |  | 2026년 2월 10일 | TriArk Electronic Components Store | 100PCS/Lot Metal Film Resistor 1/4W 1% 100R 220R 1K 1.5K 2.2K 4.7K 10K 22K 47K 100K 100 220 1K5 2K2 4K7 Ohm Resistance 1R~22M | 150R | 1 | $1.18 | $1.18
32 |  | 2026년 2월 10일 | TriArk Electronic Components Store | 100PCS/Lot Metal Film Resistor 1/4W 1% 100R 220R 1K 1.5K 2.2K 4.7K 10K 22K 47K 100K 100 220 1K5 2K2 4K7 Ohm Resistance 1R~22M | 100R | 1 | $1.15 | $1.15
33 |  | 2026년 2월 10일 | Shop1103734083 Store | 20Pin Dupont Line Male To Male Female To Female Male To FeMale Jumper Wire Cable 10cm 20cm 30cm for Arduino DIY KIT | 30cm, Female to Female, 20pin | 2 | $1.17 | $2.34
34 |  | 2026년 2월 9일 | READYYEAH Official Store | 1/5/10 Pcs Mechanical Keyboard Switch For Red Blue Brown Black Switch Gaming Keyboard Accessories Smooth With Silent Custom Axis | Brown and White, 1pcs | 2 | $0.79 | $1.58
35 |  | 2026년 2월 9일 | HUI JI 공식 스토어 | Black Carbon Steel M2 M2.5 M3 M4 M5 M6 M8 Cross Recessed Phillips Truss Head Large Flat Round Head Screw Bolt | M3X14 (50pcs) | 1 | $2.94 | $2.94
36 |  | 2026년 2월 8일 | WAVTZT Authorization Store | 1PCS RS16 RS26 Plastic Rotary Band Switch 2 Pole 3 4 Position 1 Pole 5 6 8 Position Handle Length Axis Band Switch Ibuw RS16 | RS16 1 Pole 6 | 2 | $1.43 | $2.86
37 |  | 2026년 2월 8일 | WAVTZT Authorization Store | 1PCS RS16 RS26 Plastic Rotary Band Switch 2 Pole 3 4 Position 1 Pole 5 6 8 Position Handle Length Axis Band Switch Ibuw RS16 | RS16 1 Pole 5 | 2 | $1.47 | $2.94
38 |  | 2026년 2월 8일 | Shop1103181386 Store | 5Pcs RK097N 3Pin Potentiometers Industrial Switches B1K 5K 10K 20K 50K 100K 500K Switch Audio Shaft 15mm Amplifier Sealing RK097 | 10K Ohm | 2 | $1.51 | $3.02
39 |  | 2026년 2월 8일 | Shop1103734083 Store | 20Pin Dupont Line Male To Male Female To Female Male To FeMale Jumper Wire Cable 10cm 20cm 30cm for Arduino DIY KIT | 30cm, Female to Female, 20pin | 1 | $1.22 | $1.22
40 |  | 2026년 2월 8일 | CHANZON Tech Store | 100pcs 3mm LED Diode Ultra Bright Warm White Red Green Blue UV Purple Yellow Orange Pink 2V 3V Multicolor Emitting Assortment | 100pcs Green, China Mainland | 1 | $2.24 | $2.24
41 |  | 2026년 2월 8일 | EDGAR GARY Store | M2 M2.5 M3 M4 M5 M6 Brass Insert Nut Hot Melt Heat Knurled Embed Injection Copper Insertnut 3D Print Plastic Board Nuts Inserts | 30PCS, M3xL4xOD5 | 1 | $2.70 | $2.70
42 |  | 2026년 2월 8일 | EDGAR GARY Store | M2 M2.5 M3 M4 M5 M6 Brass Insert Nut Hot Melt Heat Knurled Embed Injection Copper Insertnut 3D Print Plastic Board Nuts Inserts | 30PCS, M3xL6xOD5 | 1 | $3.03 | $3.03
43 |  | 2026년 2월 8일 | Shop1103919055 Store | 100pcs 1% 1206 SMD resistor 0R 10R 22R 100R 330R 470R 1K 2.2K 3.3K 4.7K 10K 22K 47K 100K 200K 510K 1M ohm | 10K | 1 | $1.55 | $1.55
44 |  | 2026년 2월 8일 | Shop1103919055 Store | 100pcs 1% 1206 SMD resistor 0R 10R 22R 100R 330R 470R 1K 2.2K 3.3K 4.7K 10K 22K 47K 100K 200K 510K 1M ohm | 2.2K | 1 | $1.55 | $1.55
45 |  | 2026년 2월 8일 | Shop1103919055 Store | 100pcs 1% 1206 SMD resistor 0R 10R 22R 100R 330R 470R 1K 2.2K 3.3K 4.7K 10K 22K 47K 100K 200K 510K 1M ohm | 220R | 1 | $1.55 | $1.55
46 |  | 2026년 2월 8일 | DQLZV Official Store | 20/50PCS SMD Switch 6*6*4.3mm 5/6/7/8/9/10/11/12/13/14/17 6X6 4Pin Tactile Tact Push Button Micro Switch Self-reset Switches | 6x6x4.3mm, 20PCS | 1 | $0.97 | $0.97
47 |  | 2026년 2월 8일 | Sunny Business | 200PCS/50Pairs Female Male Spade Crimp Terminals Sleeve Wire Wrap Connector for 22-16 AWG 0.5-1.5mm2 2.8mm 6.3mm 4.8mm | 2.8mm | 2 | $5.23 | $10.46
48 |  | 2026년 2월 8일 | XMS Store | 10PCS Micro Limit Switch Momentary Push Button Switch 1A 125V AC Mouse Switch 3Pins Long Handle Roller Lever Arm SPDT 12X6X6MM | MS-1A-L13.5 | 1 | $1.42 | $1.42
49 |  | 2026년 2월 8일 | NINDEJIN NINDEJIN Official Store | Black Hexagon Hex Nuts M2 M2.5 M3 M4 M5 M6 M8 M10 M12 M14 M16 M18 M20 M22 M24 M27 carbon steel metric hex nuts | M3 55pcs | 1 | $1.27 | $1.27
50 |  | 2026년 2월 8일 | ZSDZFYLLK Store | 6PCS PBS-110 7MM Momentary Push Button Switch Press The Reset Switch Momentary ON OFF Push Button Micro Switch Normally Open | White 6PCS | 2 | $2.34 | $4.68
51 |  | 2026년 2월 8일 | CanHuiSheng Store | 100pcs 50V Ceramic Capacitor 100NF 104 0.1UF 1NF 102 10NF 103 0.01UF 100PF 101 10 22 33 47PF 220 330 470NF 22 33 47NF 473 | 1NF 1000PF 102 | 1 | $1.39 | $1.39
52 |  | 2026년 2월 8일 | TLZWLA Official Store | 5PCS 3Pin C-NO-NC 6MM Mini Momentary Automatic return Push Button Switch ON-(ON) 2A 250VAC/5A 120VAC | Yellow | 1 | $2.51 | $2.51
53 |  | 2026년 2월 8일 | GUXINWAY Store | 3MM 5MM Light Emitting Diode Electronic Kit Box F3 F5 LED Diode Various Kits White Green Red Blue Yellow | 3MM5MM-Box-300pcs | 1 | $3.21 | $3.21
54 |  | 2026년 2월 8일 | Stlxy Official Store | 50/20/10Pcs 2.54mm Single Row Male 1/2*40P PCB Board Pin Header Connector Strip Pinheader 2/3/4/5/6/8/10/12/20/40Pin For Arduino | 1X30Pin (10PCS) | 1 | $1.46 | $1.46
55 |  | 2026년 2월 8일 | NEWHONGHUIDA Official Store | M2 M3 M4 M5 M6 Hex Socket Allen Screw Nut Set 304 Stainless Steel ISO7380 Hexagonal Metric Thread Machine Bolts Screws Nuts Kits | Bolt Nut Set, M2, 12mm (15Pcs) | 1 | $1.41 | $1.41
56 |  | 2026년 2월 8일 | Super2 Store | 1-10pcs Diameter1.6-20mm brass bar rod brass round bar length100-450mm stick for knife handle part diy accessories | 100mm, 6mm 1pcs | 1 | $2.56 | $2.56
57 |  | 2026년 2월 8일 | StarLanguage Store | SH T80-T Z1 Series Large Long Handle 12mm Panel Mount Mini Toggle Switch 2A/250VAC 5A/125VAC | 3P On-Off-On 18.5mm, 1PCS | 20 | $1.17 | $23.40
58 |  | 2026년 2월 8일 | StarLanguage Store | SH T80-T Z1 Series Large Long Handle 12mm Panel Mount Mini Toggle Switch 2A/250VAC 5A/125VAC | 3P On-On 18.5mm, 1PCS | 20 | $1.15 | $23.00
61 |  | 2026년 2월 7일 | HUI JI 공식 스토어 | Black Carbon Steel M2 M2.5 M3 M4 M5 M6 M8 Cross Recessed Phillips Truss Head Large Flat Round Head Screw Bolt | M3X6 (100pcs) | 1 | $2.86 | $2.86
66 |  | 2025년 11월 20일 | Ali-hhjimm Familiy Store | 1Pc 5 Keys Button Keyboard Plate LCD TV Accordance Keypad Board For MR6 LCD Monitor Universal TV Switch controller board | 1pc | 2 | $1.58 | $3.16
69 |  | 2025년 11월 14일 | HUI JI 공식 스토어 | Nylon Standoff Spacer Dia.4mm 5mm 6mm 8mm Plastic Pillar Rack Moutherboard PCB Circuit Board Mount Column Support Stand off | 20pcs, 4mm | 1 | $1.80 | $1.80
합계 |  |  |  |  |  |  |  | $199.61

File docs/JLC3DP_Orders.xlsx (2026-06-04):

JLC3DP 주문 내역 정리
생성일: 2026-03-31 | 전체 4건
# | 이미지 | 파일명 | 기술/소재 | 색상 | 크기(cm) | 표면처리 | 수량 | 단가 | 합계
1 |  | Wheels LED Housing Glass - new.stl | SLA / 8001 Resin | Translucent | 1.3×1.3×0.25 | No | 4 | $0.31 | $1.24
2 |  | Wheels LED Housing - new.stl | SLA / 9600 Resin | Matte White | 1.5×1.5×1.5 | Sanding | 4 | $0.31 | $1.24
3 |  | Gear Led Layer - standoff.stl (백라이트용) | SLA / 9600 Resin | Matte White | 20.56×15.95×0.3 | No | 1 | $5.79 | $5.79
4 |  | MISC Led Layer - standoff.stl (백라이트용) | SLA / 9600 Resin | Matte White | 19.45×6.34×0.3 | No | 1 | $2.22 | $2.22
5 |  | CMDS Led Layer - Standoff.stl (백라이트용) | SLA / 9600 Resin | Matte White | 14.5×9.6×0.3 | No | 1 | $3.29 | $3.29
6 |  | pushbutton - lower body.stl | SLA / 8001 Resin | Translucent | 1.75×1.75×0.61 | No | 4 | $0.31 | $1.24
2 |  | Gear Lever.stl | SLA / 9600 Resin | Matte White | 16.95×5.59×2.08 | No | 1 | $3.71 | $3.71
3 |  | Gear Lever Top Cap.stl | SLA / 8001 Resin | Translucent | 3.83×2.96×1.8 | No | 1 | $1.73 | $1.73
4 |  | 1TL1 6.05mm (x2).stl | SLA / 9600 Resin | Matte White | 2.52×1.09×1.09 | Sanding | 5 | $0.31 | $1.55
5 |  | Lights Switch Cap.stl | SLA / 9600 Resin | Matte White | 2.7×2.69×1.03 | No | 2 | $0.31 | $0.62
6 |  | 12TW1 6.05mm (x2).stl | SLA / 9600 Resin | Matte White | 2.77×1.06×1.06 | Sanding | 5 | $0.31 | $1.55
7 |  | Rotary E - Centerline.stl | SLA / 9600 Resin | Matte White | 1.08×0.75×0.24 | No | 1 | $0.31 | $0.31
8 |  | Rotary D - Centerline.stl | SLA / 9600 Resin | Matte White | 1.97×0.97×0.24 | No | 1 | $0.31 | $0.31
11 |  | 8856K7 6.05mm.stl | SLA / 9600 Resin | Matte White | 2.21×1.09×1.09 | No | 3 | $0.31 | $0.93
12 |  | DZUS v3 M4(TVP).stl | SLA / 9600 Resin | Matte White | 0.95×0.95×0.65 | No | 30 | $0.31 | $9.30
13 |  | Rotary H - Centerline.stl | SLA / 9600 Resin | Matte White | 1.34×0.71×0.24 | No | 1 | $0.31 | $0.31
14 |  | Rotary D - Main Body.stl | SLA / 9600 Resin | Matte White | 2.24×2.24×1.91 | No | 1 | $0.43 | $0.43
15 |  | Rotary H - Main Body.stl | SLA / 9600 Resin | Matte White | 1.62×1.62×1.6 | No | 1 | $0.31 | $0.31
16 |  | Rotary E - Main Body.stl | SLA / 9600 Resin | Matte White | 1.5×1.5×1.38 | Sanding | 1 | $0.31 | $0.31
20 |  | pushbutton - lower body.stl | SLA / 9600 Resin | Matte White | 1.75×1.75×0.61 | No | 4 | $0.31 | $1.24
21 |  | Main Body.stl | SLA / 9600 Resin | Matte White | 8.9×4.8×1.05 | Sanding | 1 | $0.99 | $0.99
22 |  | SEARCH Top Cap.stl | SLA / 9600 Resin | Matte White | 1.5×1.5×0.25 | No | 1 | $0.31 | $0.31
33 |  | ACT-PWR Top Cap.stl | SLA / 9600 Resin | Matte White | 1.5×1.5×0.25 | No | 1 | $0.31 | $0.31
34 |  | LOW ALT Top Cap.stl | SLA / 9600 Resin | Matte White | 1.5×1.5×0.25 | No | 1 | $0.31 | $0.31
35 |  | SYS-PWR Top Cap.stl | SLA / 9600 Resin | Matte White | 1.5×1.5×0.25 | No | 1 | $0.31 | $0.31
36 |  | Top Layer - engraved letters.stl | SLA / 9600 Resin | Matte White | 8.9×4.8×0.2 | Sanding | 1 | $0.55 | $0.55
37 |  | Fuse.stl | SLA / 9600 Resin | Matte White | 2.75×1.43×1.43 | Sanding | 1 | $0.31 | $0.31
45 |  | Schaltplan TWA v35 (PCB) | PCB / FR-4 2L | Green | 42×53.6mm | - | 5 | $0.40 | $2.00
1 |  | Pullrod Housing.stl | MJF / PA12-HP Nylon | Natural Gray | 7.2×6.24×3.2 | No | 1 | $14.51 | $14.51
2 |  | Top Layer.stl | MJF / PA12-HP Nylon | Natural Gray | 5.6×2.9×0.3 | No | 1 | $1.15 | $1.15
3 |  | Handle.stl | MJF / PA12-HP Nylon | Natural Gray | 6×4.4×1.4 | No | 1 | $2.29 | $2.29
4 |  | Pullrod.stl | MJF / PA12-HP Nylon | Natural Gray | 9.4×1.03×1.03 | No | 1 | $2.04 | $2.04
5 |  | Pullrod routing pin.stl | MJF / PA12-HP Nylon | Natural Gray | 1.86×1.65×0.6 | No | 1 | $0.92 | $0.92
 |  |  |  |  |  |  |  | 합계 | $63.63
 |  |  |  |  |  |  |  | 배송비 | $20.00

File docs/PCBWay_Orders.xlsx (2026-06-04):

PCBWay 주문 내역 정리
생성일: 2026-03-31 | 전체 2건
# | 이미지 | 파일명 | 소재 | 수량 | 단가 | 빌드타임 | 합계
2 |  | Right Enclosure - new.stl | PETG | 1 | $26.13 | 3-4 days | $26.13
3 |  | Right Stand - new.stl | PETG | 1 | $10.46 | 2-4 days | $10.46
4 |  | Left Stand - new.stl | PETG | 1 | $10.71 | 2-4 days | $10.71
5 |  | Enclosure - OnePiece2.stl | PETG | 1 | $46.06 | 3-4 days | $46.06
4 |  | Left Enclosure.stl | PETG | 1 | $25.39 | 3-4 days | $25.39
 |  |  |  |  |  |  | $118.75
 |  |  |  |  |  | 배송료 별도 (약 $50)

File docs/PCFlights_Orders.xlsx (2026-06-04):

PCFlights 주문 내역 정리
업데이트: 2026-03-31 | 전체 1건
# | 주문일 | 주문번호 | 유형 | 제품금액 | 배송비 | 쿠폰/관부가세 | 총액
1 | 2026-02-23 | #5632 | Panel | $133.00 | $30.50 | - | $163.50
 |  |  |  |  |  | 총 합계: | $163.50
# | 이미지 | 제품명 | 모델 | 수량 | 단가 | 합계
1 |  | F-16C "Viper" CMDS Control Panel Flight Sim Part | F16-C3 | 1 | $45.00 | $45.00
2 |  | F-16C "Viper" Landing Gear Panel Flight Simulator Part | F16-C2 | 1 | $49.00 | $49.00
3 |  | F-16C "Viper" Miscellaneous (MISC) Panel Flight Simulator Part | F16-C1 | 1 | $39.00 | $39.00
 |  |  |  |  | 소계 | $133.00
 |  |  |  |  | 배송비 (First-Class Intl) | $30.50
 |  |  |  |  | 합계 | $163.50

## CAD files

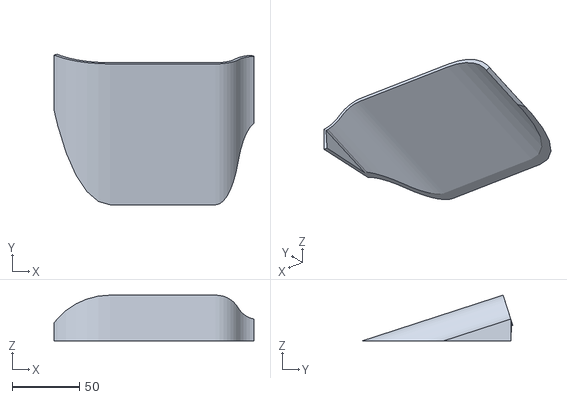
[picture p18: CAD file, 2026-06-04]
docs/3d stl/Right Stand.stl
148.3 x 111.7 x 33.9

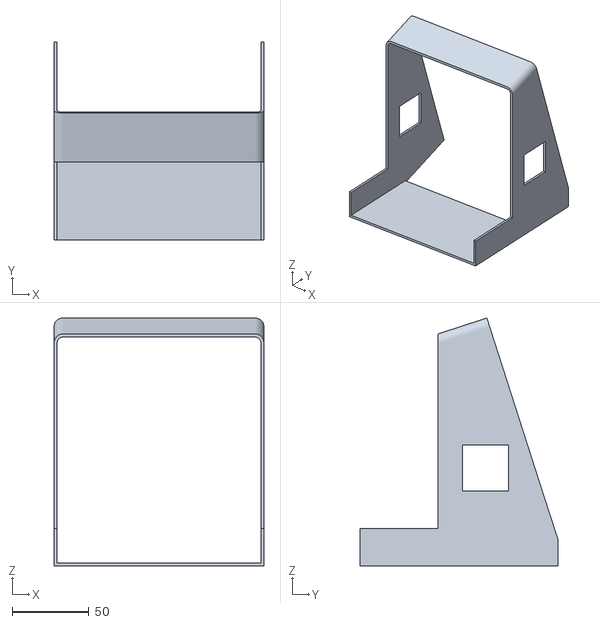
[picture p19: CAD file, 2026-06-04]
docs/3d stl/Right Stand- new.stl
137.1 x 129.2 x 162.0

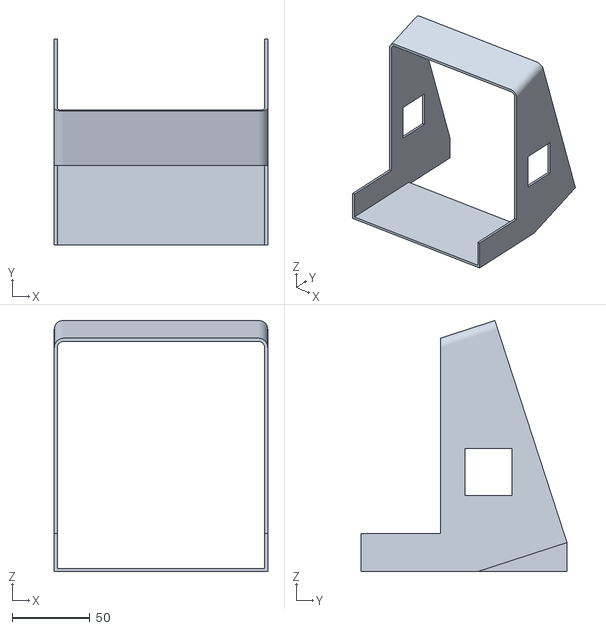
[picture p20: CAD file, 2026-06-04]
docs/3d stl/Left Stand - new.stl
137.1 x 132.3 x 161.2

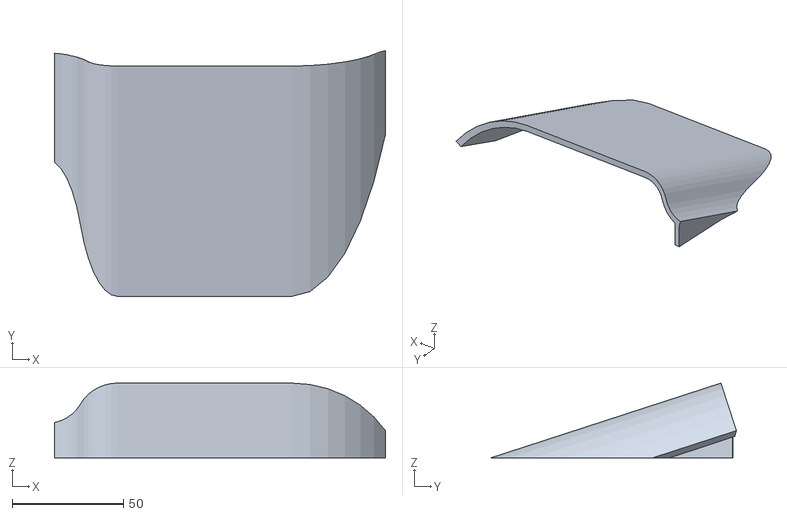
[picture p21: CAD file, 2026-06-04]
docs/3d stl/Left Stand.stl
148.8 x 110.5 x 33.7

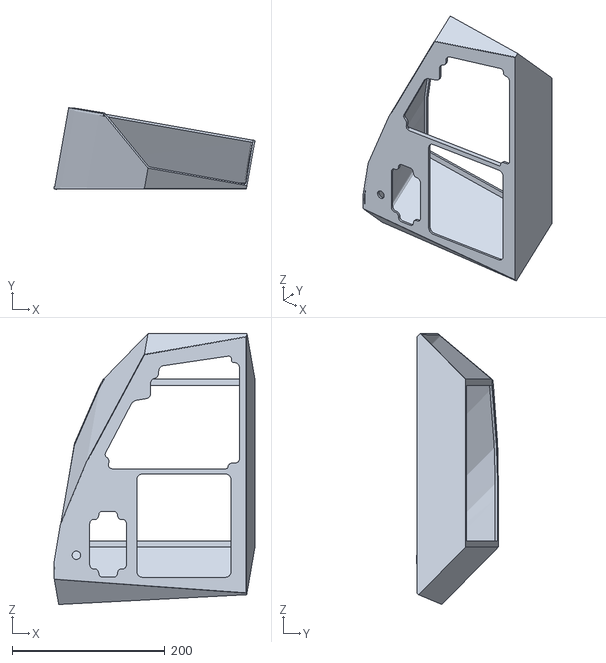
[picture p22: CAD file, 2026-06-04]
docs/3d stl/Enclosure - OnePiece2.stl
263.2 x 107.0 x 355.0

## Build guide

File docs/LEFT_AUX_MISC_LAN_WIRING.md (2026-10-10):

# LEFT_AUX ↔ MISC 패널 LAN 배선도

Teensy (AUX 통) ↔ MCP23017 (MISC 패널) 간 Cat5e LAN 케이블 연결.
I2C 풀업, 핫플러그 보호, PWM 백라이트 디밍 포함.

## LAN 핀 배정

| Pin | Pair | Signal | 비고 |
|-----|---|---|---|
| 1 | Pair 1 (Orange) | SDA | |
| 2 | Pair 1 | GND | SDA 리턴 |
| 3 | Pair 2 (Green) | SCL | |
| 6 | Pair 2 | GND | SCL 리턴 |
| 4 | Pair 3 (Blue) | 12V dimmed | MOSFET 출력 (PWM) |
| 5 | Pair 3 | LED return | GND |
| 7 | Pair 4 (Brown) | 3.3V | MCP23017 전용 |
| 8 | Pair 4 | GND | 3.3V 리턴 |

## 회로도

### AUX 통 (Teensy 측)

```
                 4.7kΩ
Teensy 3.3V ──┬──┤├──── Teensy SDA (18) ──────────── LAN pin 1
              │
              └──┤├──── Teensy SCL (19) ──────────── LAN pin 3
                 4.7kΩ

GND ──────────────────────────────────────────────── LAN pin 2
GND ──────────────────────────────────────────────── LAN pin 6

Teensy pin 13 ──[1kΩ]──┬── MOSFET Gate
                      [10kΩ]
                        │
                       GND
12V ─────────── MOSFET Drain
                MOSFET Source ────────────────────── LAN pin 4 (dimmed 12V)
                                              ┌──── LAN pin 5 (LED return)
                                              │
                                             GND

3.3V ─────────────────────────────────────────────── LAN pin 7
GND ──────────────────────────────────────────────── LAN pin 8
```

### MISC 패널 (MCP23017 측)

```
LAN pin 1 ──[100Ω]── SDA ── MCP23017 SDA
LAN pin 3 ──[100Ω]── SCL ── MCP23017 SCL
LAN pin 2 ── GND
LAN pin 6 ── GND

LAN pin 4 ── LED+ (12V dimmed)
LAN pin 5 ── LED- (LED return)

LAN pin 7 ── 3.3V ──┬──┬── MCP23017 VDD
                     │  │
                   10uF 100nF
                     │  │
LAN pin 8 ── GND ───┴──┴── MCP23017 GND
```

## 보호 부품

| 위치 | 부품 | 값 | 용도 |
|---|---|----|---|
| AUX | 풀업 저항 | 4.7kΩ x2 | I2C 풀업 (SDA, SCL -> 3.3V) |
| AUX | Gate 직렬 저항 | 1kΩ | MOSFET 스위칭 링잉 방지 |
| AUX | Gate 풀다운 저항 | 10kΩ | 핫플러그 시 MOSFET OFF 유지 |
| AUX | MOSFET | IRLML6344 (SOT-23) | N-ch logic-level, Vgs(th) ~1V |
| MISC | 직렬 저항 | 100Ω x2 | SDA/SCL 돌입전류 제한 (래치업 방지) |
| MISC | 전해캡 | 10uF (10V+) | MCP VDD 핫플러그 스파이크 흡수 |
| MISC | 세라믹캡 | 100nF | MCP VDD 고주파 노이즈 필터 (핀 근접 배치) |

## 불필요한 부품

| 부품 | 사유 |
|---|---|
| TVS 다이오드 | 3.3V/12V USB 전원 수준, 과전압 파괴 위험 없음 |
| 페라이트 비드 | 저전류 (~1mA), 노이즈 문제 없음 |
| 100uF+ 대용량 캡 | 과잉, 돌입전류만 증가 |
| 외부 풀업 (MISC측) | AUX측 4.7kΩ로 충분 (1m 이내) |

## 설계 근거

- **I2C 풀업 4.7kΩ**: 1m 이내 Cat5e에서 Teensy 내부 풀업(~22kΩ)으로도 동작하나, 외부 4.7kΩ이 더 안정적
- **100Ω 직렬**: 핫플러그 시 핀 접촉 순서 불규칙 → 과도 전류 제한. I2C 100~400kHz에 영향 미미
- **10kΩ 풀다운**: LAN 미연결/핫플러그 시 Gate 플로팅 → MOSFET 의도치 않게 ON 방지
- **Pair 3 (12V + LED return)**: 꼬임쌍 내 전류 왕복 → 자기장 상쇄, 다른 쌍과 간섭 최소
- **MISC 백라이트 전류**: 3 strips x 13.6mA = 41mA @12V → Cat5e 1선(0.5A 한계)의 8%

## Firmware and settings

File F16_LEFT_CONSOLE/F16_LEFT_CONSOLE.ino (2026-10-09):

// ================================================================
//  REDKITE F16 LEFT CONSOLE — USB Joystick
// ================================================================
//
//  Board  : Teensy 4.1
//  Panels : ECM / ELEC / EPU / AVTR / UHF(엔코더 6) / ENGINE START / MPO / AUDIO 1-2
//  I2C    : Wire2 (SDA2=25, SCL2=24)
//  Buttons: 58,  축 10,  엔코더 6
//  사용 핀: 40 / 42 (헤더),  여유 2
//  백라이트: pin 13 — 온보드 LED가 상태 표시등이 됨
//
//  DX 버튼 배정 순서: switches[](39) → analogBtnArrays[](8) → encoders[](12) = 59
//  축 10개: AUDIO 1 x6 + AUDIO 2 x3 + UHF VOL x1
//
//  USB Type: Serial + Keyboard + Mouse + Joystick
//  PID:      0x048E, JOYSTICK_SIZE 64 (usb_desc.h)
//
//  Hardware is data-driven. To add/remove hardware, edit the
//  HARDWARE CONFIGURATION section only. Joystick button numbers
//  are auto-assigned at runtime.
//
//  확장 하드웨어:
//    MCP23017 x3 @ 100kHz
//      0x20  UHF switches + AUDIO1 COMM 모드 + AUDIO2 HOT MIC/CIPHER  [UHF 패널 실장]
//      0x21  ELEC switches (GPB0~2) + EPU switches (GPB6~7) + ELEC LED 8 (GPA) + EPU LED 3 (GPB3~5)
//      0x22  ECM switches + AVTR
//    74HC595 x4 — ECM 32 LEDs (direct, high-speed shift)
//    Resistor ladder — ECM 8 buttons (direct, analog)
// ================================================================


// ================================================================
//  Build Checks
// ================================================================

// 58버튼이라 12(32버튼)로는 부족합니다. 64로 통일하면 LEFT_AUX_MISC 와
// usb_desc.h 를 공유할 수 있습니다.
#if JOYSTICK_SIZE != 64
  #error "JOYSTICK_SIZE must be 64. Edit USB_SERIAL_HID section in %LOCALAPPDATA%/Arduino15/packages/teensy/hardware/avr/<version>/cores/teensy4/usb_desc.h"
#endif

#if PRODUCT_ID != 0x048E
  #error "PRODUCT_ID must be 0x048E for Left Console. Edit USB_SERIAL_HID section in usb_desc.h"
#endif

// ================================================================
//  General Settings
// ================================================================

#define BAUDRATE          1000000
#define ALLOW_DEBUG       false
#define SERIAL_TIMEOUT    3         // seconds before protocol reset

// BACKLIGHT_PIN 은 아래 핀 배정 블록에서 정의합니다 (13).
// MOSFET gate: PWM dimming (0=off, 255=full brightness)
#define IDLE_TIMEOUT_MS   (1000UL * 60 * 30)   // offline idle -> backlight auto-off (30min)

#define LOOP_DELAY_MS     10        // 100Hz — encoder pulse throughput
#define MCP_WIRE          Wire2     // SCL2 = pin 24, SDA2 = pin 25

// 100kHz (Standard Mode).
// I2C 는 데이지 체인입니다 — Teensy -I1-> 0x20(UHF) -I2-> 0x21(ELEC) -I3-> 0x22(ECM).
// MCP23017 모듈의 2열 7핀 헤더로 받아서 넘깁니다. 단일 버스이므로
// 풀업과 용량을 체인 전체 기준으로 계산해야 합니다.
//
//   풀업 : 모듈 온보드 4.7kΩ("472") x3 병렬 = 약 1.57kΩ
//   용량 : Cat5e 약 50pF/m x 체인 총 길이 + 소자/패턴
//          예) 2m + 2m + 0.3m = 4.3m => 약 215pF + 50pF = 265pF
//   tr   : 0.847 x 1570 x 265p = 약 352ns
//
// 352ns 는 400kHz 규격(300ns)을 넘고 100kHz 규격(1000ns)에는 여유가 큽니다.
// 버스 점유율도 T41 기준 11% 수준이라 속도를 올릴 이유가 없고,
// LEFT_AUX_MISC 보드도 같은 이유로 100kHz를 씁니다.
// 400kHz로 올리려면 스터브를 짧게 하고 모듈 풀업 일부를 제거한 뒤 실측해야 합니다.
//
// 주의: 모듈을 4장 이상 병렬로 달면 풀업 합성이 1.2kΩ 아래로 내려가
// 싱크 전류가 I2C 규격(3mA)에 근접하므로 일부 모듈의 풀업을 제거해야 합니다.
#define MCP_I2C_CLOCK     100000


// ================================================================
//  단계별 핀 배정
// ================================================================
//
//  T41 핀 배치 — 엣지 A = 0~12 + 24~32,  엣지 B = 13~23 + 33~41
//    A  0~11   엔코더 6 (C2, C3)
//    A  26~32  ENGINE 스위치 + JFS RUN LED (C1) — MPO 만 엣지 B 의 40
//    B  14~23  POT 10 (C2 UHF VOL, C4 AUDIO 1 x6, C5 AUDIO 2 x3)
//    B  33~34  UHF T-TONE / SQUELCH (C13, Teensy→UHF 신설)
//    B  35~38  74HC595 3선 + ECM 래더 (C6)
//    B  40     MPO (C1)
//    B  13     백라이트 MOSFET
//    B  41     UHF STATUS (C13)
//    하단 SD  43/44/45 = MOSI2/CS2/SCK2 -> UHF 7세그 디스플레이 (C14)
//             SD 확장 케이블로 빼냅니다. 엣지 핀은 쓰지 않습니다.
//    여유: 12, 39(A15)
//  ※ docs/LEFT_CONSOLE_PIN_TREE2.md 의 핀 배열도는 바닥면(납땜면) 기준이라
//    엣지 A 가 그림의 오른쪽 열, 엣지 B 가 왼쪽 열로 나옵니다.

// 출력이면 온보드 LED 공유가 무해하고, LED가 상태 표시등이 됩니다.
#define BACKLIGHT_PIN     13

// C6: 74HC595 3선 + ECM 래더 (핀 35~38, 엣지 B 하단 블록)
#define PIN_SR_LATCH      37      // ST_CP
#define PIN_SR_CLOCK      36      // SH_CP
#define PIN_SR_DATA       35      // DS
#define PIN_LADDER        A14     // pin 38  ⚠ 필터 캡은 A14 에

// C1: ENGINE START (핀 26~32, 엣지 A 하단 블록) + MPO(40)
// 엣지 A 하단 블록이 7핀뿐이라 MPO 만 엣지 B 의 40 에 남습니다.
#define PIN_MPO           40      // A16
#define PIN_LED_JFS_RUN   26      // A12  ENGINE START RUN 램프
#define PIN_JFS1          27      // A13
#define PIN_JFS2          28
#define PIN_ENG_CONT      29
#define PIN_ABRESET       30
#define PIN_ENGDATA       31
#define PIN_MAXPOWER      32

// C2: UHF VOL (핀 23)
#define PIN_POT_UHFVOL    A9      // pin 23

// C4: AUDIO 1 POT x6 (핀 17~22)
#define PIN_POT_COMM1     A8      // pin 22
#define PIN_POT_COMM2     A7      // pin 21
#define PIN_POT_SECURE    A6      // pin 20
#define PIN_POT_MSL       A5      // pin 19
#define PIN_POT_TF        A4      // pin 18
#define PIN_POT_THREAT    A3      // pin 17

// C5: AUDIO 2 POT x3 (핀 14~16) — HOT MIC/CIPHER 는 MCP#0 PA0/PA1 로 이설
#define PIN_POT_INTCOM    A2      // pin 16
#define PIN_POT_TACAN     A1      // pin 15
#define PIN_POT_ILS       A0      // pin 14

// C13: UHF T-TONE / SQUELCH — MCP#0 에서 Teensy 직결로 이설 (핀 33~34)
#define PIN_UHF_TTONE     34
#define PIN_UHF_SQUELCH   33

// UHF STATUS (핀 41)
#define PIN_UHF_STATUS    41      // A17

// ---- C14: UHF 7세그 디스플레이 (MAX7219) ----------------------------------
// Teensy 4.1 하단 SD 카드 인터페이스의 SPI2 를 SD 확장 케이블로 빼내 씁니다.
// 엣지 핀(0~41)은 전혀 쓰지 않으므로 기존 배치가 그대로 유지됩니다.
// ⚠ SD 카드를 쓰게 되면 충돌합니다.
#define HAS_UHF_DISPLAY   1
#define PIN_DISP_DIN      43      // MOSI2 -> J1.3 DIN
#define PIN_DISP_CS       44      // CS2   -> J1.5 CS (소프트웨어 토글)
#define PIN_DISP_CLK      45      // SCK2  -> J1.4 CLK

// Encoder -> DX pulse timing (in main-loop ticks)
#define ENC_PULSE_TICKS   4         // pulse held ~40ms @100Hz
#define ENC_PENDING_MAX   30        // queue cap, prevents runaway lag


// ================================================================
//  Type Definitions
// ================================================================

enum SwitchType {
  SW_ON_OFF,      // 1 pin  -> 1 button
  SW_ON_OFF_ON,   // 2 pins -> 2 buttons (center = both off)
  SW_ROTARY       // numPos consecutive pins -> numPos buttons (one active)
};

enum JoyAxis {
  AXIS_X = 0, AXIS_Y, AXIS_Z, AXIS_Xr, AXIS_Yr, AXIS_Zr,   // analog16(0..5)
  AXIS_S1, AXIS_S2, AXIS_S3, AXIS_S4, AXIS_S5, AXIS_S6,    // slider(1..17)
  AXIS_S7, AXIS_S8, AXIS_S9, AXIS_S10
};

enum Panel {
  PNL_ECM, PNL_ELEC, PNL_EPU, PNL_AVTR,
  PNL_UHF, PNL_ENGINE, PNL_MPO, PNL_AUDIO1, PNL_AUDIO2,
  PNL_COUNT
};

const char* const panelNames[] = {
  "ECM", "ELEC", "EPU", "AVTR", "UHF", "ENGINE", "MPO", "AUDIO1", "AUDIO2"
};

struct McpDeviceDef {
  const char* name;
  uint8_t     addr;     // I2C address (0x20-0x27)
};

struct SwitchDef {
  const char* name;
  Panel       panel;
  SwitchType  type;
  int8_t      mcpIdx;   // -1 = direct Teensy pin, >= 0 = index into mcpDevices[]
  uint8_t     pin1;
  uint8_t     pin2;     // SW_ON_OFF_ON only
  uint8_t     numPos;   // SW_ROTARY only: consecutive pins starting at pin1
};

// LEDs live on MCP23017 (mcpIdx >= 0) or direct Teensy pins (mcpIdx = -1).
struct LedDef {
  const char* name;
  Panel       panel;
  uint8_t     pin;
  int8_t      mcpIdx;
};

// NOTE: pots have no mcpIdx — MCP23017 has no ADC.
struct PotDef {
  const char* name;
  Panel       panel;
  uint8_t     pin;
  JoyAxis     axis;
};

// NOTE: encoders have no mcpIdx — I2C polling is too slow, pulses would be lost.
// 디텐트는 그대로 CW/CCW 펄스로 배출됩니다 — 자리 순환·경계 처리는 BMS 가 합니다.
struct EncoderDef {
  const char* name;
  Panel       panel;
  uint8_t     pinA;
  uint8_t     pinB;
};

// Resistor-ladder button array: multiple buttons on one analog pin.
// Nearest-value match; reject if below last value - (adjacent gap / 2).
struct AnalogBtnArrayDef {
  const char*        groupName;
  Panel              panel;
  uint8_t            pin;
  uint8_t            numButtons;
  const char* const* btnNames;
  const int*         values[2];   // [0]=BL OFF, [1]=BL ON
};


// ================================================================
//
//  >>> HARDWARE CONFIGURATION - Edit this section <<<
//
// ================================================================

// --- MCP23017 I/O Expanders (Wire2: SCL2=24, SDA2=25) ---
// MCP pin numbering: GPA0-7 = 0-7, GPB0-7 = 8-15
const McpDeviceDef mcpDevices[] = {
  // name                    addr
  {"UHF",                    0x20},   // idx 0 — UHF panel mounted, I2C chain head
  {"ELEC+EPU",               0x21},   // idx 1 — ELEC panel mounted
  {"ECM+AVTR",               0x22},   // idx 2 — ECM panel mounted
};

// --- Digital Switches ---
//
// 순서 주의: ECM -> ELEC -> AVTR 를 먼저 두어 버튼 1~11 이 두 단계에서
// 동일하게 유지되도록 했습니다. T41 전용 패널은 그 뒤에 붙습니다.
const SwitchDef switches[] = {
  // name                 panel        type           mcpIdx pin1 pin2 numPos

  // ---- ECM Panel (MCP 0x22, GPB) ----                     btn 1~6
  {"ECM OPR/STBY",        PNL_ECM,     SW_ON_OFF_ON,     2,  11,  10,  0},  // GPB3/GPB2  (OPR/OFF)
  {"ECM XMIT",            PNL_ECM,     SW_ON_OFF_ON,     2,  13,  12,  0},  // GPB5/GPB4  (XMIT1/XMIT3)
  {"ECM BIT",             PNL_ECM,     SW_ON_OFF,        2,  14,   0,  0},  // GPB6  momentary
  {"ECM RESET",           PNL_ECM,     SW_ON_OFF,        2,  15,   0,  0},  // GPB7  momentary

  // ---- EPU Panel (MCP 0x21) ----                           btn 7~8
  {"EPU",                 PNL_EPU,     SW_ON_OFF_ON,     1,   8,   9,  0},  // GPB0/GPB1  OFF/NORM/ON (배선 교차)

  // ---- ELEC Panel (MCP 0x21) ----                          btn 9
  {"ELEC CAUTION RST",    PNL_ELEC,    SW_ON_OFF,        1,  10,   0,  0},  // GPB2  momentary (CAUTION RST)

  // ---- AVTR Panel (MCP 0x22) ----                        btn 10~11
  {"AVTR",                PNL_AVTR,    SW_ON_OFF_ON,     2,   8,   9,  0},  // GPB0/GPB1  UNTHRD/RECORD/EVENT MRK

  // ---- ENGINE START Panel (Teensy direct) ----           btn 12~14
  {"JFS",       PNL_ENGINE, SW_ON_OFF_ON, -1, PIN_JFS1, PIN_JFS2, 0},  // OFF/START1/START2
  {"ENG CONT",  PNL_ENGINE, SW_ON_OFF,    -1, PIN_ENG_CONT,   0,  0},  // PRI/SEC

  // ---- MPO (Teensy direct) ----                          btn 15
  {"MPO",       PNL_MPO,    SW_ON_OFF,    -1, PIN_MPO,        0,  0},  // NORM/OVRD

  // ---- ELEC MAIN PWR (MCP 0x21) ----                     btn 16~17
  {"ELEC MAIN PWR",       PNL_ELEC,    SW_ON_OFF_ON,     1,  14,  15,  0},  // GPB6/GPB7  MAIN/OFF (배선 교차)

  // ---- UHF Panel (MCP 0x20, 패널 실장) ----               btn 18~27
  // SW_ROTARY 는 pin1 부터 numPos 개 연속 GPIO 를 읽습니다.
  // 실제 배선: FUNCTION(PB4~7) → MODE(PB1~3) → STATUS(PB0)
  // SW_ROTARY 는 오름차순 고정이라 DX 를 뒤집으려면 개별 SW_ON_OFF 로 분리
  {"UHF FUNC ADF",   PNL_UHF, SW_ON_OFF, 0, 15, 0, 0},  // PB7
  {"UHF FUNC BOTH",  PNL_UHF, SW_ON_OFF, 0, 14, 0, 0},  // PB6
  {"UHF FUNC MAIN",  PNL_UHF, SW_ON_OFF, 0, 13, 0, 0},  // PB5
  {"UHF FUNC OFF",   PNL_UHF, SW_ON_OFF, 0, 12, 0, 0},  // PB4
  {"UHF MODE GRD",   PNL_UHF, SW_ON_OFF, 0, 11, 0, 0},  // PB3
  {"UHF MODE PRE",   PNL_UHF, SW_ON_OFF, 0, 10, 0, 0},  // PB2
  {"UHF MODE MNL",   PNL_UHF, SW_ON_OFF, 0,  9, 0, 0},  // PB1
  {"UHF SQUELCH",  PNL_UHF, SW_ON_OFF, -1, PIN_UHF_SQUELCH, 0, 0},  // Teensy 33
  {"UHF T-TONE",   PNL_UHF, SW_ON_OFF, -1, PIN_UHF_TTONE,   0, 0},  // Teensy 34  momentary
  {"UHF STATUS",  PNL_UHF, SW_ON_OFF, -1, PIN_UHF_STATUS,  0, 0},  // Teensy 41  momentary

  // ---- AUDIO 1 모드 로터리 (MCP 0x20, 케이블 C8 로 UHF 패널까지 점퍼) ----  btn 28~33
  // 실제 배선: COMM1 PA4=OFF PA3=SQL PA2=GD, COMM2 PA7=OFF PA6=SQL PA5=GD
  // SW_ROTARY 는 오름차순 고정이라 DX 를 뒤집으려면 개별 SW_ON_OFF 로 분리
  {"COMM1 OFF",   PNL_AUDIO1, SW_ON_OFF, 0, 4, 0, 0},  // PA4
  {"COMM1 SQL",   PNL_AUDIO1, SW_ON_OFF, 0, 3, 0, 0},  // PA3
  {"COMM1 GD",    PNL_AUDIO1, SW_ON_OFF, 0, 2, 0, 0},  // PA2
  {"COMM2 OFF",   PNL_AUDIO1, SW_ON_OFF, 0, 7, 0, 0},  // PA7
  {"COMM2 SQL",   PNL_AUDIO1, SW_ON_OFF, 0, 6, 0, 0},  // PA6
  {"COMM2 GD",    PNL_AUDIO1, SW_ON_OFF, 0, 5, 0, 0},  // PA5

  // ---- ENGINE START 추가 스위치 (Teensy direct) ----      btn 34~36
  {"AB RESET",  PNL_ENGINE, SW_ON_OFF,    -1, PIN_ABRESET,    0,  0},
  {"ENG DATA",  PNL_ENGINE, SW_ON_OFF,    -1, PIN_ENGDATA,    0,  0},
  {"MAX POWER", PNL_ENGINE, SW_ON_OFF,    -1, PIN_MAXPOWER,   0,  0},

  // ---- AUDIO 2 스위치 (Teensy direct) ----                btn 37~38
  {"HOT MIC",   PNL_AUDIO2, SW_ON_OFF,     0,   0,            0,  0},  // MCP#0 PA0
  {"CIPHER",    PNL_AUDIO2, SW_ON_OFF,     0,   1,            0,  0},  // MCP#0 PA1
};

// --- Rotary Encoders (Teensy direct, interrupt-polled) ---
// Each encoder emits 2 buttons: CW then CCW.
//
// Pin pairs must stay on the SAME board edge — an encoder's A/B are two wires
// from one knob. The two Teensy 4.1 edges are 0-12 + 24-32 and 13-23 + 33-41.
// The six encoders fill 0-11 in the panel's knob order (PRESET, then the
// frequency digits). C2 lands contiguous on 4-9; C3 is split 0-3 + 10-11.
// The encoder cables' only line on the other edge is VOL (pin 23).
const EncoderDef encoders[] = {
  // name              panel     pinA pinB
  {"UHF PRESET",       PNL_UHF,    1,   0},   // C3  pinA/B swapped
  {"UHF 100MHz",       PNL_UHF,    2,   3},   // C3
  {"UHF 10MHz",        PNL_UHF,    4,   5},   // C2
  {"UHF 1MHz",         PNL_UHF,    6,   7},   // C2
  {"UHF 0.1MHz",       PNL_UHF,    8,   9},   // C2
  {"UHF 0.025MHz",     PNL_UHF,   10,  11},   // C3
};
#define NUM_ENCODERS  (sizeof(encoders) / sizeof(encoders[0]))

// --- Analog Pots ---
const PotDef pots[] = {
  // BMS 바인딩 가능 7개 → DirectInput 인식 축 우선 배치 (6 named + slider 1~2)
  // name                 panel        pin              axis
  {"AUDIO COMM CH1",      PNL_AUDIO1,  PIN_POT_COMM1,   AXIS_X},
  {"AUDIO COMM CH2",      PNL_AUDIO1,  PIN_POT_COMM2,   AXIS_Y},
  {"AUDIO MSL VOL",       PNL_AUDIO1,  PIN_POT_MSL,     AXIS_Z},
  {"AUDIO THREAT VOL",    PNL_AUDIO1,  PIN_POT_THREAT,  AXIS_Xr},
  {"AUDIO INTERCOM",      PNL_AUDIO2,  PIN_POT_INTCOM,  AXIS_Yr},
  {"UHF VOL",             PNL_UHF,     PIN_POT_UHFVOL,  AXIS_Zr},
  {"AUDIO ILS VOL",       PNL_AUDIO2,  PIN_POT_ILS,     AXIS_S1},
  // BMS 바인딩 불가 3개 → slider 2 까지만 DirectInput 인식
  {"AUDIO SECURE VOL",    PNL_AUDIO1,  PIN_POT_SECURE,  AXIS_S2},
  {"AUDIO TF VOL",        PNL_AUDIO1,  PIN_POT_TF,      AXIS_S3},    // DirectInput 미인식
  {"AUDIO TACAN VOL",     PNL_AUDIO2,  PIN_POT_TACAN,   AXIS_S4},    // DirectInput 미인식
};
#define NUM_POTS      (sizeof(pots) / sizeof(pots[0]))

// --- ECM Resistor Ladder (8 buttons on A9) ---
// PCB is fixed: 10k series chain + 20k pulldown.
// ADC_k = 1023 * 20000 / (k * 10000 + 20000)   (k = 0..7)
// Matching is nearest-value, so the tight 253/225 pair (gap 28) is safe:
// the decision boundary sits at 239, giving +/-14 noise margin.
// 8x oversampling keeps ADC noise around +/-2 counts.
const char* const ecmBtnNames[] = {
  "ECM 1", "ECM 2", "ECM 3", "ECM 4",
  "ECM 5", "ECM 6", "ECM FRM", "ECM SPL"
};
const int ecmBtnValues[] = {1023, 679, 509, 406, 338, 289, 253, 225};  // measured, idle~0

const AnalogBtnArrayDef analogBtnArrays[] = {
  // groupName      panel     pin  numBtn  btnNames      values{BL_OFF, BL_ON}
  {"ECM Buttons",   PNL_ECM,  PIN_LADDER, 8,      ecmBtnNames,  {ecmBtnValues, ecmBtnValues}},
};

// --- ELEC Panel LEDs (MCP 0x21, GPA port) ---
// All 8 on GPA so the whole port updates in one I2C write.
// NOTE: LEDs are sourced (cathode common to GND), so the binding limit is
//       VDD inflow 125mA — not the VSS 150mA figure. 0x21 carries 11 LEDs
//       (ELEC 8 + EPU 3), so keep each at or below 10mA (11 x 10 = 110mA).
enum LedIdx {
  // ELEC 패널 경고등 8 (MCP 0x21 GPA0~7) — ledBits bit 0~7
  LI_FLCS_PMG, LI_MAIN_GEN, LI_STBY_GEN,
  LI_EPU_GEN, LI_EPU_PMG, LI_BATT_TO_FLCS,
  LI_FLCS_RLY, LI_BATT_FAIL,
  // EPU 패널 3 (MCP 0x21 GPB3~5) — ledBits bit 8~10
  LI_EPU_HYDRAZN, LI_EPU_AIR, LI_EPU_RUN,
  // ENGINE START 패널 1 (Teensy 직결) — ledBits bit 11
  LI_JFS_RUN,
};

const LedDef leds[] = {
  // name               panel      pin  mcpIdx
  {"FLCS PMG",          PNL_ELEC,   0,   1},   // GPA0
  {"MAIN GEN",          PNL_ELEC,   1,   1},   // GPA1
  {"STBY GEN",          PNL_ELEC,   2,   1},   // GPA2
  {"EPU GEN",           PNL_ELEC,   3,   1},   // GPA3
  {"EPU PMG",           PNL_ELEC,   4,   1},   // GPA4
  {"BATT TO FLCS",      PNL_ELEC,   5,   1},   // GPA5
  {"FLCS RLY",          PNL_ELEC,   6,   1},   // GPA6
  {"BATT FAIL",         PNL_ELEC,   7,   1},   // GPA7
  // ---- EPU 패널 (MCP 0x21 GPB3~5) ----
  {"EPU HYDRAZN",       PNL_EPU,   11,   1},   // GPB3
  {"EPU AIR",           PNL_EPU,   12,   1},   // GPB4
  {"EPU RUN",           PNL_EPU,    7,   2},   // MCP 0x22 GPA7 (0x21 GPB5 핀 불량으로 이설)
  // ---- ENGINE START 패널 (Teensy 직결, 케이블 1에 탑음) ----
  {"JFS RUN",           PNL_ENGINE, PIN_LED_JFS_RUN, -1},
};

// --- ECM Panel LEDs (74HC595 x4, daisy-chained, 32 outputs) ---
#define SR_DATA_PIN    PIN_SR_DATA    // DS
#define SR_CLOCK_PIN   PIN_SR_CLOCK   // SH_CP
#define SR_LATCH_PIN   PIN_SR_LATCH   // ST_CP
#define SR_NUM_CHIPS   4
#define SR_NUM_OUTPUTS (SR_NUM_CHIPS * 8)  // 32

static uint8_t srData[SR_NUM_CHIPS];

const char* const ecmSrLedNames[] = {
  "ECM_1_S", "ECM_1_A", "ECM_1_F", "ECM_1_T",
  "ECM_2_S", "ECM_2_A", "ECM_2_F", "ECM_2_T",
  "ECM_3_S", "ECM_3_A", "ECM_3_F", "ECM_3_T",
  "ECM_4_S", "ECM_4_A", "ECM_4_F", "ECM_4_T",
  "ECM_5_S", "ECM_5_A", "ECM_5_F", "ECM_5_T",
  "ECM_6_S", "ECM_6_A", "ECM_6_F", "ECM_6_T",
  "ECM_FRM_S", "ECM_FRM_A", "ECM_FRM_F", "ECM_FRM_T",
  "ECM_SPL_S", "ECM_SPL_A", "ECM_SPL_F", "ECM_SPL_T",
};

// Logical index -> physical SR output (PCB wiring is not in shift order)
const uint8_t srMap[SR_NUM_OUTPUTS] = {
  17, 16, 19, 18,  // ECM 1: S, A, F, T
  23, 22, 21, 20,  // ECM 2
  25, 24, 27, 26,  // ECM 3
  31, 30, 29, 28,  // ECM 4
  13, 12, 15, 14,  // ECM 5
  11, 10,  9,  8,  // ECM 6
   5,  4,  7,  6,  // ECM FRM
   3,  2,  1,  0,  // ECM SPL
};


// ================================================================
//  End of Hardware Configuration
// ================================================================

// NUM_ENCODERS / NUM_POTS 는 위 HARDWARE CONFIGURATION 에서 단계별로 정의됩니다.
#define NUM_MCP_DEVICES   (sizeof(mcpDevices)      / sizeof(mcpDevices[0]))
#define NUM_SWITCHES      (sizeof(switches)        / sizeof(switches[0]))
#define NUM_LEDS          (sizeof(leds)            / sizeof(leds[0]))
#define NUM_ANALOG_ARRAYS (sizeof(analogBtnArrays) / sizeof(analogBtnArrays[0]))


// ================================================================
//  Includes
// ================================================================

#include <Wire.h>
#include <usb_dev.h>

extern volatile uint8_t usb_configuration;


// ================================================================
//  Backlight (PWM dimming)
// ================================================================

static bool backlightState = true;
static uint8_t manualBrightness = 255;  // offline 수동 밝기 (기본 최대)
static bool backlightIdleOff = false;

void setBacklight(bool on) {
  analogWrite(BACKLIGHT_PIN, on ? 255 : 0);
  backlightState = on;
}

void setBacklightBrightness(uint8_t brightness) {
  analogWrite(BACKLIGHT_PIN, brightness);
  backlightState = (brightness > 0);
}
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
void loop() {
  static bool ledsOff = false;

  if (isUSBSuspended()) {
    turnOffAllLeds();
#if HAS_UHF_DISPLAY
    displayOn(false);
#endif
    if (!backlightIdleOff) {
      setBacklight(false);
      backlightIdleOff = true;
    }
    ledsOff = true;
    asm("wfi");
    return;
  }

  // --- MCP hotplug: reconnect check every 500ms ---
  {
    static uint32_t lastMcpCheck = 0;
    if (millis() - lastMcpCheck > 500) {
      lastMcpCheck = millis();
      for (unsigned int d = 0; d < NUM_MCP_DEVICES; d++) {
        if (!mcpConnected[d]) {
          mcpInit(d, false);
          if (mcpConnected[d])
            Serial.printf("  [MCP@0x%02X] %s - RECONNECTED\n",
                          mcpDevices[d].addr, mcpDevices[d].name);
        }
      }
    }
  }

  // --- Inputs ---
  uint8_t prevSnapshot[128];
  if (ledsOff) memcpy(prevSnapshot, prevBtnState, sizeof(prevSnapshot));

  for (unsigned int d = 0; d < NUM_MCP_DEVICES; d++) mcpReadPorts(d);
  processSwitches();
  processCovers();    // 커버 자동화: 스위치보다 커버가 먼저 열리고, 나중에 닫힘
  processAnalogButtons();
  processPots();
  processEncoders();
  Joystick.send_now();

  // Wake on input while LEDs are off
  if (ledsOff && memcmp(prevSnapshot, prevBtnState, sizeof(prevSnapshot)) != 0) {
    ledsOff = false;
    backlightIdleOff = false;
    welcomeCeremony();
  }

  // --- Serial / LED sync ---
  static int  heartbeat  = 0;
  static bool wasOffline = false;
  const int timeoutTicks = (1000 / LOOP_DELAY_MS) * SERIAL_TIMEOUT;

  if (currentProto == PROTO_DCSBIOS) dcsBiosCheckTimeout();

  if (detectAndRouteSerial()) heartbeat = 0;

  if (heartbeat >= timeoutTicks) {
    if (currentProto != PROTO_UNKNOWN) resetProtocol();
    wasOffline = true;

    // Offline 수동 밝기 조절 (UHF STATUS + UHF VOL)
    checkManualBacklight();

    // Backlight idle auto-off (offline only)
    if (!backlightIdleOff && (millis() - lastInputTime > IDLE_TIMEOUT_MS)) {
      setBacklight(false);
      backlightIdleOff = true;
      ledsOff = true;
    }
  }

  // Bridge online: offline -> online transition
  if (heartbeat < timeoutTicks && wasOffline) {
    wasOffline = false;
    ledsOff = false;
    backlightIdleOff = false;
    welcomeCeremony();
  }

  ++heartbeat;
  if (heartbeat > timeoutTicks) heartbeat = timeoutTicks;

  // --- Flush outputs ---
  mcpFlushOutputs();
  srFlush();

  delay(LOOP_DELAY_MS);
}

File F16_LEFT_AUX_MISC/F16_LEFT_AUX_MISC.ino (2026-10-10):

/* REDKITE_F16_PANELS
   Teensy 4.1 USB Joystick for Falcon BMS F-16 Left Console Panel

   USB Type: Keyboard + Mouse + Joystick (Tools > USB Type)

   Hardware configuration is data-driven.
   To add/remove/change hardware, edit the HARDWARE CONFIGURATION section only.
   Joystick button numbers are auto-assigned at runtime.
   To disable a panel, comment out its entries in the config arrays.
*/


// ================================================================
//  Build Checks
// ================================================================

#if JOYSTICK_SIZE < 64
  #error "JOYSTICK_SIZE must be 64. Edit USB_SERIAL_HID section in %LOCALAPPDATA%/Arduino15/packages/teensy/hardware/avr/<version>/cores/teensy4/usb_desc.h"
#endif

#if PRODUCT_ID != 0x0487
  #error "PRODUCT_ID must be 0x0487 for Left Aux Misc. Edit USB_SERIAL_HID section in %LOCALAPPDATA%/Arduino15/packages/teensy/hardware/avr/<version>/cores/teensy4/usb_desc.h"
#endif

// ================================================================
//  General Settings
// ================================================================

#define BAUDRATE      1000000
#define ALLOW_DEBUG   false
#define MAX_PIN       55        // Teensy 4.1 max digital pin
#define LOOP_DELAY_MS 50
#define SERIAL_TIMEOUT 6        // Serial heartbeat timeout in seconds
#define BACKLIGHT_PIN  13       // Backlight PWM (MOSFET: 0=off, 255=full)
#define IDLE_TIMEOUT_MS (1000 * 60 * 30)  // offline idle timeout for backlight auto-off (30min)


// ================================================================
//  Type Definitions
// ================================================================

enum SwitchType { SW_ON_OFF, SW_ON_OFF_ON, SW_ON_OFF_NC };

enum JoyAxis {
  AXIS_X, AXIS_Y, AXIS_Z,
  AXIS_Zr,                      // Zrotate
  AXIS_SL, AXIS_SR,             // sliderLeft/Right  (JOYSTICK_SIZE 12)
  AXIS_Xr, AXIS_Yr              // Xrotate/Yrotate   (JOYSTICK_SIZE 64)
};

enum Panel {
  PNL_NONE,       // standalone (not part of a panel)
  PNL_MISC,       // MISC Armament panel (center console, left of left MFD)
  PNL_GEAR,       // Landing Gear panel (left aux console)
  PNL_ALT_GEAR,   // Alt Gear panel (left aux console)
  PNL_CMDS,       // Countermeasures Dispenser (left aux console)
  PNL_TWA,        // Threat Warning Aux (left aux console)
  PNL_HMCS,       // HMCS (Helmet Mounted Cueing System)
  PNL_COUNT
};

const char* const panelNames[] = {
  "Standalone", "MISC", "Gear", "AltGear", "CMDS", "TWA", "HMCS"
};

struct SwitchDef {
  const char* name;
  Panel       panel;
  SwitchType  type;
  int8_t      mcpIdx;     // -1 = direct Teensy pin, >= 0 = index into mcpDevices[]
  uint8_t     pin1;
  uint8_t     pin2;       // only used for SW_ON_OFF_ON
  int*        stateRef;   // if non-NULL, switch state is written here
};

// NOTE: PotDef and AnalogBtnArrayDef have no mcpIdx — MCP23017 does not support analog input.
struct PotDef {
  const char* name;
  Panel       panel;
  uint8_t     pin;
  JoyAxis     axis;
};

struct LedDef {
  const char* name;
  Panel       panel;
  uint8_t     pin;
  int8_t      mcpIdx;   // -1 = direct Teensy pin, >= 0 = index into mcpDevices[]
};

// --- MCP23017 I/O Expander ---

struct McpDeviceDef {
  const char* name;
  uint8_t     addr;     // I2C address (0x20–0x27)
};


// Resistor-ladder analog button array: multiple buttons on a single analog pin.
// Each button adds a 220Ω resistor, producing a unique analogRead value.
// values[0]=BL OFF, values[1]=BL ON (descending order).
// Matching: nearest-value, reject if below last value - (adjacent gap / 2).
struct AnalogBtnArrayDef {
  const char*        groupName;    // group name for logging
  Panel              panel;
  uint8_t            pin;          // analog input pin
  uint8_t            numButtons;
  const char* const* btnNames;     // array of button names, length = numButtons
  const int*         values[2];    // [0]=BL OFF, [1]=BL ON
};

// ================================================================
//
//  >>> HARDWARE CONFIGURATION - Edit this section <<<
//
// ================================================================

// --- Switch state references ---
// Declare variables here for switches that need to be read by other logic.
// Then set stateRef in switches[] to link them.
int swLandingLight = 0;   // used by pedal brake mode
int swGear = 0;           // used by offline LED simulation

const SwitchDef switches[] = {
  // name                   panel           type         mcpIdx pin1 pin2  stateRef
  //                                                     (-1 = Teensy direct, >= 0 = MCP device index)

  // ---- MISC Panel (MCP23017 device 0, addr 0x20) ----
  // MCP pin mapping: GPA0–7 = 0–7, GPB0–7 = 8–15
  {"RF",                    PNL_MISC,       SW_ON_OFF_ON,    0,   4,   5,  NULL},   // GPA4, GPA5
  {"Laser ARM",             PNL_MISC,       SW_ON_OFF,       0,   3,   0,  NULL},   // GPA3
  {"ALT REL",               PNL_MISC,       SW_ON_OFF_NC,    0,   2,   0,  NULL},   // GPA2 (normally closed)
  {"Master ARM",            PNL_MISC,       SW_ON_OFF_ON,    0,   0,   1,  NULL},   // GPA0, GPA1
  {"ADV MODE",              PNL_MISC,       SW_ON_OFF,       0,   10,  0,  NULL},   // GPB2
  {"Roll AP",               PNL_MISC,       SW_ON_OFF_ON,    0,   11,  12,  NULL},  // GPB3, GPB4
  {"Pitch AP",              PNL_MISC,       SW_ON_OFF_ON,    0,   13,  14,  NULL},  // GPB5, GPB6

  // ---- Gear Panel (left aux console) ----
  {"EMER Jettison",         PNL_GEAR,       SW_ON_OFF,      -1,   10,   0,  NULL},
  {"Store CAT",             PNL_GEAR,       SW_ON_OFF,      -1,   5,   0,  NULL},   // CAT I / CAT III
  {"Horn Silencer",         PNL_GEAR,       SW_ON_OFF,      -1,   2,   0,  NULL},
  {"Landing Light",         PNL_GEAR,       SW_ON_OFF_ON,   -1,   3,   4,  &swLandingLight},
  {"Hook",                  PNL_GEAR,       SW_ON_OFF,      -1,   11,   0,  NULL},   // Up / Down
  {"Landing Gear",          PNL_GEAR,       SW_ON_OFF_ON,   -1,   28,   29,  &swGear},  // UP / DN
  {"DN LOCK REL",           PNL_GEAR,       SW_ON_OFF,      -1,   1,   0,  NULL},   // SW_IDX_DN_LOCK_REL
  {"GND JETT ENABLE",       PNL_GEAR,       SW_ON_OFF,      -1,   9,   0,  NULL},   // ENABLE / OFF
  {"ANTI SKID",             PNL_GEAR,       SW_ON_OFF_ON,   -1,   6,  7,  NULL},   // PARKING BRAKE / ANTI SKID / OFF
  {"BRAKES Channel",        PNL_GEAR,       SW_ON_OFF,      -1,   8,   0,  NULL},   // CHAN 1 / CHAN 2
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

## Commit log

2026-03-13 Initial commit: Teensy 4.1 F-16 cockpit panel controller
    Dual sim support (Falcon BMS F4TS / DCS World DCS-BIOS) with auto protocol detection.
    Data-driven hardware configuration for switches, rotary encoders, analog ladders, pedals, and LEDs.
2026-03-14 Add TWA LED support, DCS-BIOS chunk parser fix, and UDP bridge tool
    - Add 4 TWA LEDs (Power/Low/Search/Act) with DCS-BIOS RWR integration
    - Fix DCS-BIOS parser to handle multi-word chunks (gear + TWA in one chunk)
    - Fix compilation: MemoryFree ARM support, ArduinoJson v7 migration
    - Fix warnings: macro semicolon, NULL-to-int, sign compare, sequence point
    - Add gear LED sequential blink in offline mode
    - Add protocol detection indicator (TWA1 blink on connect)
    - Add Python UDP-to-Serial bridge for DCS-BIOS connectivity
    [DcsBiosParser.h, REDKITE_F16_PANELS.ino, dcsbios_bridge.py]
2026-03-16 Add MCP23017 ECM/ELEC panel, MCP LightBit routing, and ECM analog buttons
    - Add second MCP23017 device (0x21) for ECM/ELEC panel switches
    - Enable ECM switches (XMIT, RESET, OPR, BIT) and ELEC switches (MAIN PWR, CAUTION RESET) on MCP device 1
    - Enable ECM analog button array (8 buttons on A13)
    - Add MCP_SUPPORT conditional compilation for F4TS LightBit MCP/direct routing
    - Add per-pin routing table (findMcpLedIdx, parse_setup/set_LightBit_MCP_and_direct)
    - Add LED priority comment (MCP takes precedence over direct for duplicate pins)
    [REDKITE_F16_PANELS.ino]
2026-03-16 Remove F4TS/ECM SR/ELEC panel code, add BMS-BIOS protocol, fix BMS shared memory
    - Remove all F4TS (F4 To Serial) code and dependencies
    - Remove ECM shift register (74HC595) code from all files
    - Remove ELEC panel (switches, LEDs, MCP device 2, DCS-BIOS mappings)
    - Remove ECM MCP (device 1, 0x21) and ECM switches/analog buttons
    - Activate CMDS MODE and CMDS PRGM analog button arrays
    - Rename dcsBiosProcessByte() to processDcsBiosByte()
    - Add BMS-BIOS binary protocol with auto-detection
    - Add bms_bridge.py with corrected BMS 4.38 shared memory offsets
    (lightBits=108, lightBits2=124, lightBits3=128) and verified bitmasks
    - Simplify DcsBiosParser to only handle Gear, TWA, and ECM addresses
    C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
    [DcsBiosParser.h, REDKITE_F16_PANELS.ino]
2026-03-16 Update README: replace F4TS with BMS-BIOS, remove ECM/ELEC panels
2026-03-16 Fix bms_bridge.py creating shared memory — use OpenFileMappingW to open only existing
2026-03-17 Major refactor: add HMCS/Gear Warn, split BMS-BIOS parser, remove rotary, rename bridge
    - Add HMCS panel: 3 pots (A13-A15), Eject button (pin 0)
    - Add Gear Warning LED (pin 33) with DCS-BIOS/BMS-BIOS mapping
    - Move DcsBios/ and BmsBios/ into unified BiosHandler/ folder
    - Remove RotaryDef (unused, all converted to resistor ladders)
    - Rename bms_bridge.py to bmsbios_bridge.py
    - Rename USB device to "Redkite F16 Panels"
    - Update COM port to COM4 in all tools/docs
    - Add ALT GEAR Reset switch (pin 13)
    - Move ALT GEAR Handle/Reset to pins 12/13
    - Update docs: joystick.txt, teensy_direct_pins.txt, protocol_reference.txt
    - Update README with current pin map and project structure
    - Remove dcsbios_tes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
    [DcsBiosParser.h, REDKITE_F16_PANELS.ino, bmsbios_bridge.py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]
2026-03-17 Add cockpit photo, 3D printed parts section, and STL files to README
    [Enclosure - OnePiece2.stl, Left Enclosure.stl, Left Stand - new.stl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]
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2026-03-17 Remove enclosure STLs (derivative of purchased models), add copyright notice
    [Left Enclosure.stl, Right Enclosure - new.stl]
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2026-03-18 Left Aux Panel v1: backlight control, gear LED sim, debug logging
    First complete version of Left Aux Panels (Gear, CMDS, TWA, Alt Gear).
    MISC panel MCP23017 integration not yet tested.
    - Repurpose pin 0 from HMCS Eject to backlight on/off control
    (LOW = on, HIGH = off during USB suspend)
    - Offline gear LED simulation: 3 gear LEDs follow landing gear switch
    state with 2s delay, Gear Warn LED lights for 5s on state change
    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
    [components.xlsx]
2026-03-18 Fix Gear Warn LED: GEARHANDLE is in LightBits2, not LightBits
    BMS shared memory has GEARHANDLE (bit 30) in LightBits2 (offset 124),
    not LightBits (offset 108). Confirmed via --debug output during gear
    transition. Update bridge LED_MAP and all docs accordingly.
    [bmsbios_bridge.py]
2026-03-20 Offline gear sim: trigger only on UP↔DN transition, ignore center
    Skip intermediate center state (swGear=0) when detecting landing gear
    changes for offline LED simulation. Only trigger gear LED update and
    Gear Warn when switch settles to UP or DN position.
    [REDKITE_F16_PANELS.ino]
2026-03-21 MISC panel MCP23017: update pin mapping, add ADV LEDs, offline sim
    - Update MCP23017 pin assignments to match actual wiring:
    GPA0-1 Master ARM, GPA2 ALT REL, GPA3 Laser ARM, GPA4-5 RF,
    GPA7 ECM LED, GPB0-1 ADV Active/Standby LEDs, GPB2 ADV MODE,
    GPB3-4 Roll AP, GPB5-6 Pitch AP
    - Add ADV Active/Standby LEDs (LI_ADV_ACTIVE, LI_ADV_STANDBY)
    - Offline sim: ADV Active/Standby alternate at 1s interval
    - Set I2C clock explicitly to 100kHz
    - Bridge: COM4 default port, move GEARHANDLE comment fix
    - Update wiring diagram and all docs
    [REDKITE_F16_PANELS.ino, bmsbios_bridge.py]
2026-03-21 BMS bridge: add ADV Active/Standby LED mapping, fix ECM bit
    - ADV Active: LightBits2 bit 29 (0x20000000)
    - ADV Standby: LightBits bit 31 (0x80000000) — separate bit, not inverted
    - ECM: LightBits2 bit 16 (was LightBits bit 26)
    - Fix stale offset comments (240→124, 244→128)
    - Add shm_scan.py snapshot comparison tool for discovering SHM bits
    - Update protocol_reference.txt and joystick.txt with correct mappings
    [REDKITE_F16_PANELS.ino, bmsbios_bridge.py, shm_scan.py]
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2026-03-29 DCS-BIOS: add ADV LED mapping, sequential gear sim, calibration fixes
    - DCS-BIOS: map ADV Active (0x447E bit2) and Standby (0x447E bit3)
    - DCS-BIOS: add --debug flag to bridge for 0x447E monitoring
    - DCS-BIOS: default COM4, turnOffAllLeds on protocol detection
    - Offline sim: sequential gear LEDs (nose→left→right, 0.5s interval)
    - Calibrate CMDS MODE/PRGM ADC values from actual measurements
    - CMDS MODE tolerance 15→25
    [DcsBiosParser.h, REDKITE_F16_PANELS.ino, dcsbios_bridge.py]
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2026-03-31 Update README: add MCU/Components/Cost sections, add order Excel files
    - Add MCU section explaining Teensy 4.1 selection
    - Reorganize Components by category based on AliExpress orders
    - Update cost summary with accurate totals, separate shipping column
    - Add "nice to have" section (TM MFD, Simgears ICP, TEK Creations panels)
    - Add Enclosure PETG rationale, Stand version recommendation
    - Fix typos, rename Requirements to Hardware
    - Add order history Excel files (PCFlights, JLC3DP, PCBWay, AliExpress)
    - Add Alibaba LCD contract PDF
    [AliExpress_Orders.xlsx, JLC3DP_Orders.xlsx, PCBWay_Orders.xlsx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]
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2026-04-01 Replace resistor ladder PNG with SVG HTML diagram, remove unused files
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2026-04-03 MCP hotplug, welcome ceremony, idle timeout, DCS bridge debug
    - MCP hotplug: detect disconnect (I2C fail → mcpConnected=false),
    auto-reconnect every 500ms, MISC LED ceremony on reconnect
    - Gear Warn LED stays on while MCP disconnected
    - Welcome ceremony on boot (setup)
    - Idle timeout: 30min (1000*60*30)
    - DCS bridge: add --debug flag, argparse, default COM4
    - DCS bridge: parse 0x447E for ADV/TWA debug output
    [REDKITE_F16_PANELS.ino]
2026-04-04 Add in-game backlight sync, fix DCS-BIOS carousel stale value issue
    BMS: read instrLight from FlightData2 (shm2, offset 1104), send as bit 16
    DCS: parse LIGHT_INST_PNL (0x4484), control backlight on value > 0
    DCS bridge: filter carousel resync by default (--raw for original behavior)
    — carousel was overwriting fresh changes with stale values
    Fix DCS-BIOS UDP parser sync header (0x55x4) misidentified as frame end
    [DcsBiosParser.h, bmsbios_bridge.py, dcsbios_bridge.py]
2026-05-17 DCS-BIOS parser resync robustness, pedal calibration reset, bridge reconnect fix
    - DCS-BIOS parser: add intra-frame timeout, mid-stream resync detector,
    address/count sanity checks to recover from desync
    - Pedal: add calibration reset (both pedals + DN LOCK REL held 2s),
    fix divide-by-zero on equal min/max, add debug logging
    - dcsbios_bridge: clear change filter on reconnect so Teensy gets full state
    - Add CLAUDE.md project instructions
    [DcsBiosParser.h, REDKITE_F16_PANELS.ino, dcsbios_bridge.py]
2026-05-20 Add offline manual backlight control (DN LOCK REL + Landing Light switch)
    When offline, holding DN LOCK REL and flipping Landing Light to OFF turns
    backlight off; flipping to TAXI/LANDING turns it back on. Bridge reconnect
    always restores backlight regardless of manual state.
    [REDKITE_F16_PANELS.ino]
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2026-05-26 Add Teensy 4.0 ECM+ELEC panel project, refactor DN LOCK REL index
    - ecm_elec/: standalone Teensy 4.0 USB joystick for ECM + ELEC panels
    - ECM: OPR/STBY, XMIT 1/2/3 switches, 8-button resistor ladder
    - ECM: 32 S/A/F/T LEDs via 74HC595 x4 daisy-chain
    - ELEC: MAIN PWR switch, 9 indicator LEDs (direct GPIO)
    - Main sketch: replace hardcoded DN LOCK REL index with SW_IDX_DN_LOCK_REL define
    [REDKITE_F16_PANELS.ino]
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2026-06-03 Add welcome on bridge/input wake, USB suspend improvements, unique PID
    - Welcome ceremony on offline→online transition (bridge connect)
    - Welcome on switch input after USB suspend resume
    - ECM welcome: all groups sweep S→A→F→T simultaneously (0.5s per column)
    - Fix duplicate welcome on startup (wasOffline init to false)
    - Add PRODUCT_ID 0x048E build check to distinguish from Left Aux Misc
    - Include usb_desc.h path in build error/warning messages
    - Rewrite CLAUDE.md to reflect all current features
2026-06-03 Add PRODUCT_ID build check, fix name.c char count, update CLAUDE.md
    - Add PRODUCT_ID 0x0487 build check to prevent PID misconfiguration
    - Fix name.c char count (24→25 for "Redkite F16 Left Aux Misc")
    - Include usb_desc.h path in build error messages
    - Update CLAUDE.md: rename .ino references, add USB suspend and
    welcome ceremony documentation
    [REDKITE_F16_LEFT_AUX_MISC.ino]
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2026-06-04 Consolidate docs to top-level, move README to monorepo root
    - Move all docs from sub-projects to docs/
    - Move LEFT_AUX_MISC README.md to top-level README.md
    - Update doc path references in CLAUDE.md files
    [AliExpress_Orders.xlsx, JLC3DP_Orders.xlsx, PCBWay_Orders.xlsx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]
2026-06-04 Move shared assets to top level, fix README paths for monorepo
    - Move My Cockpit.png, 3d stl/, LICENSE to repo root
    - Update README: fix .ino filename, tools/ -> Bios/, project structure
    [Enclosure - OnePiece2.stl, Left Stand - new.stl, Left Stand.stl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]
2026-06-05 Move 3d stl/ under docs/, update README paths
    [Enclosure - OnePiece2.stl, Left Stand - new.stl, Left Stand.stl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]
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2026-06-05 Replace cockpit photo with updated version (My Cockpit3)
    [My Cockpit3.xlsx]
2026-06-05 Rewrite reset_joystick_name as polyglot bat/ps1 with full PnP cleanup
    Previous bat scripts only cleared Joystick OEM registry cache, which
    was insufficient — joy.cpl still showed stale names. New script also
    removes USB/HID PnP device entries via pnputil, forcing Windows to
    re-read USB descriptors on reconnect.
    - Delete update_joystick_name.bat (redundant)
    - Delete docs/joystick_name_cache.md (obsolete)
    - Rewrite reset_joystick_name.bat as polyglot bat/PowerShell
    (bat handles admin elevation, PS handles registry + pnputil)
2026-06-06 Calibrate analog button values and add 8x ADC averaging
    Resistor ladder values drifted from theoretical calculations.
    Updated all three groups (TWA, MODE, PRGM) with measured values.
    Added 8-sample averaging to analogRead to reduce noise-induced
    flickering on TWA buttons.
    Also fix USB product name typo (MISc → MISC).
    [REDKITE_F16_LEFT_AUX_MISC.ino]
2026-06-06 Rename LEFT_CONSOLE to ELEC_ECM_AVTR, remove old files, add tools
    - Rename REDKITE_F16_LEFT_CONSOLE/ → REDKITE_F16_ELEC_ECM_AVTR/
    (update PID to 0x048E in name.c)
    - Remove duplicate REDKITE_F16_PANELS.ino
    - Remove obsolete My Cockpit3.xlsx
    - Update bridge PID references for ELEC_ECM_AVTR
    - Add JoystickTest.exe and tools/readme.txt
    [My Cockpit3.xlsx]
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2026-06-06 Fix TWA button name order (ACT/PWR is first position)
    [REDKITE_F16_LEFT_AUX_MISC.ino]
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2026-06-10 Fix DCS-BIOS ELEC panel LED addresses from F-16C_50.json
    - Corrected all ELEC caution light addresses/masks (were completely wrong)
    - 0x447C: FLCS PMG, MAIN GEN, STBY GEN, EPU GEN, EPU PMG, TO FLCS
    - 0x447E: FLCS RLY, BATT FAIL
    - Fixed ELEC LED pin assignments (BATT FAIL=8, BATT TO FLCS=9, FLCS RLY=10)
    - Muted noisy DCS parser debug logs (resync, ECM, analog buttons)
    [DcsBiosParser.h, REDKITE_F16_ELEC_ECM_AVTR.ino]
2026-06-13 Fix BMS bridge ELEC LED mapping to LightBits3 from FlightData.h
    - ELEC panel LEDs were mapped to LightBits2 but actually reside in LightBits3
    - Added BATT FAIL and TO FLCS mappings (previously unmapped)
    - Verified against BMS 4.38 FlightData.h
    [REDKITE_F16_ELEC_ECM_AVTR.ino, bmsbios_bridge.py]
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2026-08-16 Rename sketch folders, remap MCP pins, fix pin conflicts, add DCS-BIOS EPU/JFS LEDs
    - Rename REDKITE_F16_* folders to F16_* (old folders kept as deprecated)
    - LEFT_CONSOLE: move ECM switches from MCP#2 GPA to GPB (PB2-PB7)
    - LEFT_CONSOLE: reverse ELEC LED order on MCP#1 (FLCS PMG=PB7, BATT FAIL=PB2, TO FLCS=PB1, FLCS RLY=PB0)
    - LEFT_CONSOLE: update ELEC switch labels (PA0=MAIN, PA1=OFF)
    - LEFT_CONSOLE: add DCS-BIOS EPU HYDRAZN/AIR/RUN + JFS RUN LED mapping (0x447C)
    - LEFT_AUX_MISC: fix pin 27 conflict — move Gear Warn LED to pin 12
    - LEFT_AUX_MISC: swap backlight (pin 0→13) and ALT GEAR Reset (pin 13→0)
    - Update PIN_TREE docs, CLAUDE.md, and bridge scripts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
    [DcsBiosParser.h, F16_LEFT_AUX_MISC.ino, F16_LEFT_CONSOLE.ino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]
2026-09-25 LEFT_CONSOLE: PWM backlight, manual dimming, axis reorder, pin fixes, cleanup deprecated
    - PWM backlight dimming via MOSFET on pin 13 (1kHz analogWrite)
    - BMS bridge: adaptive brightness (DIM=255 default, DIM=50 after BRT detected)
    - DCS: Teensy direct LIGHT_INST_PNL → PWM 0~255
    - Offline manual brightness: UHF STATUS + TF pot
    - Reorder pot axes (COM1/COM2/MSL/THREAT/INTERCOM/UHF VOL priority)
    - Fix setJoystickAxis compile error (use public API instead of private analog16)
    - Remove UHF TEST (not connected), move UHF STATUS to pin 41
    - Swap UHF PRESET encoder CW/CCW direction
    - Reorder MCP#1 PA0~PA7 LED assignments to match physical wiring
    - Fix AUDIO COMM1/COMM2 rotary pin order (split to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
    [DcsBiosParser.h, F16_LEFT_AUX_MISC.ino, F16_LEFT_CONSOLE.ino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]
2026-09-25 Remove debug code, fix HID slider via usb_desc.c padding
    - Remove debugDigitalInputs(), fmtPin(), encoder/ladder debug output
    - usb_desc.c (system file, not tracked): Report Count 23→8 + 15 constant
    padding to fix DirectInput slider recognition (0x36 ×17 duplicate caused
    DirectInput to ignore all sliders; 8 variable + 15 padding = 8 axes OK)
    [F16_LEFT_CONSOLE.ino]
2026-09-25 Add Teensyduino upgrade docs and auto-patch scripts
    Document usb_desc.c HID slider fix and axis mapping in PIN_ASSIGNMENT.
    Add teensyduino_upgrade.md guide for post-update patching.
    Add patch_usb_desc_h.py (JOYSTICK_SIZE + PID) and patch_usb_desc_c.py
    (slider Report Count 23→8 + 15 padding) for automated patching.
    [patch_usb_desc_c.py, patch_usb_desc_h.py]
2026-10-01 Hat neutral fix, DCS cover automation, EPU/ELEC pin swap, AVTR remap
    - Fix hat(num, -1) using 360 for neutral (2-arg -1 maps to NE, not center)
    - Add DCS cover automation: DX 59-61 (ENG CONT, EPU OFF/ON covers)
    Cover leads switch ON by 100ms, lags switch OFF by 100ms
    - Swap EPU (DX 7-8, GPB0/1) and ELEC MAIN PWR (DX 16-17, GPB6/7)
    to match physical wiring
    - Move EPU RUN LED to MCP 0x22 GPA7 (0x21 GPB5 pin defect)
    - Remap AVTR switch to MCP 0x22 GPB0/GPB1 (UNTHRD/RECORD/EVENT MRK)
    - Update LEFT_CONSOLE CLAUDE.md with PWM backlight, cover automation,
    HID patch docs, axis mapping details
    - Remove unused encoder variable warning
    [F16_LEFT_AUX_MISC.ino, F16_LEFT_CONSOLE.ino]
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2026-10-06 Add CMDS GO/NO GO/RDY lamps on LEFT_AUX bottom SD pads
    Six LEDs driven 1:1 from Teensy pins 42-47, broken out with a microSD
    extension cable. No header pins consumed and no existing pin assignment
    changed; the HMCS pots stay as they are.
    BMS supplies only three EWS signals, so AUX_LED_MAP maps one lightBits2
    bit to several leds[] indices - NO GO to two, RDY to three - and a group
    always lights together. No grouping logic in the firmware.
    GO 1 LED pin 42 Go 0x40
    NO GO 2 LEDs pins 43,44 NoGo 0x80
    RDY 3 LEDs pins 45,46,47 Rdy 0x200
    LEDs run straight off 3.3V with individual series resistors, so keep Vf
    under ~3.0V. Frame length and checksum are unchanged - t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
    [F16_LEFT_AUX_MISC.ino, bmsbios_bridge.py]
2026-10-06 Stagger console welcome ceremony, document LED current budget
    welcomeCeremony() lit all 44 LEDs at once in its blink phase. Replace that
    with ecmSweep(), which drives ECM one column (S/A/F/T) at a time - 8 LEDs
    spread exactly 2 per 74HC595, verified against srMap. Peak drops from 44
    LEDs to 20 (panel 12 + ECM 8), about 200mA to 90mA. The opening sweep now
    uses the same helper.
    Document the measured budget: every LED uses a 220 ohm resistor at 3.3V,
    giving ~4.5mA through the '595s, ~4.1mA through the MCP23017s and ~5.1mA
    on a direct Teensy pin - roughly 200mA with everything lit, about 80% of
    the regulator's ~250mA for external loads. It fits, with no margin to add
    LEDs or lower the resistor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
    [F16_LEFT_CONSOLE.ino]
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2026-10-06 Revert "Drop the dead *.stl rule from .gitignore"
    This reverts commit c56fda1. The rule was not dead - it was keeping
    docs/3d stl/My Cockpit3.stl (71.49 MB) out of the repository. Removing it
    surfaced that file as untracked, which would have taken the repo from
    9.75 MB to over 80 MB and tripped GitHub's 50 MB per-file warning.
    The original setup was deliberate and correct: the five small STLs were
    committed before the rule existed and stay tracked because git ignores
    .gitignore for already-tracked paths, while the one large model is kept
    out. Restoring it.
2026-10-09 Backlight PWM dimming for LEFT_AUX, manual brightness via UHF VOL for LEFT_CONSOLE
    - LEFT_AUX_MISC: change backlight from ON/OFF to PWM dimming (BMS byte 2, DCS >>8)
    - LEFT_AUX_MISC: manual brightness via DN LOCK REL + HMCS Symbology pot (reversed)
    - LEFT_CONSOLE: change manual backlight control from TF pot to UHF VOL
    [DcsBiosParser.h, F16_LEFT_AUX_MISC.ino, F16_LEFT_CONSOLE.ino]
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2026-10-10 Add NC switch type, LAN wiring doc, update README for current state
    - LEFT_AUX_MISC: add SW_ON_OFF_NC for ALT REL (normally closed, inverted DX)
    - LEFT_AUX_MISC: restore backlight PWM dimming (remove always-full override)
    - docs: add LEFT_AUX_MISC_LAN_WIRING.md (AUX↔MISC LAN cable pinout)
    - README: update PID 0x0489, add HMCS/CMDS lamps/DCS covers, PWM dimming,
    manual brightness controls, BMS 16-byte frame, project structure
    [F16_LEFT_AUX_MISC.ino]
2026-10-13 Recalibrate resistor ladders, unify BL OFF/ON values
    - LEFT_AUX_MISC: merge BL OFF/ON ladder values into single array (±4 identical)
    - LEFT_AUX_MISC: reject threshold changed to raw < 100 (noise floor)
    - LEFT_CONSOLE: merge BL OFF/ON struct, recalibrate ECM 8-button values
    - LEFT_CONSOLE: add ladder debug output (guarded by ALLOW_DEBUG)
2026-10-15 Remove unused hardware (ALT GEAR Reset, HMCS Brightness/Contrast), update PIN_TREE
    - Remove ALT GEAR Reset (pin 0), HMCS Brightness (A13), HMCS Contrast (A14) from code
    - DX buttons 52→51 (ALT GEAR Reset removed, subsequent DX shifted down by 1)
    - Axes 6→4 (only HMCS Symbology + pedals remain)
    - Fix axis table pin numbers (A15=39, A17=41)
    - Update cable tree diagram: ALT GEAR SW x2→x1, HMCS POT x3→x1
    - Mark removed pins as spare in pin diagram
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2026-10-15 Restructure README as step-by-step assembly guide
    Reorganize from topic-based to sequential flow:
    1. 준비물 (panels, enclosures, MCU, BOM, cost)
    2. 개발 환경 설정 (Arduino IDE, usb_desc.h)
    3. 배선 (pin docs, resistor ladders, MCP23017, backlight)
    4. 펌웨어 업로드
    5. 소프트웨어 설정 (Python bridges)
    6. 테스트 & 캘리브레이션
    Also: remove broken links to deleted docs, update panel specs
    to current state, consolidate duplicated content.
2026-10-15 AUX backlight: Step-Up → separate 12V adapter (ADC noise fix)
    Step-Up 5V→12V caused ~30-count shifts on resistor ladder ADC readings
    and switch flickering. Both boards now use separate 12V adapters.
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2026-10-15 CMDS EWS: rework 8 LEDs on 5 SD-pad pins (µSD order), 320Ω resistors
    - 4 signal types: NO GO(2), GO(1), DISP(3 on 2 pins), RDY(2)
    - Pin assignment follows microSD pin order (1→2→3→5→7), pin 46 spare
    - Resistor: 320Ω (220+100 series), ~4.1mA/LED, ~8.1mA/pin for pairs
    - Bridge: add LB2_EWS_DISP (bit 8), reorder AUX_LED_MAP
    - Docs: merge SD pad table into CMDS lamp section, remove dead links
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2026-10-16 Bridge: add Cougar MFD backlight sync via HID
    - Auto-detect F16 MFD 1/2 (VID 0x044F, PID 0xB351/B352)
    - Sync instrLight brightness (0-255) to MFDs alongside Teensy panels
    - hidapi is optional: bridge works without it, prints install hint
    - Docs: add hidapi to pip install, note MFD sync in README
    - PIN_TREE: fix axis count (1→4)
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2026-10-18 Offline backlight: Teensy 20%, MFD off on sim/bridge exit
    - Teensy: resetProtocol() sets backlight to 20% (PWM 51) on bridge offline
    - Bridge: MFD backlight off when sim exits (SHM error / UDP timeout)
    - Bridge: MFD backlight off on close() for clean Ctrl+C shutdown
    - Bridge: SetConsoleCtrlHandler to turn off MFD on console window close
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2026-10-21 Fix SD pad mapping, reorder CMDS lamps, map DISPENSE to Rdy
    The microSD-to-Teensy mapping was wrong in both the code comments and the
    pin-tree docs. Checked against docs/teensy/card11b_rev4_web.pdf, whose SD
    Card block lists the socket contacts in physical order: microSD 1-8 maps to
    47, 46, 45, 3.3V, 44, GND, 43, 42. The socket is wired for SDIO, so the SPI2
    names on those pins do not line up with the SD signal names - CMD sits on
    SCK2 and DAT0 on MOSI2. Both docs now carry SDIO and SPI2 as separate
    columns, with the 15-pin FPC conductor numbers alongside.
    Under the corrected mapping the previous "microSD 1->2->3->7->8" layouts
    were not sequential at all. CMDS lamp pins are reassigned so th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
2026-10-21 Drop HAS_UHF_DISPLAY; the UHF display is always built in
    The flag guarded seven blocks across the sketch and the BMS parser - the
    include, displayBegin() in setup, the ceremony lamp test and its dash
    restore, the offline dashes in resetProtocol(), displayOn(false) on USB
    suspend, and the frequency/channel write in bmsBiosApply(). All of them are
    now unconditional.
    Nothing stops the SPI2 writes when no display board is attached; they just
    clock out into nothing, so pins 43, 45 and 46 toggle whether or not the
    board is there.
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2026-10-21 Turn off UHF display when bridge is offline (burn-in prevention)
    Replace displayDashes() with displayOn(false) in setup, after
    welcome ceremony, and in resetProtocol(). The display powers back
    on automatically when bridge data arrives.
